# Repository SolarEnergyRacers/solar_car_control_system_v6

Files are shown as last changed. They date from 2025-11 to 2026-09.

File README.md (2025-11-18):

# solar_car_control_system_v6

[solarenergyracers.ch](https://www.solarenergyracers.ch) - control system (multi controller based control system for SER v6 solar car)

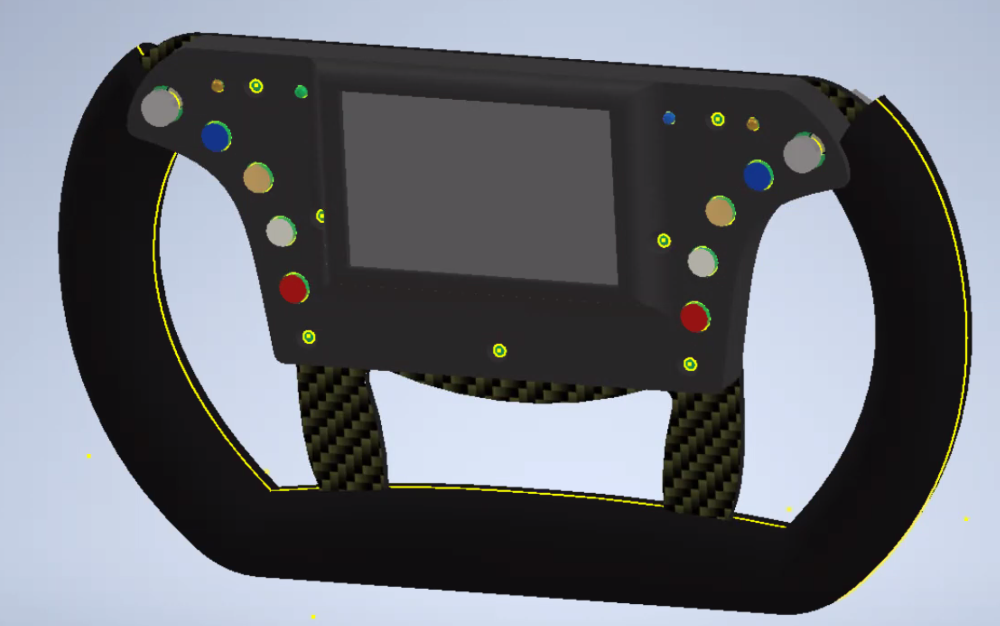
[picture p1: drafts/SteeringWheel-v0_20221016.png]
steering wheel


## Folder Structure

```Text
.
├── AC
│   ├── CMakeLists.txt
│   ├── dependencies.lock
│   ├── lib
│   │   ├── CarControl
│   │   ├── CarState
│   │   ├── CmdHandler
│   │   ├── ConfigReader
│   │   ├── Console
│   │   ├── definitions.h
│   │   ├── Display
│   │   ├── DisplayValue
│   │   ├── DriverDisplay
│   │   ├── EngineerDisplay
│   │   ├── GPIO
│   │   ├── interfaces
│   │   ├── LocalFunctionsAndDevices.h
│   │   ├── OneWireBus
│   │   ├── placeholder.txt
│   │   ├── SDCard
│   │   └── SPIBus
│   ├── platformio.ini
│   ├── sdkconfig
│   ├── sdkconfig.defaults
│   ├── sdkconfig.esp32dev
│   ├── sdkconfig.esp32dev-linux
│   ├── sdkconfig.esp32dev-windows
│   ├── ser_v6_AC.code-workspace
│   ├── src
│   │   ├── CMakeLists.txt
│   │   └── main.cpp
│   └── upload_no_build.py
├── archive_logs.py
├── data
├── datasheets
├── DC
│   ├── CMakeLists.txt
│   ├── dependencies.lock
│   ├── lib
│   │   ├── ADC
│   │   ├── CAN
│   │   ├── CarControl
│   │   ├── CarState
│   │   ├── CmdHandler
│   │   ├── ConstSpeed
│   │   ├── DAC
│   │   ├── definitions.h
│   │   ├── GPIO
│   │   ├── IOExt
│   │   ├── LocalFunctionsAndDevices.h
│   │   ├── OneWireBus
│   │   └── SPIBus
│   ├── platformio.ini
│   ├── sdkconfig
│   ├── sdkconfig.defaults
│   ├── sdkconfig.esp32dev
│   ├── sdkconfig.esp32dev-linux
│   ├── sdkconfig.esp32dev-windows
│   ├── ser_v6_DC.code-workspace
│   ├── src
│   │   ├── CMakeLists.txt
│   │   └── main.cpp
│   └── upload_no_build.py
├── PCBs
│   ├── AuxController
│   ├── ChassisBoard
│   ├── DriveController
│   ├── PDFs_Images
│   └── SwitchBoard
├── docs
├── drafts
├── extras
├── fixes_for_librarys
│   ├── core.h
│   ├── fixes.md
│   └── rtc.h
├── lib_common
│   ├── CAN
│   ├── Console
│   ├── Helper
│   ├── I2CBus
│   ├── include
│   ├── interfaces
│   ├── RTC
│   ├── Serial
│   └── System
├── platformio.txt
├── README.md
├── reset_usb_numbering.py
└── start-vscode-for-AC-DC-workspace.py

```

## Drafts

- SteeringWheel
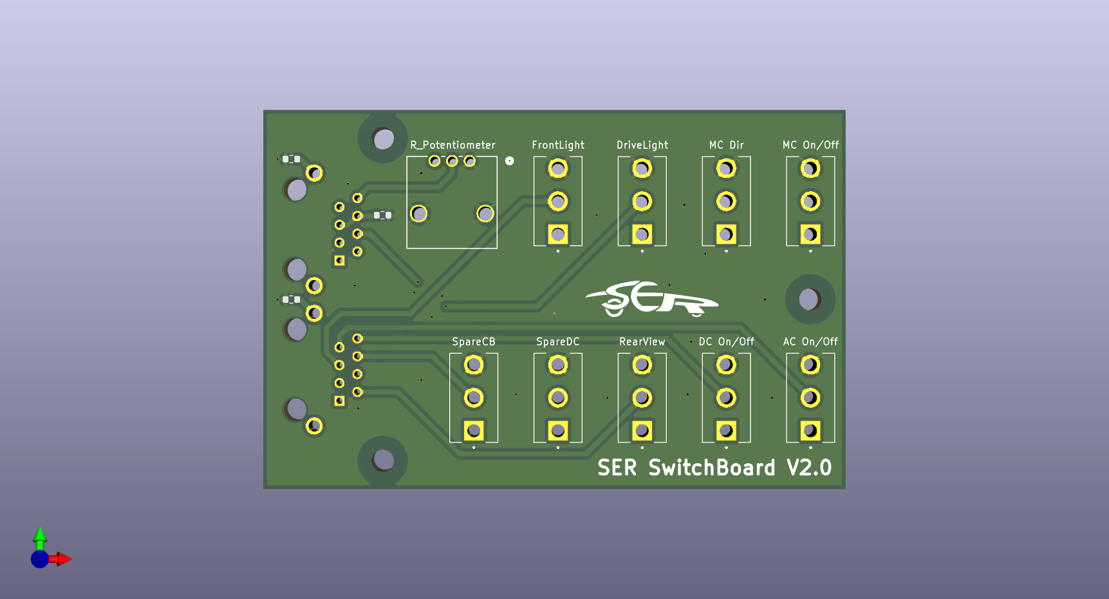
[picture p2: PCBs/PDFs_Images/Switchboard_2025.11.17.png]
Switchboard
- 
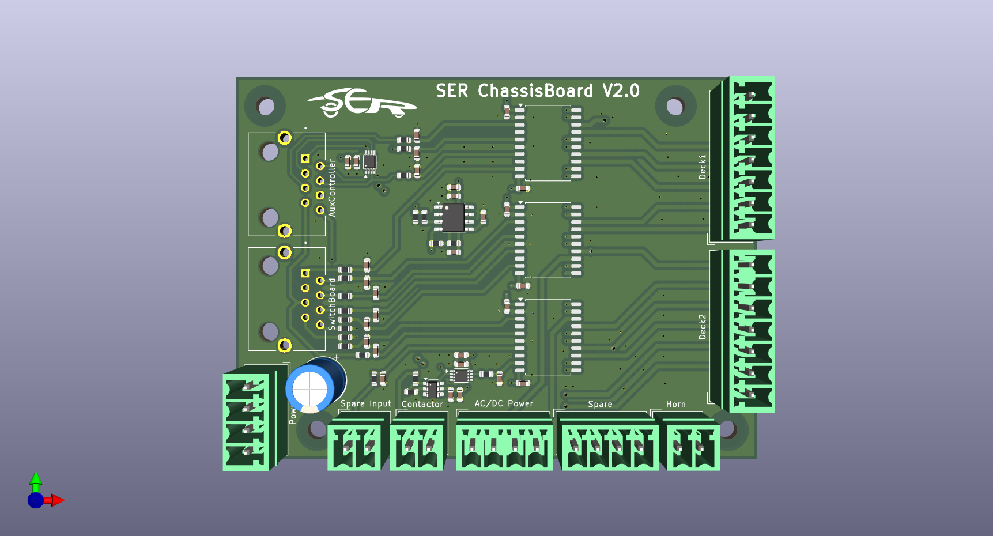
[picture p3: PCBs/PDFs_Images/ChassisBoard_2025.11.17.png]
ChassisBoard
- 
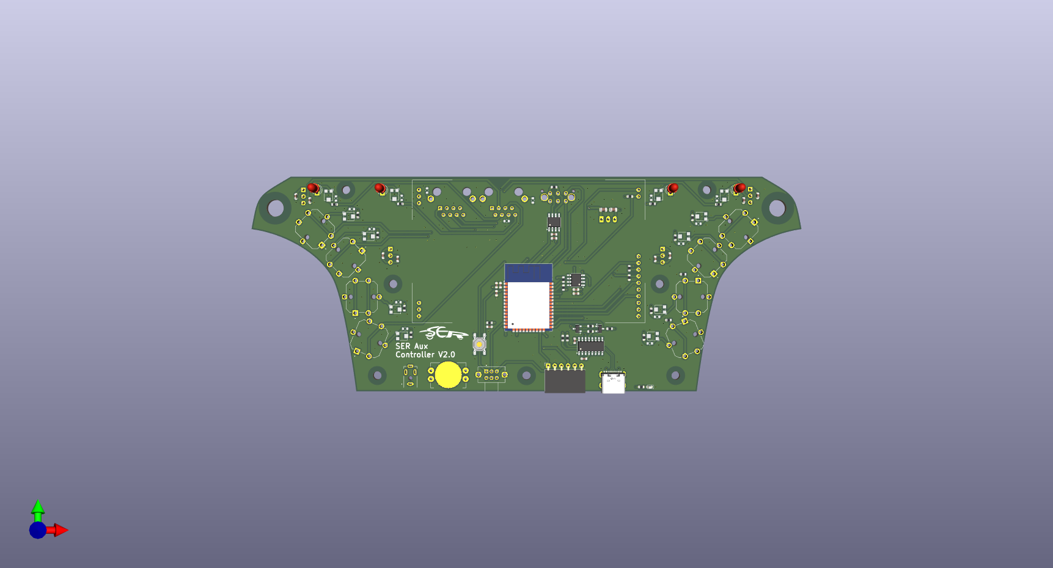
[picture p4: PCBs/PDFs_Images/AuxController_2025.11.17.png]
AuxController
- 
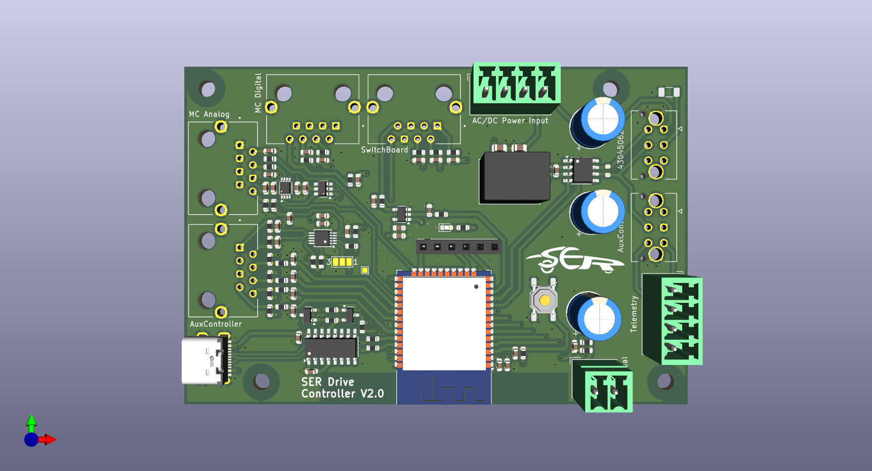
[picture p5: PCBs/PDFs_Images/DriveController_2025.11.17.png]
DriveController
- 

## Docs

- [Signal Flows](docs/SignalFlows.md)
- [CAN Signal](docs/SignalFlows_CAN-Definitions.md)

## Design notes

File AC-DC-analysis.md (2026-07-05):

# AC/DC Control System Reliability Analysis

## Scope

This document focuses on CAN communication reliability between AC and DC controllers in SER6.

Primary requirement:

- AC<->DC control exchange is critical and should not be silently lost.

Secondary requirement:

- Other CAN participants (BMS, MPPT, and additional telemetry) are informational. Packet loss is acceptable because data is sent repeatedly.

## Baseline

Main code locations:

- AC application: `AC/`
- DC application: `DC/`
- Shared CAN stack: `lib_common/CAN/`
- CAN constants: `lib_common/include/global_definitions.h`

Current CAN library in both AC and DC builds:

- `https://github.com/sandeepmistry/arduino-CAN`

Current bitrate:

- `CAN_SPEED = 125E3`

CAN base IDs in code:

- `AC_BASE_ADDR = 0x650`
- `DC_BASE_ADDR = 0x660`
- `BMS_BASE_ADDR = 0x700`
- `MPPT1/2/3_BASE_ADDR = 0x600/0x610/0x620`

## Reliability Classes

Class A (critical, must-not-lose behavior):

- `0x650` (`AC_BASE_ADDR | 0x00`) AC -> DC command/control frame
- `0x660` (`DC_BASE_ADDR | 0x00`) DC -> AC driver input frame
- `0x661` (`DC_BASE_ADDR | 0x01`) DC -> AC target/state frame

Class B (telemetry, loss tolerated):

- BMS frames
- MPPT frames
- Other repeated informational traffic

## Current Critical Data Flow

TX generation:

- AC writes `0x650` in `AC/lib/CarControl/CarControlAC.cpp`.
- DC writes `0x660` and `0x661` in `DC/lib/CarControl/CarControlDC.cpp`.

Transport:

- ISR receive callback in `lib_common/CAN/CANBus.cpp`.
- RX/TX queue handling in `lib_common/CAN/CANRxBuffer.cpp` and `lib_common/CAN/CANBus.cpp`.

RX consumption:

- AC parses `0x660` and `0x661` in `lib_common/CAN/CANBusHandlerAC.cpp`.
- DC parses `0x650` in `lib_common/CAN/CANBusHandlerDC.cpp`.

## Confirmed Findings

### Critical

1. RX queue overwrite can drop critical packets.

- File: `lib_common/CAN/CANRxBuffer.cpp`
- Behavior: oldest packet is removed when queue is full.
- Impact: class A and class B traffic are not separated, so critical frames can be dropped under pressure.

### High

1. TX failure path has no bounded retry policy for critical messages.

- File: `lib_common/CAN/CANBus.cpp`
- Behavior: semaphore timeout or `CAN.endPacket()` failure increments counters and returns.
- Impact: critical packet can be lost without immediate recovery.

1. Dedup logic can keep stale control state after a lost frame.

- File: `lib_common/CAN/CANBus.cpp`
- Behavior: unchanged payload is not re-enqueued unless `force` is true.
- Impact: if a critical frame is lost and value does not change, receiver can stay stale longer.

### Medium

1. Fixed TX service budget can increase queue latency.

- File: `lib_common/CAN/CANBus.cpp`
- Behavior: `MAX_TX_PACKETS_PER_CYCLE = 4`.
- Impact: bursts can delay control updates.

1. Priority handling exists but does not provide end-to-end QoS.

- File: `lib_common/CAN/CANBus.cpp`
- Behavior: critical IDs are prioritized in parts of TX scheduling.
- Impact: no complete guarantee model (critical reservation + retry + stale contract).

## Implementation Started

Implemented now in shared CAN code:

- Added queue overwrite visibility in `CANRxBuffer::push(...)` (returns whether overwrite happened).
- Added counters in `CANBus`:
  - `counterRxOverwrite`
  - `counterTxOverwrite`
  - `counterCriticalTxDrop`
  - `counterCriticalTxFail`
- Added critical TX failure counting for semaphore and `endPacket()` failures.
- Added bounded retry/requeue for critical TX IDs (`0x650`, `0x660`, `0x661`).
- Added critical frame staleness watchdog (`CRITICAL_CAN_STALE_TIMEOUT_MS`) with stale/recovered logs and counter.
- Migrated CAN backend implementation in `CANBus` from arduino-CAN to ESP-IDF TWAI.
- Added critical sequence-gap detection for IDs `0x650`, `0x660`, and `0x661`.
- Added dedicated critical TX queue lane so telemetry queue pressure cannot evict critical frames.
- Extended reinit log output to include new reliability counters.

Changed files:

- `lib_common/CAN/CANRxBuffer.h`
- `lib_common/CAN/CANRxBuffer.cpp`
- `lib_common/CAN/CANBus.h`
- `lib_common/CAN/CANBus.cpp`
- `lib_common/include/global_definitions.h`
- `AC/platformio.ini`
- `DC/platformio.ini`

## Library Assessment

### Previous library: arduino-CAN

Short-term suitability:

- Good integration and low change risk.
- Simple API and already in production code path.

Limitations against class A reliability target:

- Reliability/QoS policy must be implemented mostly in project code.
- Less explicit application-facing control for advanced error-state handling than native ESP-IDF TWAI APIs.

### Selected target: ESP-IDF TWAI backend

Decision implemented:

1. CAN transport in `CANBus` now uses ESP-IDF TWAI APIs.
1. Build dependencies for arduino-CAN were removed from AC/DC platformio config.

Rationale:

- Better error/state visibility.
- Better recovery integration.
- Better long-term fit for must-not-lose control path requirements.

## Next Implementation Steps

1. Add critical staleness timeout policy for `0x650`, `0x660`, and `0x661`.
1. Add optional backend abstraction layer only if dual-backend support is needed.

## Validation Gates

1. No undetected stale class A state beyond defined timeout budget.
2. Class A drop/failure counters visible during stress tests.
3. Injected TX failures trigger deterministic retry/recovery behavior.
4. Class B packet loss does not impact control correctness.

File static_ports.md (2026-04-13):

# Static USB Port Assignment for ESP32 Boards

## Check it

`ll /dev/ttyU* ; ll /dev/esp32-*`

## Explore it

```bash
udevadm info -a -n /dev/ttyUSB1 > ac.udevadm.log
udevadm info -a -n /dev/ttyUSB1 > dc.udevadm.log
code ac.udevadm.log dc.udevadm.log 
```

## Set it

```bash
sudo nano /etc/udev/rules.d/99-esp32.rules
```

```rules
# Rule for first ESP32 board (plugged into port with KERNELS 1-1.2)
SUBSYSTEM=="tty", ATTRS{idVendor}=="1a86", ATTRS{idProduct}=="7523", KERNELS=="1-2", SYMLINK+="esp32-ac"

# Rule for second ESP32 board (plugged into port with KERNELS 1-1.3)
SUBSYSTEM=="tty", ATTRS{idVendor}=="1a86", ATTRS{idProduct}=="7523", KERNELS=="1-1", SYMLINK+="esp32-dc"

```

```bash
sudo udevadm control --reload-rules && sudo udevadm trigger
```

If both ESP32 boards report identical attributes (e.g., the same ATTRS{serial}, ATTRS{idVendor}, and ATTRS{idProduct}), that's common for identical hardware. We can't rely on device-specific attributes for uniqueness, but we can use port-specific attributes from the USB hierarchy (like the physical USB port path) to distinguish them. This requires plugging each board into a different USB port and matching on the KERNELS or DEVPATH attribute, which represents the device's position in the USB tree.

Updated Steps to Create Unique udev Rules

Plug in only one ESP32 board to a specific USB port (e.g., the leftmost port on your hub or motherboard). Note which port you're using.

Identify the device and get full attributes:

Find the assigned /dev/ttyUSB* device:

`ls /dev/ttyUSB*`

(Assume it's /dev/ttyUSB0 for this example.)

Get the full udev info:

`udevadm info -a -n /dev/ttyUSB0`

Look for lines like:

```bash
KERNELS=="1-1.2"  # This is the USB port path (varies by port)DEVPATH=="/devices/pci0000:00/0000:00:14.0/usb1/1-1/1-1.2/1-1.2:1.0/ttyUSB0/tty/ttyUSB0"
The KERNELS value (e.g., 1-1.2) is key—it's unique to the physical port. Copy this value for the first board.
Unplug the first board, plug in the second board to a different USB port (e.g., the next port over). Repeat step 2 to get its KERNELS value (e.g., 1-1.3).
```

Create or update the udev rules file (as root):

`sudo nano /etc/udev/rules.d/99-esp32.rules`

Use the KERNELS values to make rules unique. Example (replace with your actual values):

```bash
# Rule for first ESP32 board (plugged into port with KERNELS 1-1.2)SUBSYSTEM=="tty", ATTRS{idVendor}=="1a86", ATTRS{idProduct}=="7523", KERNELS=="1-1.2", SYMLINK+="esp32-ac1"
# Rule for second ESP32 board (plugged into port with KERNELS 1-1.3)SUBSYSTEM=="tty", ATTRS{idVendor}=="1a86", ATTRS{idProduct}=="7523", KERNELS=="1-1.3", SYMLINK+="esp32-ac2"
```

If KERNELS isn't reliable (e.g., if ports are on different hubs), use DEVPATH instead (match the full path up to the tty device).
Save and exit.

Reload and test:

Reload rules:

`sudo udevadm control --reload-rules && sudo udevadm trigger`

## Static USB Ports for ESP32 Boards

Based on udevadm info for one ESP32 board (plugged into a specific port). Use KERNELS or other unique attributes to create udev rules for persistent naming.

**Note:** This log shows KERNELS=="1-1", which is the same as the first board. To distinguish, plug each board into different USB ports (e.g., different physical ports on your hub or motherboard) so KERNELS differs (e.g., 1-1 for one, 1-2 for the other).

---

Udevadm info starts with the device specified by the devpath and then
walks up the chain of parent devices. It prints for every device
found, all possible attributes in the udev rules key format.
A rule to match, can be composed by the attributes of the device
and the attributes from one single parent device.

```bash
  looking at device '/devices/pci0000:00/0000:00:14.0/usb1/1-1/1-1:1.0/ttyUSB1/tty/ttyUSB1':
    KERNEL=="ttyUSB1"
    SUBSYSTEM=="tty"
    DRIVER==""
    ATTR{power/async}=="disabled"
    ATTR{power/control}=="auto"
    ATTR{power/runtime_active_kids}=="0"
    ATTR{power/runtime_active_time}=="0"
    ATTR{power/runtime_enabled}=="disabled"
    ATTR{power/runtime_status}=="unsupported"
    ATTR{power/runtime_suspended_time}=="0"
    ATTR{power/runtime_usage}=="0"

  looking at parent device '/devices/pci0000:00/0000:00:14.0/usb1/1-1/1-1:1.0/ttyUSB1':
    KERNELS=="ttyUSB1"
    SUBSYSTEMS=="usb-serial"
    DRIVERS=="ch341-uart"
    ATTRS{port_number}=="0"
    ATTRS{power/async}=="enabled"
    ATTRS{power/control}=="auto"
    ATTRS{power/runtime_active_kids}=="0"
    ATTRS{power/runtime_active_time}=="0"
    ATTRS{power/runtime_enabled}=="disabled"
    ATTRS{power/runtime_status}=="unsupported"
    ATTRS{power/runtime_suspended_time}=="0"
    ATTRS{power/runtime_usage}=="0"

  looking at parent device '/devices/pci0000:00/0000:00:14.0/usb1/1-1/1-1:1.0':
    KERNELS=="1-1:1.0"
    SUBSYSTEMS=="usb"
    DRIVERS=="ch341"
    ATTRS{authorized}=="1"
    ATTRS{bAlternateSetting}==" 0"
    ATTRS{bInterfaceClass}=="ff"
    ATTRS{bInterfaceNumber}=="00"
    ATTRS{bInterfaceProtocol}=="02"
    ATTRS{bInterfaceSubClass}=="01"
    ATTRS{bNumEndpoints}=="03"
    ATTRS{physical_location/dock}=="no"
    ATTRS{physical_location/horizontal_position}=="right"
    ATTRS{physical_location/lid}=="no"
    ATTRS{physical_location/panel}=="left"
    ATTRS{physical_location/vertical_position}=="lower"
    ATTRS{power/async}=="enabled"
    ATTRS{power/runtime_active_kids}=="0"
    ATTRS{power/runtime_enabled}=="enabled"
    ATTRS{power/runtime_status}=="suspended"
    ATTRS{power/runtime_usage}=="0"
    ATTRS{supports_autosuspend}=="1"

  looking at parent device '/devices/pci0000:00/0000:00:14.0/usb1/1-1':
    KERNELS=="1-1"
    SUBSYSTEMS=="usb"
    DRIVERS=="usb"
    ATTRS{authorized}=="1"
    ATTRS{avoid_reset_quirk}=="0"
    ATTRS{bConfigurationValue}=="1"
    ATTRS{bDeviceClass}=="ff"
    ATTRS{bDeviceProtocol}=="00"
    ATTRS{bDeviceSubClass}=="00"
    ATTRS{bMaxPacketSize0}=="8"
    ATTRS{bMaxPower}=="98mA"
    ATTRS{bNumConfigurations}=="1"
    ATTRS{bNumInterfaces}==" 1"
    ATTRS{bcdDevice}=="0264"
    ATTRS{bmAttributes}=="80"
    ATTRS{busnum}=="1"
    ATTRS{configuration}==""
    ATTRS{devnum}=="33"
    ATTRS{devpath}=="1"
    ATTRS{idProduct}=="7523"
    ATTRS{idVendor}=="1a86"
    ATTRS{ltm_capable}=="no"
    ATTRS{maxchild}=="0"
    ATTRS{physical_location/dock}=="no"
    ATTRS{physical_location/horizontal_position}=="right"
    ATTRS{physical_location/lid}=="no"
    ATTRS{physical_location/panel}=="left"
    ATTRS{physical_location/vertical_position}=="lower"
    ATTRS{power/active_duration}=="14812"
    ATTRS{power/async}=="enabled"
    ATTRS{power/autosuspend}=="2"
    ATTRS{power/autosuspend_delay_ms}=="2000"
    ATTRS{power/connected_duration}=="14811"
    ATTRS{power/control}=="on"
    ATTRS{power/level}=="on"
    ATTRS{power/persist}=="1"
    ATTRS{power/runtime_active_kids}=="0"
    ATTRS{power/runtime_active_time}=="14304"
    ATTRS{power/runtime_enabled}=="forbidden"
    ATTRS{power/runtime_status}=="active"
    ATTRS{power/runtime_suspended_time}=="0"
    ATTRS{power/runtime_usage}=="1"
    ATTRS{product}=="USB Serial"
    ATTRS{quirks}=="0x0"
    ATTRS{removable}=="removable"
    ATTRS{remove}=="(not readable)"
    ATTRS{rx_lanes}=="1"
    ATTRS{speed}=="12"
    ATTRS{tx_lanes}=="1"
    ATTRS{urbnum}=="15"
    ATTRS{version}==" 1.10"

  looking at parent device '/devices/pci0000:00/0000:00:14.0/usb1':
    KERNELS=="usb1"
    SUBSYSTEMS=="usb"
    DRIVERS=="usb"
    ATTRS{authorized}=="1"
    ATTRS{authorized_default}=="1"
    ATTRS{avoid_reset_quirk}=="0"
    ATTRS{bConfigurationValue}=="1"
    ATTRS{bDeviceClass}=="09"
    ATTRS{bDeviceProtocol}=="01"
    ATTRS{bDeviceSubClass}=="00"
    ATTRS{bMaxPacketSize0}=="64"
    ATTRS{bMaxPower}=="0mA"
    ATTRS{bNumConfigurations}=="1"
    ATTRS{bNumInterfaces}==" 1"
    ATTRS{bcdDevice}=="0608"
    ATTRS{bmAttributes}=="e0"
    ATTRS{busnum}=="1"
    ATTRS{configuration}==""
    ATTRS{devnum}=="1"
    ATTRS{devpath}=="0"
    ATTRS{idProduct}=="0002"
    ATTRS{idVendor}=="1d6b"
    ATTRS{interface_authorized_default}=="1"
    ATTRS{ltm_capable}=="no"
    ATTRS{manufacturer}=="Linux 6.8.0-107-generic xhci-hcd"
    ATTRS{maxchild}=="12"
    ATTRS{power/active_duration}=="207132742"
    ATTRS{power/async}=="enabled"
    ATTRS{power/autosuspend}=="0"
    ATTRS{power/autosuspend_delay_ms}=="0"
    ATTRS{power/connected_duration}=="207132742"
    ATTRS{power/control}=="auto"
    ATTRS{power/level}=="auto"
    ATTRS{power/runtime_active_kids}=="4"
    ATTRS{power/runtime_active_time}=="207132725"
    ATTRS{power/runtime_enabled}=="enabled"
    ATTRS{power/runtime_status}=="active"
    ATTRS{power/runtime_suspended_time}=="0"
    ATTRS{power/runtime_usage}=="0"
    ATTRS{power/wakeup}=="disabled"
    ATTRS{power/wakeup_abort_count}==""
    ATTRS{power/wakeup_active}==""
    ATTRS{power/wakeup_active_count}==""
    ATTRS{power/wakeup_count}==""
    ATTRS{power/wakeup_expire_count}==""
    ATTRS{power/wakeup_last_time_ms}==""
    ATTRS{power/wakeup_max_time_ms}==""
    ATTRS{power/wakeup_total_time_ms}==""
    ATTRS{product}=="xHCI Host Controller"
    ATTRS{quirks}=="0x0"
    ATTRS{removable}=="unknown"
    ATTRS{remove}=="(not readable)"
    ATTRS{rx_lanes}=="1"
    ATTRS{serial}=="0000:00:14.0"
    ATTRS{speed}=="480"
    ATTRS{tx_lanes}=="1"
    ATTRS{urbnum}=="2228"
    ATTRS{version}==" 2.00"

  looking at parent device '/devices/pci0000:00/0000:00:14.0':
    KERNELS=="0000:00:14.0"
    SUBSYSTEMS=="pci"
    DRIVERS=="xhci_hcd"
    ATTRS{ari_enabled}=="0"
    ATTRS{broken_parity_status}=="0"
    ATTRS{class}=="0x0c0330"
    ATTRS{consistent_dma_mask_bits}=="64"
    ATTRS{d3cold_allowed}=="1"
    ATTRS{dbc}=="disabled"
    ATTRS{dbc_bInterfaceProtocol}=="01"
    ATTRS{dbc_bcdDevice}=="0010"
    ATTRS{dbc_idProduct}=="0010"
    ATTRS{dbc_idVendor}=="1d6b"
    ATTRS{dbc_poll_interval_ms}=="64"
    ATTRS{device}=="0x9d2f"
    ATTRS{dma_mask_bits}=="64"
    ATTRS{driver_override}=="(null)"
    ATTRS{enable}=="1"
    ATTRS{irq}=="130"
    ATTRS{local_cpulist}=="0-7"
    ATTRS{local_cpus}=="ff"
    ATTRS{msi_bus}=="1"
    ATTRS{msi_irqs/130}=="msi"
    ATTRS{msi_irqs/131}=="msi"
    ATTRS{msi_irqs/132}=="msi"
    ATTRS{msi_irqs/133}=="msi"
    ATTRS{msi_irqs/134}=="msi"
    ATTRS{msi_irqs/135}=="msi"
    ATTRS{msi_irqs/136}=="msi"
    ATTRS{msi_irqs/137}=="msi"
    ATTRS{numa_node}=="-1"
    ATTRS{power/async}=="enabled"
    ATTRS{power/control}=="auto"
    ATTRS{power/runtime_active_kids}=="2"
    ATTRS{power/runtime_active_time}=="207133325"
    ATTRS{power/runtime_enabled}=="enabled"
    ATTRS{power/runtime_status}=="active"
    ATTRS{power/runtime_suspended_time}=="0"
    ATTRS{power/runtime_usage}=="0"
    ATTRS{power/wakeup}=="enabled"
    ATTRS{power/wakeup_abort_count}=="0"
    ATTRS{power/wakeup_active}=="0"
    ATTRS{power/wakeup_active_count}=="0"
    ATTRS{power/wakeup_count}=="0"
    ATTRS{power/wakeup_expire_count}=="0"
    ATTRS{power/wakeup_last_time_ms}=="0"
    ATTRS{power/wakeup_max_time_ms}=="0"
    ATTRS{power/wakeup_total_time_ms}=="0"
    ATTRS{power_state}=="D0"
    ATTRS{remove}=="(not readable)"
    ATTRS{rescan}=="(not readable)"
    ATTRS{resource0}=="(not readable)"
    ATTRS{revision}=="0x21"
    ATTRS{subsystem_device}=="0x2259"
    ATTRS{subsystem_vendor}=="0x17aa"
    ATTRS{vendor}=="0x8086"

  looking at parent device '/devices/pci0000:00':
    KERNELS=="pci0000:00"
    SUBSYSTEMS==""
    DRIVERS==""
    ATTRS{power/async}=="enabled"
    ATTRS{power/control}=="auto"
    ATTRS{power/runtime_active_kids}=="11"
    ATTRS{power/runtime_active_time}=="0"
    ATTRS{power/runtime_enabled}=="disabled"
    ATTRS{power/runtime_status}=="unsupported"
    ATTRS{power/runtime_suspended_time}=="0"
    ATTRS{power/runtime_usage}=="0"
    ATTRS{waiting_for_supplier}=="0"
```

## Example udev Rules

Based on this output, use KERNELS=="1-1" (from the parent device) combined with idVendor/idProduct for matching. For the second board, plug it into a different port to get a different KERNELS (e.g., 1-2).

```bash
# /etc/udev/rules.d/99-esp32.rules
SUBSYSTEM=="tty", ATTRS{idVendor}=="1a86", ATTRS{idProduct}=="7523", KERNELS=="1-1", SYMLINK+="esp32-ac1"
# For second board: SUBSYSTEM=="tty", ATTRS{idVendor}=="1a86", ATTRS{idProduct}=="7523", KERNELS=="1-2", SYMLINK+="esp32-ac2"
```

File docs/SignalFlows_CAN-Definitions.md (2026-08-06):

# Signals and Media in SER V6

Version 
- 2023.01.01
- 2026.08.01

[github: issues from SER v3](https://github.com/SolarEnergyRacers/solar_car_control_system_v3/issues/)  
[github: issues from SER v6](https://github.com/SolarEnergyRacers/solar_car_control_system_v6/issues/)

## Device Base Addresses

| Device | Used | Address |
| --- | ---- | --- |
| [MC_BASE_ADDR](#mc---motor-controller) | ❌ | **0x500** |
| [MPPT1_BASE_ADDR](#mppt---maximum-power-point-tracking) | ✅ | **0x600** |
| [MPPT2_BASE_ADDR](#mppt---maximum-power-point-tracking) | ✅ | **0x610** |
| [MPPT3_BASE_ADDR](#mppt---maximum-power-point-tracking) | ✅ | **0x620** |
| [MPPT4_BASE_ADDR](#mppt---maximum-power-point-tracking) | ✅ | **0x630** |
| [AC_BASE_ADDR](#ac---auxiliary-controller) | ✅ | **0x650** |
| [DC_BASE_ADDR](#dc---drive-controller) | ✅ | **0x660** |
| [BMS_BASE_ADDR](#bms---battery-management-system) | ✅ | **0x700** |
  
## Communication between Parts
### Communication AC - DC

| AC (auxiliary controller) | Dir | Type | DC (drive controller) |
| --- | --- | --- | --- |
| HAL-paddle Acceleration | > | analog 0-5V | carStateDC ➡ MC |
| HAL-paddle Deceleration | > | analog 0-5V | carStateDC ➡ MC |
| Button Level Plus | > | binary 0/1  | carStateDC |
| Button Level Minus | > | binary 0/1  | carStateDC |
| carStateAC -> Display Speed | < | CAN | current speed ⬅ MC |
| Console input PID parameters | > | CAN | carConfigDC? carStateDC |
| Button Set Constant Mode | < | CAN | carStateDC |
| Button Reset Constant Mode | < | CAN | carStateDC |
| Button Constant Mode speed/power | > | CAN | carStateDC |
| Break pedal state | < | CAN | carStateDC |
| Step width Plus/Minus | < | CAN | carStateDC ⬅ Switchboard Poti |

### Communication SwitchBoard - DC

| SwitchBoard | Dir | Type | DC (drive controller) |
| --- | --- | --- | --- |
| Potentiometer (step width?) | > | analog 0-5V | carStateDC ➡ MC |

### Communication MC - DC

| MC (motor controller) | Dir | Type | DC (drive controller) |
| --- | --- | --- | --- |
| Acceleration | > | anlaog 0-5V | |
| Deceleration | > | analog 0-5V | |
| Speed | < | analog 0-5V | |

> look below for MC - CAN packets

### Communication BMS - MC

[BMS Comm Documentation](https://github.com/SolarEnergyRacers/solar_car_control_system_v3/blob/add_comm_documentation/docs/PRH67.010v2-BMS-BMU-Communications-Protocol.pdf)

| BMS (battery management system) | Dir | Type | DC (drive controller) |
| --- | --- | ---- | --- |
| (see docs) | > | CAN  | |

### Communication MPPT - MC

[MPPT Documentation](https://github.com/SolarEnergyRacers/solar_car_control_system_v3/blob/add_comm_documentation/docs/Elmar_Solar_MPPT.pdf)

| MPPT (maximum power point tracker) | Dir | Type | DC (drive controller) |
| --- | --- | ---- | --- |
| (see docs) | > | CAN  | |

### Communication AC - ChaseCar
#### Envelope, Encoding

Forward some CAN Frames, ~~encoded as ASCII chars~~
The id (11 bits) and data (64 bits) parts of the CAN frame get transmitted

The id is encoded into two chars, aligned by least significant bit.
The 5 unused bits are set to 1 to make the start of the CAN frame easier to identify.

| char 0 | char 1 |
| --- | --- |
| 11111abc | defghijk |

a = MSB  
k = LSB

```text
Raw forwarded CAN frame
+----------------------+----------------------------------+
| CAN ID (11 bits)     | DATA (64 bits)                   |
+----------------------+----------------------------------+
| id10 ... id0         | b63 b62 ... b1 b0                |
+----------------------+----------------------------------+

Serialized ID envelope (2 chars, LSB aligned)
+----------+----------+
| char 0   | char 1   |
+----------+----------+
|11111abc  |defghijk  |
+----------+----------+
      a = id10 (MSB)
      ...
      k = id0  (LSB)
```

Worked example (CAN ID = 0x661):

```text
11-bit ID (id10..id0): 11001100001

Mapping:
      abc      = 110
      defghijk = 01100001

Serialized chars:
      char0 = 11111abc  = 11111110 = 0xFE
      char1 = defghijk  = 01100001 = 0x61

Reconstruct ID:
      id = ((char0 & 0x07) << 8) | char1
             = ((0xFE  & 0x07) << 8) | 0x61
             = (0x06 << 8) | 0x61
             = 0x661
```

Data frame partitions (64-bit payload):

```text
┌───────────────────┬───────────────────────────────────────────────────────────────┐
│ 64-bit partition  │                              [0]                              │
│ (u64, i64)        ├───────────────────────────────────────────────────────────────┤
│              bit  │63                            ···                             0│
├───────────────────┼───────────────────────────────┬───────────────────────────────┤
│ 32-bit partition  │            [1]                │            [0]                │
│ (u32, i32, f32)   ├───────────────────────────────┼───────────────────────────────┤
│              bit  │63         ...               32│31                         ...0│
├───────────────────┼───────────────┬───────────────┼───────────────┬───────────────┤
│ 16-bit partition  │      W3       │      W2       │      W1       │      W0       │
│ (u16, i16)        ├───────────────┼───────────────┼───────────────┼───────────────┤
│              bit  │63    ...    48│47    ...    32│31    ...    16│15    ...     0│
├───────────────────┼───────┬───────┼───────┬───────┼───────┬───────┼───────┬───────┤
│ 8-bit partition   │  B7   │  B6   │  B5   │  B4   │  B3   │  B2   │  B1   │  B0   │
│ (u8, i8)          ├───────┼───────┼───────┼───────┼───────┼───────┼───────┼───────┤
│              bit  │63...56│55...48│47...40│39...32│31...24│23...16│15... 8│7 ... 0│
├───────────────────┼───────┴───────┴───────┴───────┴───────┴───────┴───────┴───────┤
│ 1-bit partition   │b63                      ...                                 b0│
│ (b64 as uint64_t) ├───────────────────────────────────────────────────────────────┤
│              bit  │63                       ···                                  0│
└───────────────────┴───────────────────────────────────────────────────────────────┘
                     MSB  ◄───────────────────────────────────────────────────►  LSB
```

#### Data Frames

The CAN frames to be transmitted are configured in property `radio_packets` of class `CarStateRadio`.

CarStateRadio send path (from CAN RX / AC local packet to radio serial):

```text
Incoming CANPacket(id, data[8])
                                          │
                                          ▼
push_if_radio_packet(adr, packet)
                                          │ if adr is in radio_packets
                                          ▼
packet_cache[adr] = packet
                                          │
                                          │ (same adr overwrites older packet)
                                          ▼
send_binary() / send_ascii()
                                          │
                                          ▼
for each cache entry (sorted by CAN ID):
      CANPacket::to_serial(adr, buffer[11])
      Serial2.write(...)  or  Serial2.print(hex...)
```

Serialized radio frame (one forwarded CAN packet):

```text
Radio TX frame (11 bytes total)
┌───────────────────────────┬───────────────────────────────────────────────────────┬──────────┐
│ ID envelope (2 bytes)     │ CAN payload (8 bytes)                                 │Terminator│
├───────────────┬───────────┼──────┬──────┬──────┬──────┬──────┬──────┬──────┬──────┼──────────┤
│ byte 0        │ byte 1    │ B0   │ B1   │ B2   │ B3   │ B4   │ B5   │ B6   │ B7   │ byte 10  │
│ char0 (FE..FF)│ char1     │      │      │      │      │      │      │      │      │ '\n'     │
└───────────────┴───────────┴──────┴──────┴──────┴──────┴──────┴──────┴──────┴──────┴──────────┘

ID envelope bits:
      char0 = 11111abc   (a..c = id10..id8)
      char1 = defghijk   (d..k = id7..id0)
```

Radio TX payload bytes `B0..B7`:

```text
CAN payload byte map (inside Radio TX frame)
┌─────────┬───────────┬────────────────────────────┬────────────────────────────────┐
│ Symbol  │ Bit range │ Position in 64-bit payload │ Meaning                        │
├─────────┼───────────┼────────────────────────────┼────────────────────────────────┤
│ B0      │   7..0    │ data_u8[0] / least-signif. │ Raw CAN data byte 0 (LSB side) │
│ B1      │  15..8    │ data_u8[1]                 │ Raw CAN data byte 1            │
│ B2      │  23..16   │ data_u8[2]                 │ Raw CAN data byte 2            │
│ B3      │  31..24   │ data_u8[3]                 │ Raw CAN data byte 3            │
│ B4      │  39..32   │ data_u8[4]                 │ Raw CAN data byte 4            │
│ B5      │  47..40   │ data_u8[5]                 │ Raw CAN data byte 5            │
│ B6      │  55..48   │ data_u8[6]                 │ Raw CAN data byte 6            │
│ B7      │  63..56   │ data_u8[7] / most-signif.  │ Raw CAN data byte 7 (MSB side) │
└─────────┴───────────┴────────────────────────────┴────────────────────────────────┘

Interpretation rule:
      B0..B7 are forwarded unchanged from the original CAN frame.
      Their semantic meaning depends on CAN ID (see per-message tables below).
```

Configured packet set in `radio_packets` (AC/lib/CarState/CarStateRadio.h):

```text
Mandatory (selected examples)
┌───────────────────────────────┬─────────────────────────────────────┐
│ Group                         │ IDs                                 │
├───────────────────────────────┼─────────────────────────────────────┤
│ DC                            │ DC_BASE+0x00, DC_BASE+0x01          │
│ AC                            │ AC_BASE+0x00                        │
│ MPPT outputs                  │ MPPT[1..4]_BASE+0x01                │
│ BMS telemetry/status          │ BMS_BASE+0x00..0x0C, +0xF4..0xFD    │
└───────────────────────────────┴─────────────────────────────────────┘

Nice-to-have
┌───────────────────────────────┬─────────────────────────────────────┐
│ Group                         │ IDs                                 │
├───────────────────────────────┼─────────────────────────────────────┤
│ MPPT extra                    │ MPPT[1..4]_BASE+0x00, +0x02         │
│ BMS extra                     │ BMS_BASE+0x01, +0x02                │
└───────────────────────────────┴─────────────────────────────────────┘
```

| AC | Dir | Type | ChaseCar |
| --- | --- | --- | --- |
| MPPT Outputs (MPPT Base+1) | > | CAN* | |
| BMS min/max Voltage (BMS Base+F8) | > | CAN* | |
| BMS min/max Temp (BMS Base+F9) | > | CAN* | |
| BMS voltage & current (BMS Base+FA) | > | CAN* | |
| BMS extended status (BMS Base+FD) | > | CAN* | |
| DC Speed, Accel., buttons (0x661) | > | CAN* | |
| AC Display Data (0x630) | > | CAN* | |
| | < > | Serial(text) | CommandHandler cmds |

##### nice-to-haves

| AC | Dir | Type | ChaseCar |
| --- | --- | ---- | --- |
| MPPT Inputs (MPPT Base+0) | > | CAN* | |
| MPPT Status (MPPT Base+3) | > | CAN* | |
| BMS cell Voltages (BMS Base+[1..]) | > | CAN* | |

\* CAN frames encoded to ASCII chars, transmitted over serial

## DC Data

- PID parameters
- Setpoint speed
- Setpoint power
- Current speed
- Current acceleration
- Current decceleration

## AC Data

### Display

- Speed + Speed unit (km/h)
- Acceleration/Deceleration (with unit %)
- Setpoint speed (km/h) or power (kW) + Setpoint type (speed/power showed by the unit)
- Driver info lines
- Drive direction
- Light mode
- PV on/off + PV current (A)
- Battery on/off + Battery voltage (V)
- Battery max, temperature (°C)

### Direct Signals

- Locking button for left/right/hazard warn indicators
- LEDs for left/right/hazard warn indicators
- Horn
- HAL sensors for paddles (to DC)
- buttons for plus/minus (to DC)
- Break pedal (to DC)

## CAN Signals
### BMS - Battery Management System

BMS_BASE_ADDR: **0x700**

(see docs)

### MPPT - Maximum Power Point Tracking

MPPT1_BASE_ADDR: **0x600**
MPPT2_BASE_ADDR: **0x610**
MPPT3_BASE_ADDR: **0x620**
MPPT4_BASE_ADDR: **0x630**
(see docs)

### DC - Drive Controller

DC_BASE_ADDR: **0x660**

#### CAN Address Offset: 0x00 - Speed Control

Interval: 1000ms

| Format | IdxFmt | Index8 | Meaning |
| --- | --- | --- | --- |
| u_16 | [0] | 0,1 | LifeSign |
| u_8 | [2] | 2 | Kp |
| u_8 | [3] | 3 | Ki |
| u_8 | [4] | 4 | Kd |

| b_33   | [33]   | 5      | ConstantMode: true-SPEED, false-POWER |

#### CAN Address Offset: 0x01 - Speed, Acceleration, buttons

Interval: 1000ms

| Format | IdxFmt | Index8 | Meaning |
| --- | --- | --- | --- |
| u_16 | [1] | 0,1 | Target Speed  [float as value\*1000] |
| u_16 | [3] | 2,3 | Target Power  [float as value\*1000] |
| i_8 | [4] | 4 | Display Acceleration |
| u_8 | [5] | 5 | Display Speed |
| u_8 | [6] | 6 | Drive |
| b | [56] | 7 | Fwd [1] / Bwd [0] |
| b | [57] | 7 | Button Lvl Brake Pedal |
| b | [58] | 7 | MC Off [0] / On [1] |
| b | [59] | 7 | ConstantModeOn |
| b | [60] | 7 | ConfirmDriverInfo |
| b | [61] | 7 | |
| b | [62] | 7 | |
| b | [63] | 7 | |

#### CAN Address Offset: 0x02 - Motor, Bat, PV

Interval: ?ms

| Format | IdxFmt | Index8 | Meaning |
| --- | --- | --- | --- |
| u_16 | [1] | 0,1 | Motor current |???
| u_16 | [2] | 2,3 | Battery voltage |
| u_16 | [3] | 4,5 | PV voltage |
| b | [48] | 6 | Motor On [1] / Off [0] |
| b | [49] | 6 | Bat On [1] / Off [0] |
| b | [51] | 6 | PV On [1] / Off [0] |

### AC - Auxiliary Controller

AC_BASE_ADDR: **0x640**

#### CAN Address Offset: 0x00 - Display Data

Interval: 1000ms

| Format | IdxFmt | Index8 | Meaning |
| --- | --- | --- | --- |
| u_16 | [0] | 0,1 | LifeSign |
| u_8 | [2] | 2 | Kp [int (float * 100)] |
| u_8 | [3] | 3 | Ki [int (float * 100)] |
| u_8 | [4] | 4 | Kd [int (float * 100)] |
| u_8 | [5] | 4 | GlideMode |
| b_33 | [33] | 5 | ConstantMode: true-SPEED, false-POWER |

### MC - Motor Controller

MC_BASE_ADDR: **0x500**

Intervall: 1000ms

MC CAN description: [github.com/vedderb/bldc/blob/master/documentation/comm_can.md](https://github.com/vedderb/bldc/blob/master/documentation/comm_can.md#status-commands)

| **Command Name** | **Command Id** | **Content** |
| --- | --- | --- |
| CAN_PACKET_STATUS | 9 (0x09) | ERPM, Current, Duty Cycle |
| CAN_PACKET_STATUS_2 | 14 (0x0e) | Ah Used, Ah Charged |
| CAN_PACKET_STATUS_3 | 15 (0x0f) | Wh Used, Wh Charged |
| CAN_PACKET_STATUS_4 | 16 (0x10) | Temp Fet, Temp Motor, Current In, PID position |
| CAN_PACKET_STATUS_5 | 27 (0x1b) | Tachometer, Voltage In |
| ~~CAN_PACKET_STATUS_6~~ | ~~28 (0x1c)~~  | ~~ADC1, ADC2, ADC3, PPM~~ |

The content of the status messages is encoded as follows:

**CAN_PACKET_STATUS**

| **Byte** | **Data** | **Unit** | **Scale** |
| --- | --- | --- | --- |
| B0 - B3  | ERPM | RPM | 1 |
| B4 - B5  | Current | A | 10 |
| B6 - B7  | Duty Cycle | % / 100  | 1000 |

**CAN_PACKET_STATUS_2**

| **Byte** | **Data** | **Unit** | **Scale** |
| --- | --- | --- | --- |
| B0 - B3  | Amp Hours | Ah | 10000 |
| B4 - B7  | Amp Hours Chg | Ah | 10000 |

**CAN_PACKET_STATUS_3**

| **Byte** | **Data** | **Unit** | **Scale** |
| --- | --- | --- | --- |
| B0 - B3  | Watt Hours | Wh | 10000 |
| B4 - B7  | Watt Hours Chg | Wh | 10000 |

**CAN_PACKET_STATUS_4**

| **Byte** | **Data** | **Unit** | **Scale** |
| --- | --- | --- | --- |
| B0 - B1  | Temp FET | DegC | 10 |
| B2 - B3  | Temp Motor | DegC | 10 |
| B4 - B5  | Current In | A | 10 |
| B6 - B7  | PID Pos | Deg | 50 |

**CAN_PACKET_STATUS_5**

| **Byte** | **Data** | **Unit** | **Scale** |
| --- | --- | --- | --- |
| B0 - B3  | Tachometer | EREV | 6 |
| B4 - B5  | Volts In | V | 10 |

~~**CAN_PACKET_STATUS_6**~~

| ~~**Byte**~~ | ~~**Data**~~ | ~~**Unit**~~ | ~~**Scale**~~ |
| --- | --- | --- | --- |
| ~~B0 - B1~~  | ~~ADC1~~ | ~~V~~ | ~~1000~~ |
| ~~B2 - B3~~  | ~~ADC2~~ | ~~V~~ | ~~1000~~ |
| ~~B4 - B5~~  | ~~ADC3~~ | ~~V~~ | ~~1000~~ |
| ~~B6 - B7~~  | ~~PPM~~ | ~~% / 100~~  | ~~1000~~ |

### Convert MC - CAN Address

```text
===============
14:19:48.187 > C0-474-[I:04|117,O:00|07]=R=Id=0x 624-data: 40e0000042e2cccd -- 40 - e0 - 00 - 00 - 42 - e2 - cc - cd
---------------
14:19:48.209 > C0-474-[I:06|117,O:00|07]=R=Id=0x 950-data: 0000000000000000 -- 00 - 00 - 00 - 00 - 00 - 00 - 00 - 00
14:19:48.209 > C0-474-[I:05|117,O:00|07]=R=Id=0x e50-data: 0000000000000000 -- 00 - 00 - 00 - 00 - 00 - 00 - 00 - 00
14:19:48.209 > C0-474-[I:04|117,O:00|07]=R=Id=0x f50-data: 0000000000000000 -- 00 - 00 - 00 - 00 - 00 - 00 - 00 - 00
14:19:48.232 > C0-474-[I:03|117,O:00|07]=R=Id=0x1050-data: 7e360000fc030001 -- 7e - 36 - 00 - 00 - fc - 03 - 00 - 01
14:19:48.232 > C0-474-[I:02|117,O:00|07]=R=Id=0x1b50-data: 0000ea0301000000 -- 00 - 00 - ea - 03 - 01 - 00 - 00 - 00
---------------
14:19:48.254 > C0-474-[I:01|117,O:00|07]=R=Id=0x7f8-data: 060400010e3b0e2e -- 06 - 04 - 00 - 01 - 0e - 3b - 0e - 2e
===============

Eingestellt MC: 0x50 

1b50
 51b
       5     1    b  
11111xxx  xxxx xxxx
```

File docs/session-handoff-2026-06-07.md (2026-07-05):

# Session Handoff (2026-06-07)

## Branch and Commit

- Branch: `fix/new-can-library`
- Latest committed change: `68a9dbf` (`CAN: migrate to TWAI and harden critical AC/DC reliability`)

## Current Uncommitted Changes

- `lib_common/CAN/CANBus.cpp`
- `lib_common/CAN/CANBus.h`

Purpose of these uncommitted changes:

- Set TWAI interrupt flags to shared low/medium priority:
  - `ESP_INTR_FLAG_LOWMED | ESP_INTR_FLAG_SHARED`
- This addresses DC boot abort:
  - `ESP_ERR_NOT_FOUND` in `twai_driver_install` during interrupt allocation.

## Observed Runtime Symptoms

- DC crash after startup in `twai_driver_install` with `ESP_ERR_NOT_FOUND`.
- AC keeps printing `CAN transmit timeout/fail (W_notAvail=...)` while DC is down.

## Resume Checklist After Reboot

1. Open repository and switch branch:
   - `git checkout fix/new-can-library`
2. Verify state:
   - `git status --short --branch`
3. Build/flash DC first and verify it passes CAN init.
4. Start AC and confirm `W_notAvail` no longer increments continuously.
5. If stable, commit current uncommitted fix with message:
   - `CAN: use shared lowmed TWAI interrupt flags to avoid startup abort`

## Notes

- PlatformIO CLI in this environment previously failed to run (`resultcallback` mismatch), so build validation may need your local known-good setup.

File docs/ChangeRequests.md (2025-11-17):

# Change Requests SER5

[[_TOC_]]

## Hardware
### General
- [ ] Jumper to select USB / DC converter for PCB power
- [ ] Indifference to startup order (current issue: paddle calibration on startup)
- [ ] Fix ground or EMC issues (spurious greenlight)

### Steering Wheel & AC Board
- [ ] Replace indicator pushbuttons with kip switches ([Git-Issue](https://github.com/SolarEnergyRacers/solar_car_control_system_v3/issues/10))
  *done with version:* 
- [ ] Drive Light LED and Front Light LED too bright ([Git-Issue](https://github.com/SolarEnergyRacers/solar_car_control_system_v3/issues/11))
  *done with version:* 
- [x] Need a DI Pin for SD-Card detected --> wire from display pin XX to CPU I35 (IO35)
  *done with version:* V5
- [x] How we signal the drive direction to the driver (Driver Display!)
  *done with version:* V3
- [ ] Battery On/Off - feedback missing
  *done with version:* 
- [ ] PV On/Off - switch **and** feedback missing
  *done with version:* 
- [ ] Motor current missing
  *done with version:* 
- [ ] Where the radio is connected?
  *done with version:* 
- [ ] Schematic: 1VMC but board print: 5VMC?
  *done with version:* 

### DC Board

- [ ] .
  *done with version:* 

### Connector Board

- [ ] .
  *done with version:* 

### Switches Board

- [ ] .
  *done with version:* 

## Software

### AC & DC

- [x] Use global sources where possible (no duplicates in AC and DC)
    *done with version:* v5

- [x] More sensible paddles  
  *done with version:* v5
- [x] auto adjust of paddles during startup
  *done with version:* v5

### AC

- [x] improve SD card handling
  *done with version:* v5 
- [ ] implement handshake / feedback / heartbeat for telemetry (driver text line)
- [ ] improve visibility of driver text line

### DC

- [ ] .
  *done with version:*

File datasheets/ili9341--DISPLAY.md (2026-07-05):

# ILI 9341

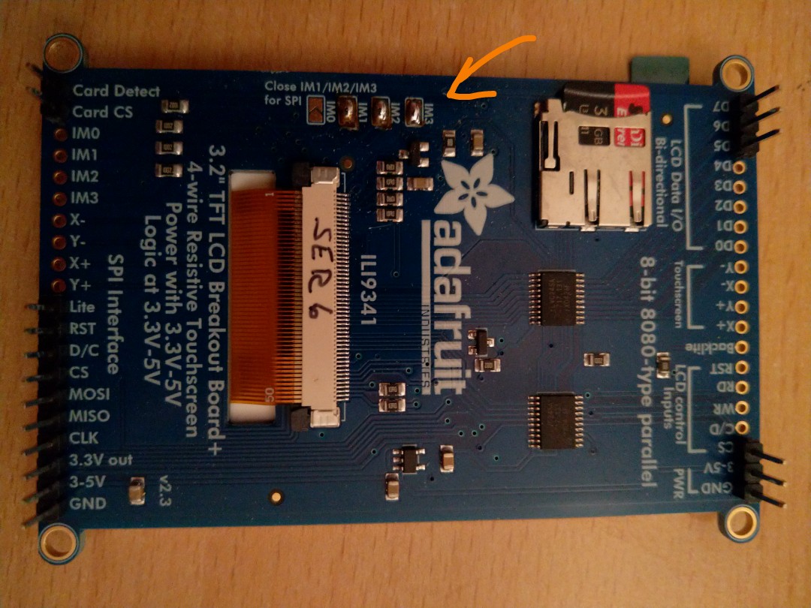
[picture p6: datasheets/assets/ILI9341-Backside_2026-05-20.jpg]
Backside


[ili9341 schema](https://learn.adafruit.com/adafruit-2-8-and-3-2-color-tft-touchscreen-breakout-v2/downloads)

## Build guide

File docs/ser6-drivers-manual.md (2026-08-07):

# Drivers Manual SER V6

[[_TOC_]]

## Preparation

## Control Elements

### Mainboard

(nothing to do by the driver)

### Emergency Controls

TODO: DESCRIBE IT!

### Switch Board

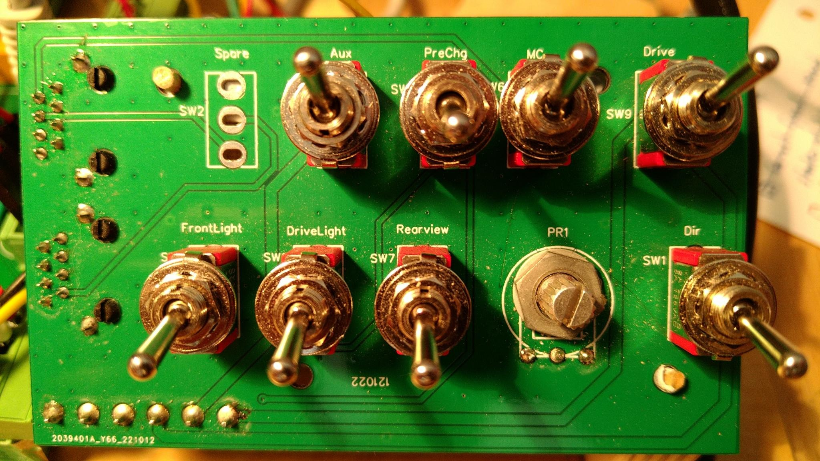
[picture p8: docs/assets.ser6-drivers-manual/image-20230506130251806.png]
switch board


| Switch Name | Function (what is switched) | Driver Screen / Steering Wheel | Engineer Screen |
| --- | --- | --- | --- |
| Spare | - | - | - |
| Aux | AC (auxiliary controller) power on (up) / off (down) | % | % |
| PreChg | | no | no |
| MC | MC (motor controller)  power on/off | yes<br />(right from Motor current) | yes |
| Drive | DC (drive controller) power on (up) / off (down) | % | % |
| FrontLight  | | Right blue LED | |
| DriveLight  | | Left green LED | |
| Rearview | Rear view camera power on (up) / off (down) | no | no |
| PR1 | Aggressiveness / sensitivity of the PLUS/MINUS buttons | yes<br />(below target speed) | no |
| Dir | Drive direction forward / backward | yes if backward<br />(red above target speed)<br />➡️ stops const mode | no |

### Steering Wheel

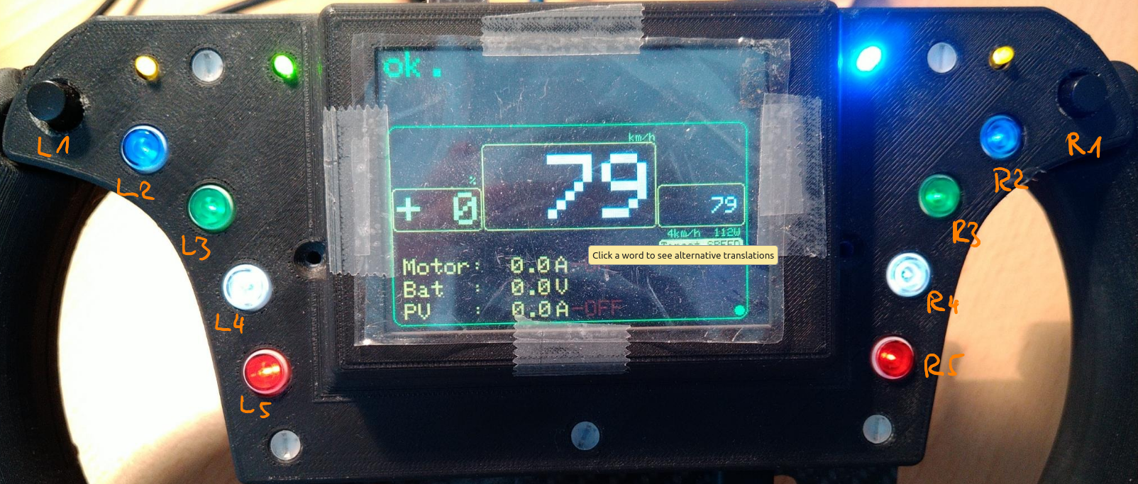
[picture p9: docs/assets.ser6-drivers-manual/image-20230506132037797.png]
steering wheel


| Button | Name | Function |
| --- | --- | --- |
| L1 | left indicator | on/off |
| R1 | right indicator | on/off |
| L1+R1  | Hazard warning lights | on/off |
| L2 | MINUS | decreases acceleration, switch on constant mode, current speed/power is overtaken as target speed |
| R2 | PLUS | increases acceleration, switch on constant mode, current speed/power is overtaken as target speed |
| L3 | confirm | confirm that the driver has read the info text (send the confirm back to the AC and radio) |
| R3 | const. on | switches on the constant mode, overtake last used target speed/power |
| L4 | SPEAK | driver speak button for radio communication |
| R4 | Const/Mount | Driver screen: switches between speed and power constant mode<br />Engineer screen: mounts or unmounts the sd-card |
| L5 | Horn | blows the cattle off the road |
| R5 | Next Screen | switches between Driver and Engineer screen |

## Car Start

### Boot Screen

The bootscreen with black font on white background shows the initialization of all devices controlled by the AC car control system.

At least the display holds for a few seconds countdown to allow an additional check of the values.

### Main Driver Screen

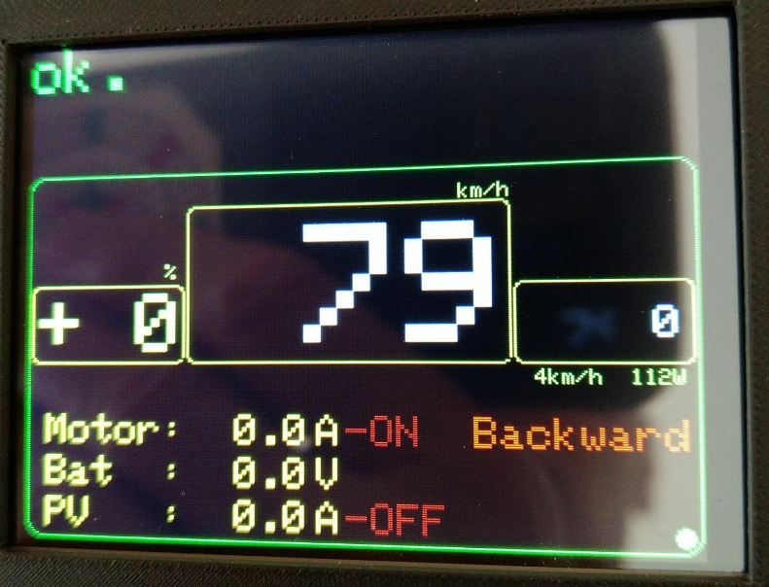
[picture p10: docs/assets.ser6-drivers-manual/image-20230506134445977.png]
driver screen


| Text | Meaning |
| --- | --- |
| ok. | |
| No DC connection! | Drive Controller not running or no data connection. |

In the left buottom corner ther is a life time indicator

- Dark green / green blinking: AC-DC-Connection ok
- contant light: connection broken
- Red light

### Engineering Screen

TODO

### Control Mode

| Button | Function |
| --- | --- |
| PLUS | decrease deceleration (recuperation) ... increase acceleration |
| MINUS | decrease acceleration ... increase deceleration (recuperation) |
| Break press | max break deceleration (recuperation) |
| Break release | set acceleration to 0 (neither recuperation nor acceleration)  |
| Switch backwards drive | switch off constant mode |

Constant mode off:

- PLUS overtakes current speed
- MINUS overtakes current speed

Constant mode on:

- PLUS increments without overtaking recent spee- MINUS decrements without overtaking recent speed
  The amount of each step can be adjusted with the Potentiometer on the switch board.

### Paddle Control Mode

The paddles are used to control the acceleration and deceleration (recuperation) values send to the motor controller (MC).

They are force sensitive: The more you pull them, the greater the setting value.

#### Adjust Paddles

After each start the paddles gets be adjusted automatically.

> Make sure that the paddles are in the home position, i.e. the position in which the paddles are set to partially tighten and then fully release. **Never push the paddles towards the front of the vehicle!**

If you release both paddles and the `acceleration/deceleration` display doesn't show `+ 0` the adjust procedure must be repeated by restarting DC.

If the control range of the paddles is to rough then the adjust procedure must be repeated by restarting DC.

## Car Operate

## Steering Wheel

### Buttons

#### Right / Left Indicators and Hazard Warning Lights

Press left or indicator (`left` or `right`)  button to switch indicators. The directions are displayed as yellow triangles on the display. Press again to switch off.

To switch on hazard indicator (all indicators blinking) press both indicator buttons at the same time. The hazard lights are shown as red triangles on the display.

Switch of the hazard light by pressing again both indicator buttons at the same time.

#### Dynamic Drive Mode

Use the paddles to increase (right paddle) and decrease (left paddle) speed of the car.

#### Constant Mode

Constant mode is usable in paddle control mode and in classic control mode.  
It is switched off on pressing break pedal or switch to drive backwards.

| Button | Function |
| --- | --- |
| SET (first time press) | set constant mode |
| SET (next time press)  | overtake current speed / power |
| RES | reset constant mode |
| PWR/SPD | switch between constant power and constant speed |
| PLUS | increase the target speed |
| MINUS | decrease the target speed |

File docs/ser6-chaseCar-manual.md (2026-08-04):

# Chase Car Manual SER V6

[[_TOC_]]

## Preparation

## Control Elements

### Mainboard

(nothing to do by the technicians)

### Emergency Controls

### Switch Board Preparation

### Steering Wheel Preparation

### Console Commands AC

```ini
Available commands (REDPSVJMUFBICOTKi:!sc?):
-------- SYSTEM COMMANDS -------------------------
R _ _ _ _ _ _ _ _ _ _ reset and reinit driver display
E _ _ _ _ _ _ _ _ _ _ switch to engineer screen
D _ _ _ _ _ _ _ _ _ _ switch to driver display
P _ _ _ _ _ _ _ _ _ _ print directory of sdcard
S _ _ _ _ _ _ _ _ _ _ print status
  [a]                   - print status and all values
V [|+]  _ _ _ _ _ _ _ write_log to sdcard | with header (+)
M _ _ _ _ _ _ _ _ _ _ mount sdcard and eneable logging
U _ _ _ _ _ _ _ _ _ _ unmount sdcard and disable logging
H _ _ _ _ _ _ _ _ _ _ memory_info
B [v|m|<rate>]  _ _ _ _ show or set baud rate of Serial2, v-verbose mode
F _ _ _ _ _ _ _ _ _ _ Re-read configuration
I _ _ _ _ _ _ _ _ _ _ read and show IOs
  [s]                   - scan and show I2C devices
  [R]                   - reinit
C _ _ _ _ _ _ _ _ _ _ set CAN verbose mode
  [i]                   - verbose CAN in
  [I]                   - verbose CAN in native packages
  [o]                   - verbose CAN out
  [O]                   - verbose CAN out native packages
  [S]                   - verbose sd card
  motC batV             - inject motor current [A] and battery voltage [V]
O _ _ _ _ _ _ _ _ _ _ set CarControl verbose mode
  [o]                   - verbose
  [O]                   - verbose debug
T _ _ _ _ _ _ _ _ _ _ get system time
  [yyyy mm dd hh MM ss] - set RTC date and time
K [|kp ki kd] _ _ _ _ show / update PID constants
i _ _ _ _ _ _ _ _ _ _ minimal drive to console
-------- DRIVER INFO COMMANDS --------------------
:<text> _ _ _ _ _ _ _ display driver info text
!<text> _ _ _ _ _ _ _ display driver warn text
s [|+|-]  _ _ _ _ _ _ speed arrow off, green up (+), red down (-)
-------- Driver SUPPORT COMMANDS -----------------
c [-|+|s|p] _ _ _ _ _ _ constant mode on (-:off|+:on|s:speed|p:power)
```

### Console Commands DC

```ini
Available commands (SVMUICOTK:!sch?):
-------- SYSTEM COMMANDS -------------------------
S _ _ _ _ _ _ _ _ _ _ print status
  [a]                 - print status and all values
H _ _ _ _ _ _ _ _ _ _ memory_info
I _ _ _ _ _ _ _ _ _ _ read and show IOs
  [s]                 - scan and show I2C devices
  [i|o]               - show in|out continuously
  [h]                 - show in handler results
  [a|d]               - show ADC|DAC continuously
  [c]                 - show controls acc/dec continuously, breakPedal
  [R]                 - reinit
C _ _ _ _ _ _ _ _ _ _ set CAN verbose mode
  [i]                 - verbose CAN in
  [I]                 - verbose CAN in native packages
  [o]                 - verbose CAN out
  [O]                 - verbose CAN out native packages
O _ _ _ _ _ _ _ _ _ _ set CarControl verbose mode
  [o]                 - verbose
  [O]                 - verbose debug
T [yyyy mm dd hh MM]  get/set RTC date and time
K [|kp ki kd] _ _ _ _ show / update PID constants
-------- DRIVER INFO COMMANDS --------------------
:<text> _ _ _ _ _ _ _ display driver info text
!<text> _ _ _ _ _ _ _ display driver warn text
s [|+|-]  _ _ _ _ _ _ speed arrow off, green up (+), red down (-)
-------- Driver SUPPORT COMMANDS -----------------
c [-|s|p] _ _ _ _ _ _ constant mode on (-:off|s:speed|p:power)
```

#### SYSTEM COMMANDS

| command | Function |
| :--- | :--- |
| R | reset and reinit driver display |
| C | switch to console screen |
| E | switch to engineer screen |
| D | switch to driver display |
| T yy mm dd hh MM | set rtc date and time |
| t | get date and time |
| - | adjust paddels |
| P | print directory of sdcard |
| s | print status of all values |
| S | print status |
| J | write JSON status to sdcard |
| v or V | Log state as csv to sd card, V: with header (write csv data row into `/SER4DATA.CSV`) |
| M | mount sdcard and eneable logging |
| P | print directory of sdcard |
| U | unmount sdcard and disable logging |
| ~H~ | ~memory_info~ |
| k kp ki kd | update PID constants |
| G [0-7] | GlideMode (0...7: 0:glide, 3:half glide/half recup, )7:recuperation |
| I | scan I2C devices |
| i | IO ReadAll |
| ii | verbose IO input view |
| io | verbose IO output view |
| | |
| iR | re-init IO |

#### DRIVER INFO COMMANDS

| command | Function |
| --- | --- |
| :`<text>` | display driver info text |
| !`<text>` | display driver warn text |
| u [-] | green speed up arrow (- => off) |
| d [-] | red speed down arrow (- => off) |

### Console Procedures

Mount SD card and start logging:

- Switch to Engineer Screen with button `R1`
- plug in the SD card
- Press button `R3`

The Engineer Info at the bottom of the Engineer Screen

## Car Start

### Boot Screen

The bootscreen with blue font on white background shows the initialization of all devices controlled by the car control system.

The last display is a 4 Seconds countdown to allow an additional view to the values.

### Adjust Paddles

During each start the paddles gets be adjusted automatically.

> Make sure that the paddles are in the home position, i.e. the position in which the paddles are set to partially tighten and then fully release. **Never push the paddles towards the front of the vehicle!**

If you release both paddles and the `acceleration/deceleration` display doesn't show `+ 0` the adjust procedure must be repeated by restarting DC.

If the control range of the paddles is to rough then the adjust procedure must be repeated by restarting DC.

## Car Operate

### Steering Wheel Drive

### Buttons

### Paddles

### Display

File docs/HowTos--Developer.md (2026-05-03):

# HowTos for SER V6 with ESP32 and platformio

## Run MenuConfig

writes the file `sdconfig` and sdconfig.esp32dev

`pio run -t menuconfig`

## Upload without recompile

`pio run -t nobuild -t upload --disable-auto-clean`

`platformio run --target upload --target monitor --environment esp32dev-linux` 

## Thread Safe C++

[c-thread-safe-queue](https://www.educba.com/c-thread-safe-queue/)

## Error: Brownout detector was triggered

[Hardware and Software Solution](https://arduino.stackexchange.com/questions/76690/esp32-brownout-detector-was-triggered-upon-wifi-begin)

## Platformio vscode

### Change `Upload` to `Upload and Monitor`

in `~/.config/Code/User/settings.json`:

behind

```json
{
  "text": "$(arrow-right)",
  "tooltip": "PlatformIO: Upload",
  "commands": "platformio-ide.upload"
},
```

add

```json
{
  "text": "$(arrow-right)$(plug)",
  "tooltip": "PlatformIO: Upload and Monitor",
  "commands": "platformio-ide.uploadAndMonitor"
},
```

**complete `platformio-ide` part in** `~/.config/Code/User/settings.json`:

```json
    "platformio-ide.forceUploadAndMonitor": true,
    "platformio-ide.disablePIOHomeStartup": true,
    "platformio-ide.customPATH": "",
    "platformio-ide.toolbar": [
        {
            "text": "$(home)",
            "tooltip": "PlatformIO: Home",
            "commands": "platformio-ide.showHome"
        },
        {
            "text": "$(check)",
            "tooltip": "PlatformIO: Build",
            "commands": "platformio-ide.build"
        },
        {
            "text": "$(arrow-right)",
            "tooltip": "PlatformIO: Upload",
            "commands": "platformio-ide.upload"
        },
        {
            "text": "$(arrow-right)$(plug)",
            "tooltip": "PlatformIO: Upload and Monitor",
            "commands": "platformio-ide.uploadAndMonitor"
        },
        {
            "text": "$(trashcan)",
            "tooltip": "PlatformIO: Clean",
            "commands": "platformio-ide.clean"
        },
        {
            "text": "$(beaker)",
            "tooltip": "PlatformIO: Test",
            "commands": "platformio-ide.test"
        },
        {
            "text": "$(plug)",
            "tooltip": "PlatformIO: Serial Monitor",
            "commands": "platformio-ide.serialMonitor"
        },
        {
            "text": "$(terminal)",
            "tooltip": "PlatformIO: New Terminal",
            "commands": "platformio-ide.newTerminal"
        }
    ],
    "platformio-ide.reopenSerialMonitorDelay": 1000,

```

## Library Notes
### PWM

Theorie, Tutorials:

- [readthedocs.io | python](https://super-starter-kit-for-esp32-s3-wroom.readthedocs.io/en/latest/2.Python_Tutorial/4_analog%26pwm.html)
- [www.electronicshub.org | esp32 freeRTOS](https://www.electronicshub.org/esp32-pwm-tutorial/)

Libraries:

- [github.com | ESP32 PWM](https://github.com/khoih-prog/ESP32_PWM?tab=readme-ov-file) ([www.arduinolibraries.info | libraries/esp](https://www.arduinolibraries.info/libraries/esp32_pwm))
- [registry.platformio.org | libraries/khoih-prog/ESP](https://registry.platformio.org/libraries/khoih-prog/ESP32_PWM)

#### Running Demo on DC,v2-Controller (SER6) 1

```cpp
  const int PinACCL = PO_AccelPWM_GPIO16; /* GPIO16 */
  const int PinDECCL = PO_DeccelPWM_GPIO02; /* GPIO02 */

  int dutyCycle;
  /* Setting PWM Properties */
  //const int PWMFreq = 5000; /* 5 KHz */
  const int PWMFreq = 50; /* 50 Hz */
  const int PWMChannelACCL = 0;
  const int PWMChannelDECL = 1;
  const int PWMResolution = 10;
  const int MAX_DUTY_CYCLE = (int)(pow(2, PWMResolution) - 1);

  uint32_t retValue = ledcSetup(PWMChannelACCL, PWMFreq, PWMResolution);
  /* Attach the LED PWM Channel to the GPIO Pin */
  ledcAttachPin(PinACCL, PWMChannelACCL);
  ledcAttachPin(PinDECCL, PWMChannelDECL);

  console << "PWM inited [" << retValue << "] at GPIO " << PO_AccelPWM_GPIO16_name << "(" << PO_AccelPWM_GPIO16 << ")" << NL;
  while (1) {
    /* Increasing the LED brightness with PWM */
    console << "increasing 0 - " << MAX_DUTY_CYCLE << "...";
    for (dutyCycle = 0; dutyCycle <= MAX_DUTY_CYCLE; dutyCycle++) {
      ledcWrite(PWMChannelACCL, dutyCycle);
      ledcWrite(PWMChannelDECL, MAX_DUTY_CYCLE-dutyCycle);
      vTaskDelay(10);
    }
    /* Decreasing the LED brightness with PWM */
    console << " --- decreasing " << MAX_DUTY_CYCLE << " - 0...";
    for (dutyCycle = MAX_DUTY_CYCLE; dutyCycle >= 0; dutyCycle--) {
      ledcWrite(PWMChannelACCL, dutyCycle);
      ledcWrite(PWMChannelDECL, MAX_DUTY_CYCLE-dutyCycle);
      vTaskDelay(10);
    }
    console << NL << "next cycle: ";
  }
```

#### Running Demo on DC,v2-Controller (SER6) 2

```cpp
  // Espressif 2.0
  // const int PinACCL = PO_AccelPWM_GPIO16; /* GPIO16 */
  // const int PinDECCL = PO_DeccelPWM_GPIO02; /* GPIO02 */

  // int dutyCycle;
  // /* Setting PWM Properties */
  // //const int PWMFreq = 5000; /* 5 KHz */
  // const int PWMFreq = 50; /* 50 Hz */
  // const int PWMChannelACCL = 0;
  // const int PWMChannelDECL = 1;
  // const int PWMResolution = 10;
  // const int MAX_DUTY_CYCLE = (int)(pow(2, PWMResolution) - 1);

  // uint32_t retValue = ledcSetup(PWMChannelACCL, PWMFreq, PWMResolution);
  // /* Attach the LED PWM Channel to the GPIO Pin */
  // ledcAttachPin(PinACCL, PWMChannelACCL);
  // ledcAttachPin(PinDECCL, PWMChannelDECL);

  // console << "PWM inited [" << retValue << "] at GPIO " << PO_AccelPWM_GPIO16_name << "(" << PO_AccelPWM_GPIO16 << ")" << NL;
  // while (1) {
  //   /* Increasing the LED brightness with PWM */
  //   console << "increasing 0 - " << MAX_DUTY_CYCLE << "...";
  //   for (dutyCycle = 0; dutyCycle <= MAX_DUTY_CYCLE; dutyCycle++) {
  //     ledcWrite(PWMChannelACCL, dutyCycle);
  //     ledcWrite(PWMChannelDECL, MAX_DUTY_CYCLE-dutyCycle);
  //     vTaskDelay(10);
  //   }
  //   /* Decreasing the LED brightness with PWM */
  //   console << " --- decreasing " << MAX_DUTY_CYCLE << " - 0...";
  //   for (dutyCycle = MAX_DUTY_CYCLE; dutyCycle >= 0; dutyCycle--) {
  //     ledcWrite(PWMChannelACCL, dutyCycle);
  //     ledcWrite(PWMChannelDECL, MAX_DUTY_CYCLE-dutyCycle);
  //     vTaskDelay(10);
  //   }
  //   console << NL << "next cycle: ";
  // }

  // ledc_timer_config_t conf_timer;
  // conf_timer.speed_mode = LEDC_HIGH_SPEED_MODE;
  // conf_timer.duty_resolution = LEDC_TIMER_8_BIT;
  // conf_timer.timer_num = LEDC_TIMER_0;
  // conf_timer.freq_hz = 1000 ;
  // //conf_timer.clk_cfg = LEDC_AUTO_CLK;
  // if(ledc_timer_config(&conf_timer) == ESP_OK)
  // {
  // 	printf("led driver inited \n");
  // }
  // else
  // {
  // 	printf("led driver init failed \n");
  // }

  // Espressif 3.0
  // #if CONFIG_PM_ENABLE
  //   esp_pm_config_t pm_config = {.max_freq_mhz = CONFIG_ESP_DEFAULT_CPU_FREQ_MHZ,
  //                                .min_freq_mhz = CONFIG_ESP_DEFAULT_CPU_FREQ_MHZ,
  // #if CONFIG_FREERTOS_USE_TICKLESS_IDLE
  //                                .light_sleep_enable = true
  // #endif
  //   };
  //   ESP_ERROR_CHECK(esp_pm_configure(&pm_config));
  // #endif
  //   // Set the LEDC peripheral configuration
  //   example_ledc_init();
  //   // Set duty to 50%
  //   ESP_ERROR_CHECK(ledc_set_duty(LEDC_MODE, LEDC_CHANNEL, LEDC_DUTY));
  //   // Update duty to apply the new value
  //   ESP_ERROR_CHECK(ledc_update_duty(LEDC_MODE, LEDC_CHANNEL));

  // while (1) {
  //     /* Increasing the LED brightness with PWM */
  //     console << "increasing 0 - " << LEDC_DUTY << "...";
  //     for (int dutyCycle = 0; dutyCycle <= LEDC_DUTY; dutyCycle++) {
  //       ledc_set_duty(LEDC_MODE, LEDC_CHANNEL, dutyCycle);
  //       vTaskDelay(10);
  //     }
  //     /* Decreasing the LED brightness with PWM */
  //     console << " --- decreasing " << LEDC_DUTY << " - 0...";
  //     for (int dutyCycle = LEDC_DUTY; dutyCycle >= 0; dutyCycle--) {
  //       ledc_set_duty(LEDC_MODE, LEDC_CHANNEL, dutyCycle);
  //       vTaskDelay(10);
  //     }
  //     console << NL << "next cycle: ";
  //   }
```

## ttyUSB

`ll /dev/ttyU* ; ll /dev/esp32-*`

```bash
sudo nano /etc/udev/rules.d/99-esp32.rules
```

```rules
# Rule for first ESP32 board (plugged into port with KERNELS 1-1.2)
SUBSYSTEM=="tty", ATTRS{idVendor}=="1a86", ATTRS{idProduct}=="7523", KERNELS=="1-2", SYMLINK+="esp32-ac"

# Rule for second ESP32 board (plugged into port with KERNELS 1-1.3)
SUBSYSTEM=="tty", ATTRS{idVendor}=="1a86", ATTRS{idProduct}=="7523", KERNELS=="1-1", SYMLINK+="esp32-dc"
```

```bash
sudo udevadm control --reload-rules && sudo udevadm trigger

```

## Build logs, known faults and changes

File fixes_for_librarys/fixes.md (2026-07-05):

# Fixes to loaded Library Packages 

[TOC]

platform: espressif32@5.2.0

## General / Tools

### Upload without rebuild

`pio run -t nobuild -t upload`

### Rebuild all every time Error

#### Error

All sources and libraries are built every time the compile or compile, upload, monitor is executed.

#### Files affeced

~~.platformio/penv/lib/python3.8/site-packages/platformio/builder/main.py:~~

```python
#env.SConsignFile(
#    os.path.join(
#        "$BUILD_DIR", ".sconsign%d%d" % (sys.version_info[0], sys.version_info[1])
#    )
#)
#
env.SConsignFile(
    os.path.join(
        "$BUILD_DIR", ".sconsign.dblite")
    )
)
```

#### Solution

remove `-D CURRENT_TIME=$UNIX_TIME` from `build_flags`

## AC + DC

### Conflict concerning `#define B1 1`

#### Error Message

```bash
/home/ksc/.platformio/packages/framework-arduinoespressif32/cores/esp32/binary.h:31:12: error: expected '>' before numeric constant
 #define B1 1
            ^
.pio/libdeps/esp32dev-linux/fmt/include/fmt/core.h:1118:16: note: in expansion of macro 'B1'
 template <bool B1, bool B2, bool... Tail> constexpr auto count() -> size_t {
                ^~
```

#### Files affeced

- File1: `.platformio/packages/framework-arduinoespressif32/cores/esp32/binary.h`
- File2:
  - Linux: `.pio/libdeps/esp32dev-linux/fmt/include/fmt/core.h`
  - Windows:  `.pio/libdeps/esp32dev-windows/fmt/include/fmt/core.h`

#### FIX

To avoid problem in `binary.h` change the following file:

- Change for Linux: `.pio/libdeps/esp32dev-linux/fmt/include/fmt/core.h` at line 1120ff
- Change for Windows: `.pio/libdeps/esp32dev-windows/fmt/include/fmt/core.h` at line 1120ff

```c++
// marker line:
// template <bool B1, bool B2, bool... Tail> constexpr auto count() -> size_t {
//   return (B1 ? 1 : 0) + count<B2, Tail...>();
// }
// CHANGE_KSC: Conflict with #define B1 1 in .platformio/packages/framework-arduinoespressif32/cores/esp32/binary.h
template <bool BOOL1, bool BOOL2, bool... Tail> constexpr auto count() -> size_t {
  return (BOOL1 ? 1 : 0) + count<BOOL2, Tail...>();
}
```

### ~~esp32-hal-gpio.c~~

#### ~~Error Message~~

???

#### ~~Files affeced~~

```bash
/home/ksc/.platformio/packages/framework-arduinoespressif32/cores/esp32/esp32-hal-gpio.c: In function '__pinMode':
/home/ksc/.platformio/packages/framework-arduinoespressif32/cores/esp32/esp32-hal-gpio.c:102:24: error: 'rtc_gpio_desc' undeclared (first use in this function); did you mean 'rtc_io_desc'?
```

[issues57](https://github.com/maximkulkin/esp32-homekit-camera/issues/57)

#### FIX 

- There is a setting on latest ESP-IDF you need to enable for this project. I’m afk now, but you should be able to find it somewhere in component configs -> device configurations -> rtc something. Just enable it and it will compile.
- It is in `Component config > driver configurations > RTCI0 configuration`: \[*] Support array `rtc_gpio_desc` for ESP32

### rtc.h

#### Error Message

???

#### Files affected

#### FIX

Comment `#define MHZ (1000000)` to avoid conflict in ???

### .platformio/packages/framework-arduinoespressif32/libraries/ESPmDNS/src/ESPmDNS.h

```c++
//KSC void enableWorkstation(wifi_interface_t interface=ESP_IF_WIFI_STA);
  void enableWorkstation(wifi_interface_t interface);
  void disableWorkstation();
```

### ESPmDNS

#### Error Message

???

#### Files affected

- `.platformio/packages/framework-arduinoespressif32/libraries/ESPmDNS/src/ESPmDNS.h`

- `.platformio/packages/framework-arduinoespressif32/libraries/ESPmDNS/src/ESPmDNS.cpp` 

#### FIX

Change in `.platformio/packages/framework-arduinoespressif32/libraries/ESPmDNS/src/ESPmDNS.h`:

```c++
  //KSC void enableWorkstation(wifi_interface_t interface=ESP_IF_WIFI_STA);
  void enableWorkstation(wifi_interface_t interface);
  void disableWorkstation();
```

Change in `.platformio/packages/framework-arduinoespressif32/libraries/ESPmDNS/src/ESPmDNS.cpp`:

```c++
IPAddress MDNSResponder::queryHost(char *host, uint32_t timeout){
    //KSC struct ip4_addr addr;
    struct esp_ip4_addr addr;
    addr.addr = 0;

    esp_err_t err = mdns_query_a(host, timeout,  &addr);
    if(err){
        if(err == ESP_ERR_NOT_FOUND){
            log_w("Host was not found!");
            return IPAddress();
        }
        log_e("Query Failed");
        return IPAddress();
    }
    return IPAddress(addr.addr);
}
```

### ssl_client.cpp

#### Error Message

???

#### Files affected

- `.platformio/packages/framework-arduinoespressif32/libraries/WiFiClientSecure/src/ssl_client.cpp`

#### FIX

- [Fix with PR](https://github.com/gravitech-engineer/AIS_IoT_4G/pull/8)

Change in `.platformio/packages/framework-arduinoespressif32/libraries/WiFiClientSecure/src/ssl_client.cpp`:

```c++
//KSC #ifndef MBEDTLS_KEY_EXCHANGE__SOME__PSK_ENABLED
#if !defined(MBEDTLS_KEY_EXCHANGE__SOME__PSK_ENABLED) && !defined(MBEDTLS_KEY_EXCHANGE_SOME_PSK_ENABLED)
#  error "Please configure IDF framework to include mbedTLS -> Enable pre-shared-key ciphersuites and activate at least one cipher"
#endif
```

### Several things made with pio menuconfig

#### Error Message

Please call `idf.py menuconfig` then go to Component config -> mbedTLS -> TLS Key Exchange Methods -> Enable pre-shared-key ciphersuites and then check `Enable PSK based cyphersuite modes`. Save and Quit."

#### Files affected

```make
/home/ksc/.platformio/packages/framework-arduinoespressif32/libraries/WiFiClientSecure/src/ssl_client.cpp:24:4: warning: #warning "Please call `idf.py menuconfig` then go to Component config -> mbedTLS -> TLS Key Exchange Methods -> Enable pre-shared-key ciphersuites and then check `Enable PSK based cyphersuite modes`. Save and Quit." [-Wcpp]
 #  warning "Please call `idf.py menuconfig` then go to Component config -> mbedTLS -> TLS Key Exchange Methods -> Enable pre-shared-key ciphersuites and then check `Enable PSK based cyphersuite modes`. Save and Quit."
    ^~~~~~~
```

## AC only
### SD card: fix memory access after free (RAII DTOR):
in `.platformio/packages/framework-arduinoespressif32/libraries/SD/src/sd_diskio.cpp` function `sdcard_uninit()`

**Patched file stored at:** `fixes_for_librarys/sd_diskio.cpp`

**To apply:** copy `fixes_for_librarys/sd_diskio.cpp` to
`.platformio/packages/framework-arduinoespressif32/libraries/SD/src/sd_diskio.cpp`

#### Root cause

`AcquireSPI` is a RAII lock that stores a raw `card*` pointer. In the original
code the lock was in scope until the end of `sdcard_uninit()`, but `free(card)`
was called before that closing `}`. When the destructor fired it called
`card->spi->endTransaction()` on already-freed memory → `LoadProhibited` panic.

#### Fix

Scope the lock into a nested block so its destructor runs before `free(card)`:

```c++
// BEFORE — destructor fires after free(card):
AcquireSPI lock(card);
sdTransaction(pdrv, GO_IDLE_STATE, 0, NULL);
ff_diskio_register(pdrv, NULL);
s_cards[pdrv] = NULL;
// ... free(card->base_path); free(card);  ← card already used by dtor above
```

```c++
// AFTER — destructor fires inside block, card still valid:
{AcquireSPI lock(card);
  sdTransaction(pdrv, GO_IDLE_STATE, 0, NULL);
}
ff_diskio_register(pdrv, NULL);
s_cards[pdrv] = NULL;
// ... free(card->base_path); free(card);  ← safe
```

(Fix is present in the upstream main branch but not yet in a published release.)

## AC + DC

### CAN task watchdog during TX wait

#### Symptom

- Task watchdog triggers while CAN task is running and stack trace points to `ESP32SJA1000Class::endPacket()`.

#### Root cause

- In the CAN library for ESP32, `endPacket()` waits in loops using `yield()` while TX buffer is busy / TX completion is pending.
- With a high-priority CAN task, this can starve idle tasks on the same core and trigger task watchdog.

#### FIX

Patch `yield()` to `delay(1)` in both wait loops inside:

- Linux:
  - `AC/.pio/libdeps/esp32dev-linux/CAN/src/ESP32SJA1000.cpp`
  - `DC/.pio/libdeps/esp32dev-linux/CAN/src/ESP32SJA1000.cpp`
- Windows:
  - `AC/.pio/libdeps/esp32dev-windows/CAN/src/ESP32SJA1000.cpp`

Patched sections:

```c++
// wait for TX buffer to free
while ((readRegister(REG_SR) & 0x04) != 0x04) {
  delay(1);
}

// wait for TX complete
while ((readRegister(REG_SR) & 0x08) != 0x08) {
  if (readRegister(REG_ECC) == 0xd9) {
    modifyRegister(REG_CMR, 0x1f, 0x02); // error, abort
    return 0;
  }
  delay(1);
}
```

Additional robustness fix (recommended): add a TX timeout to both wait loops,
abort TX on timeout, and clear error/irq latches so the task cannot stall
forever waiting for TX completion.

## DC only

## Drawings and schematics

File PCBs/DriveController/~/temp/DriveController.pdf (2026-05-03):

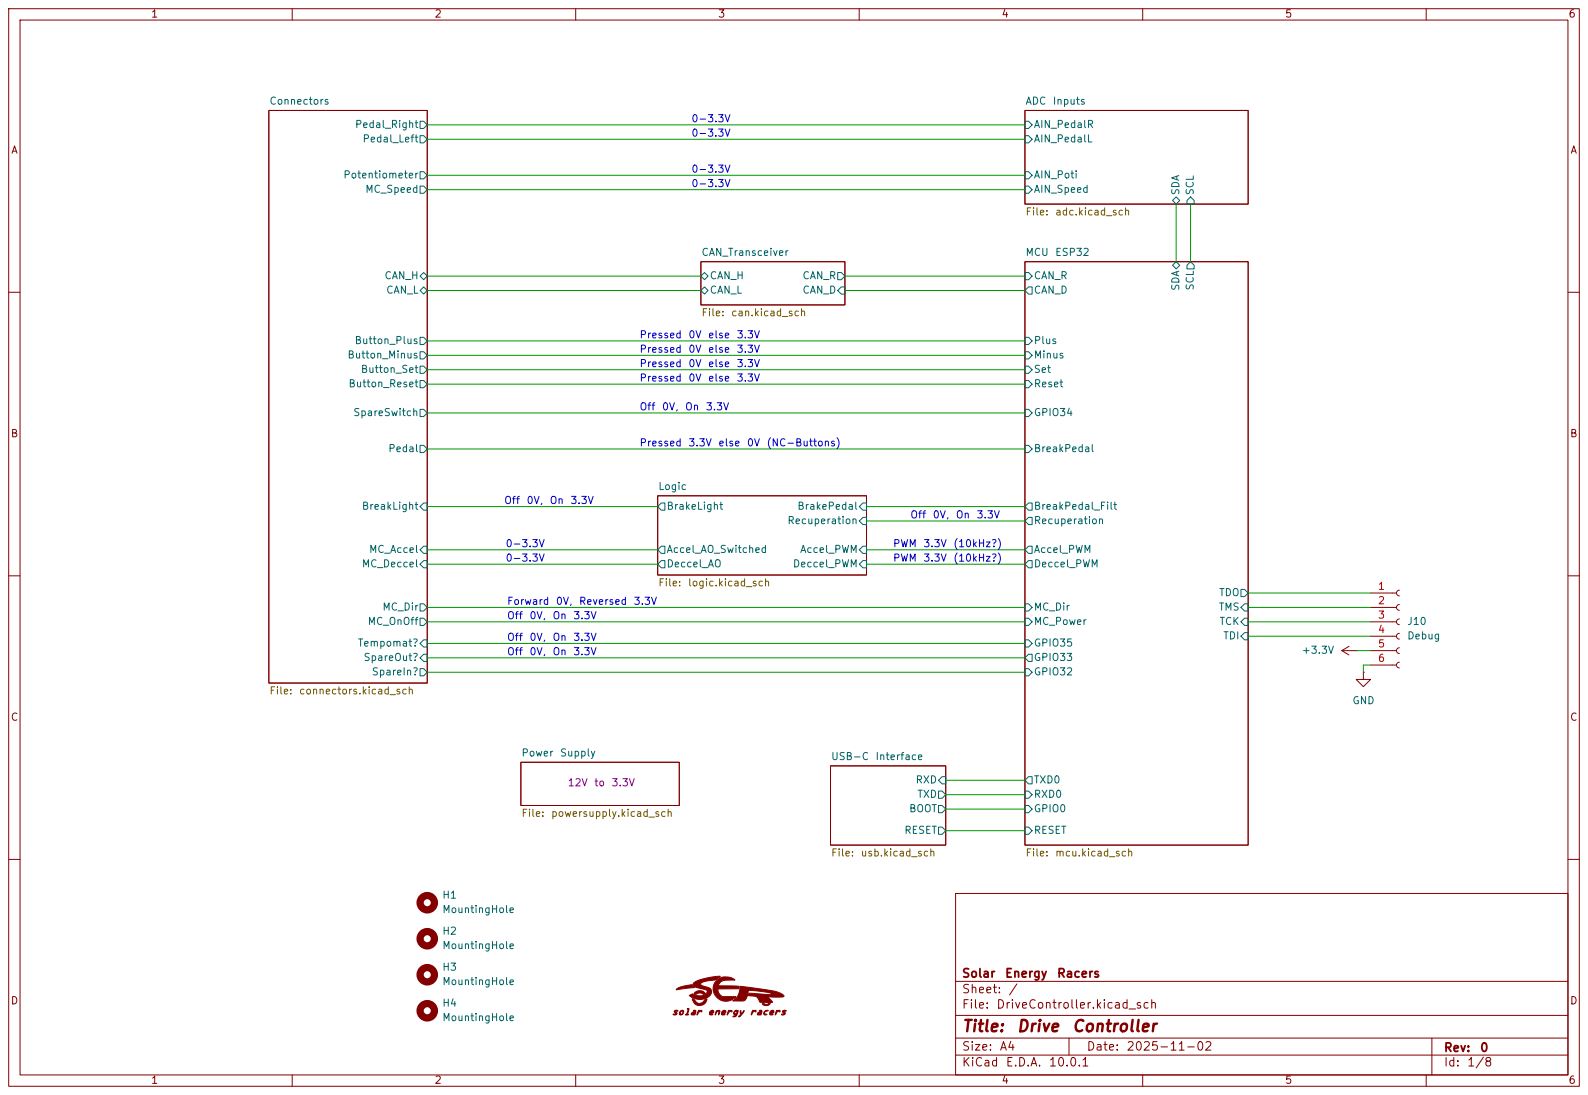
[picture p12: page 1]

Pedal_Right Button_Minus Button_Set Pedal_Left Button_Reset Button_Plus CAN_L CAN_H
BreakLight MC_Dir MC_OnOff Potentiometer Tempomat? MC_Accel MC_Deccel MC_Speed Pedal SpareSwitch

TMS Reset Minus Set Plus BreakPedal MC_Dir MC_Power Recuperation

Solar Energy Racers Power Supply File: powersupply.kicad_sch 12V to 3.3V

Size: A4 | Rev: 0
KiCad E.D.A. 10.0.1 | Id: 1/8

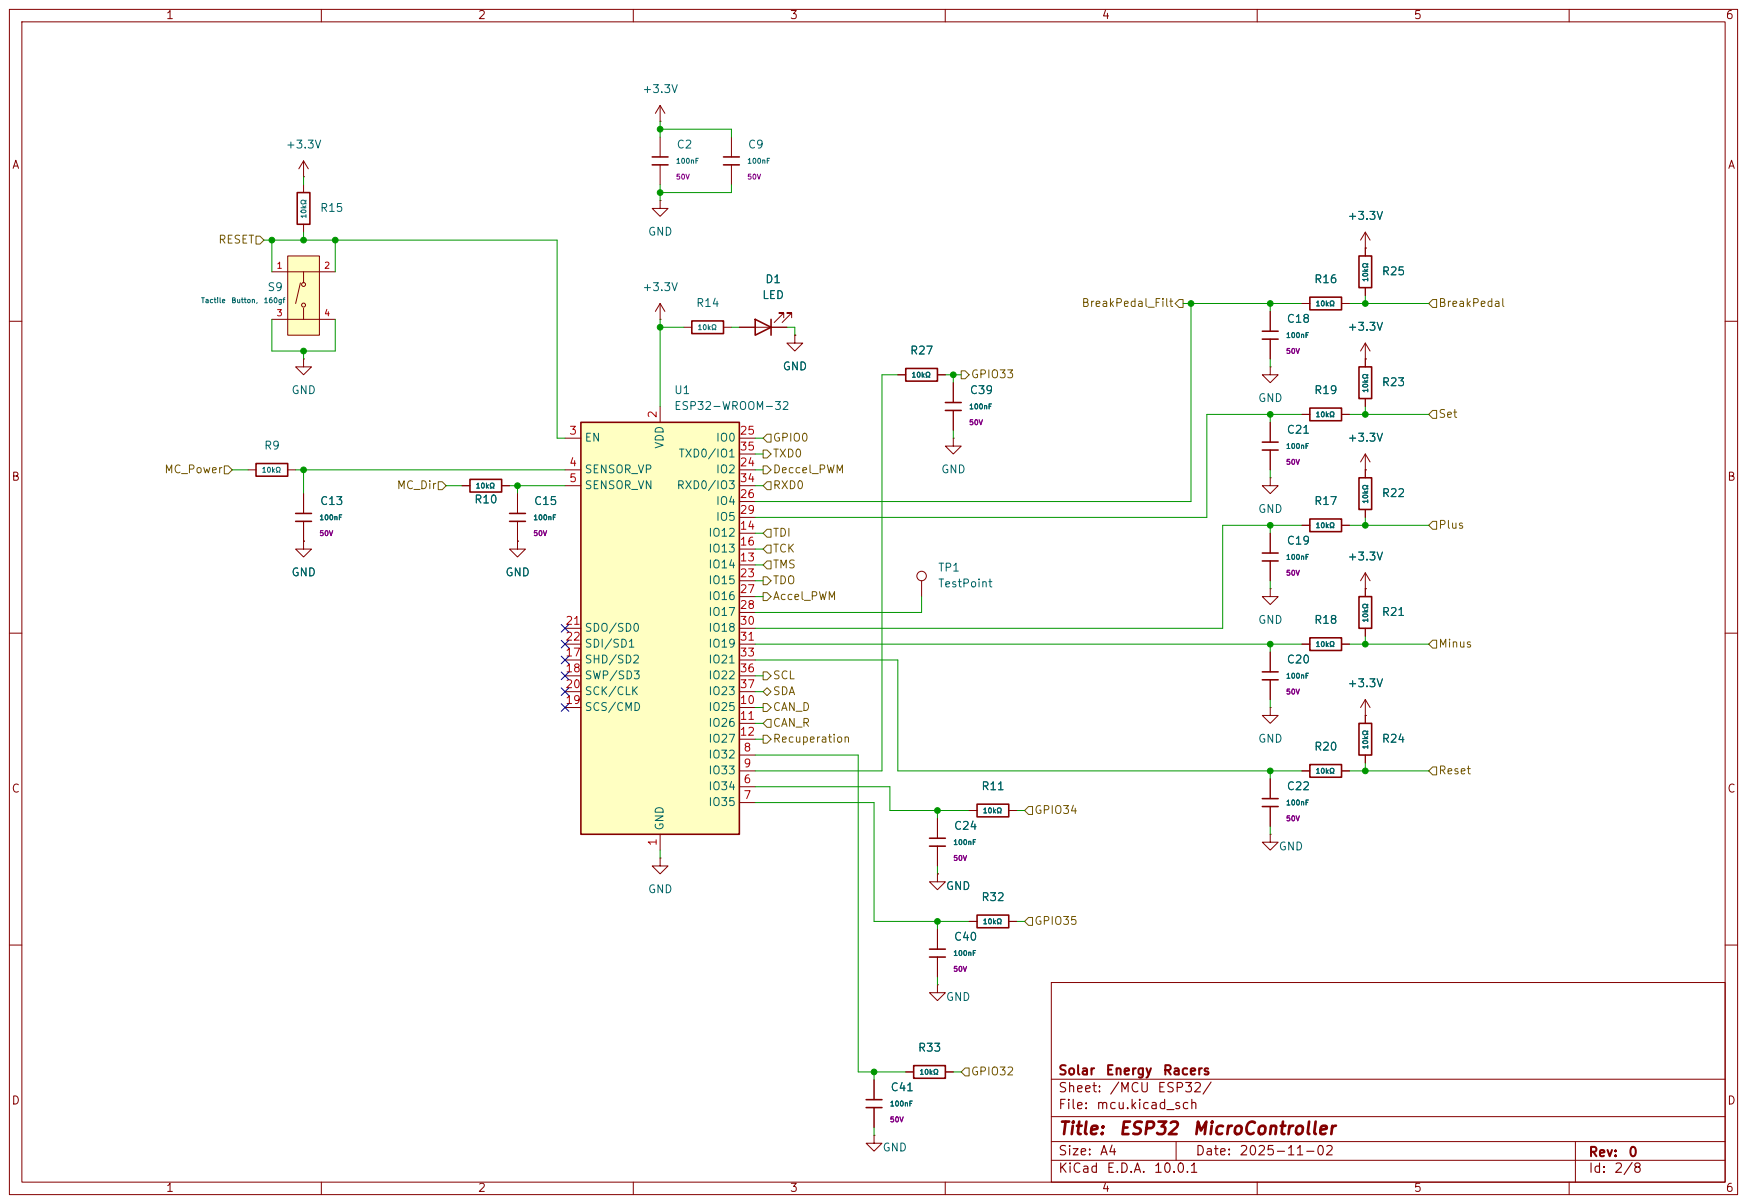
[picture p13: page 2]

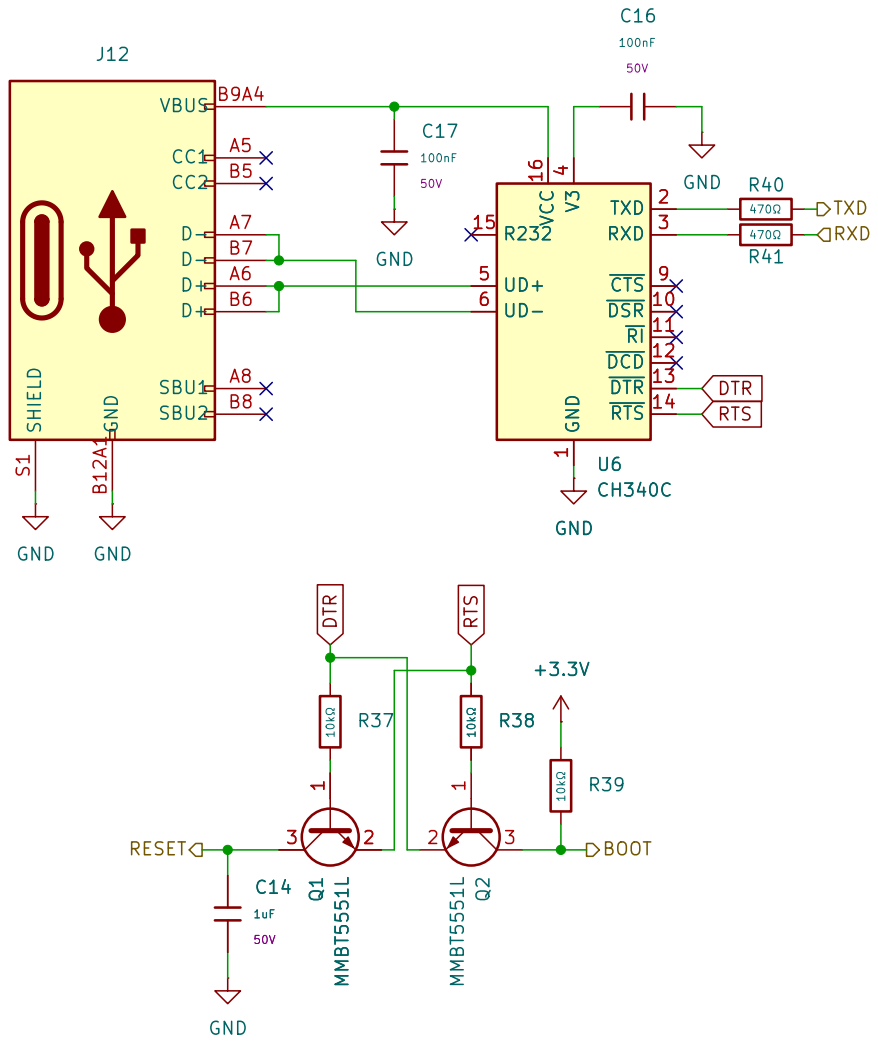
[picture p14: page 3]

Solar Energy Racers GND 1

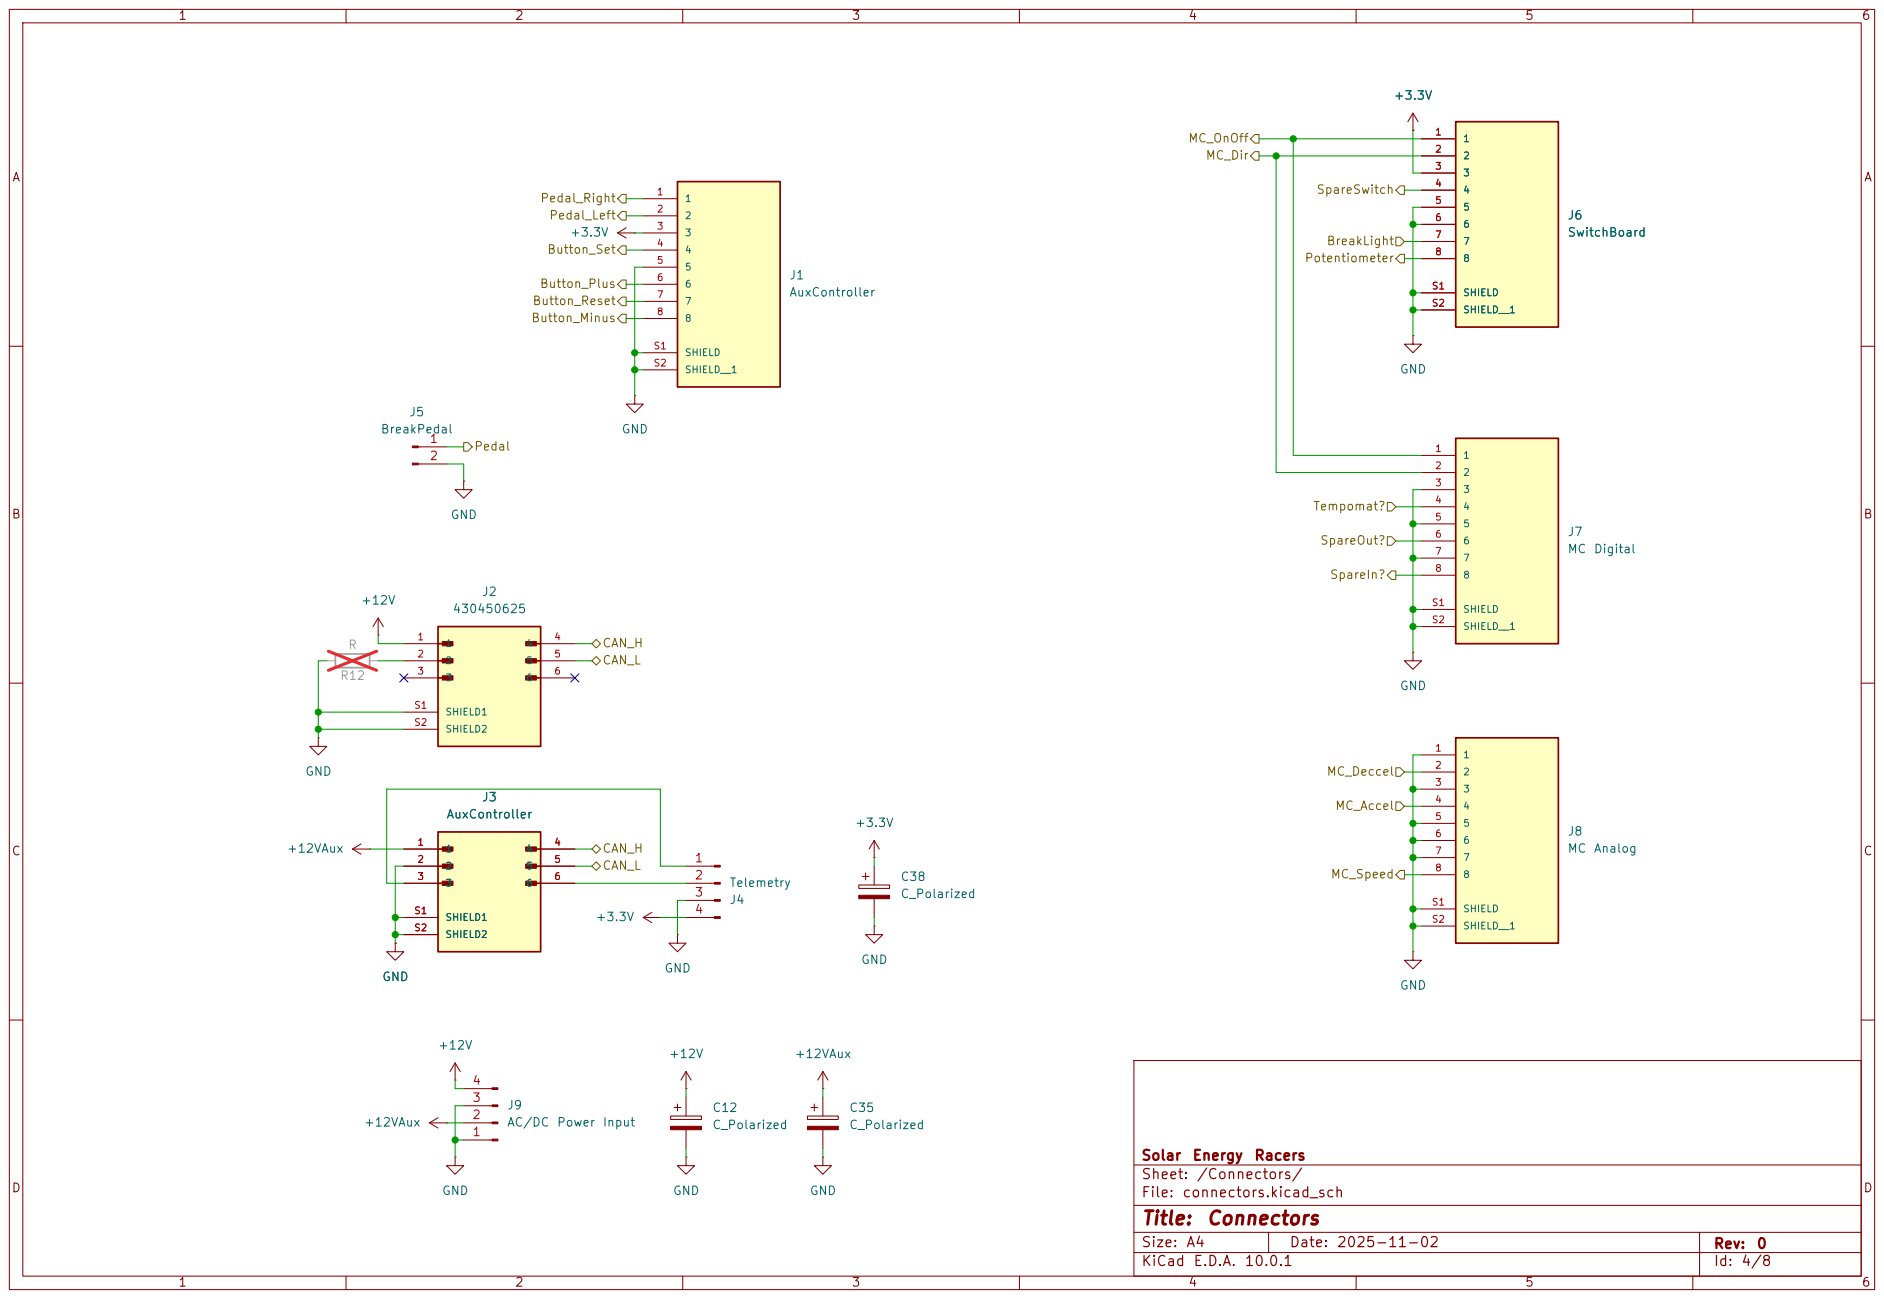
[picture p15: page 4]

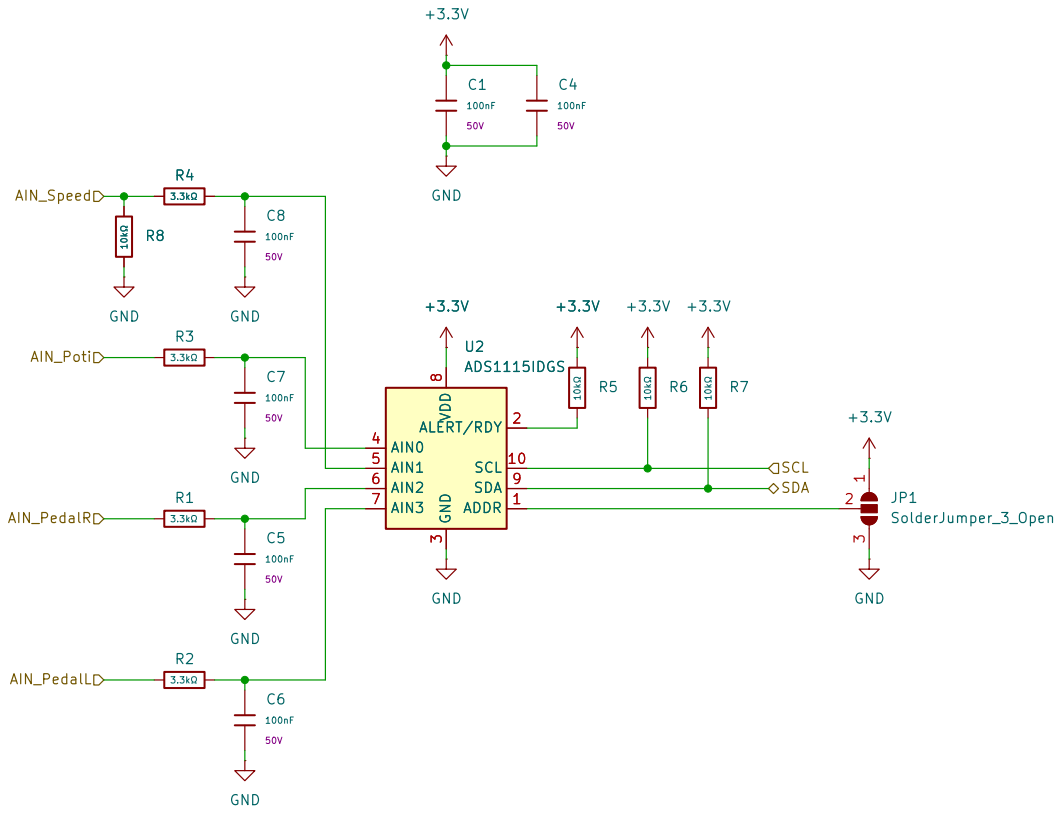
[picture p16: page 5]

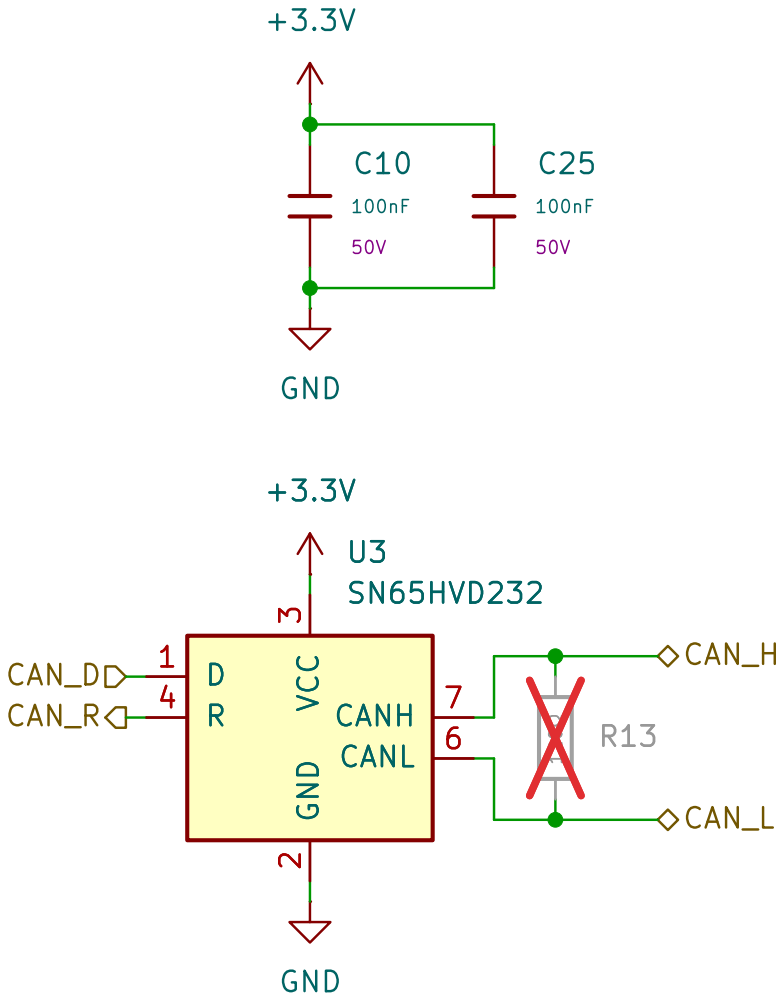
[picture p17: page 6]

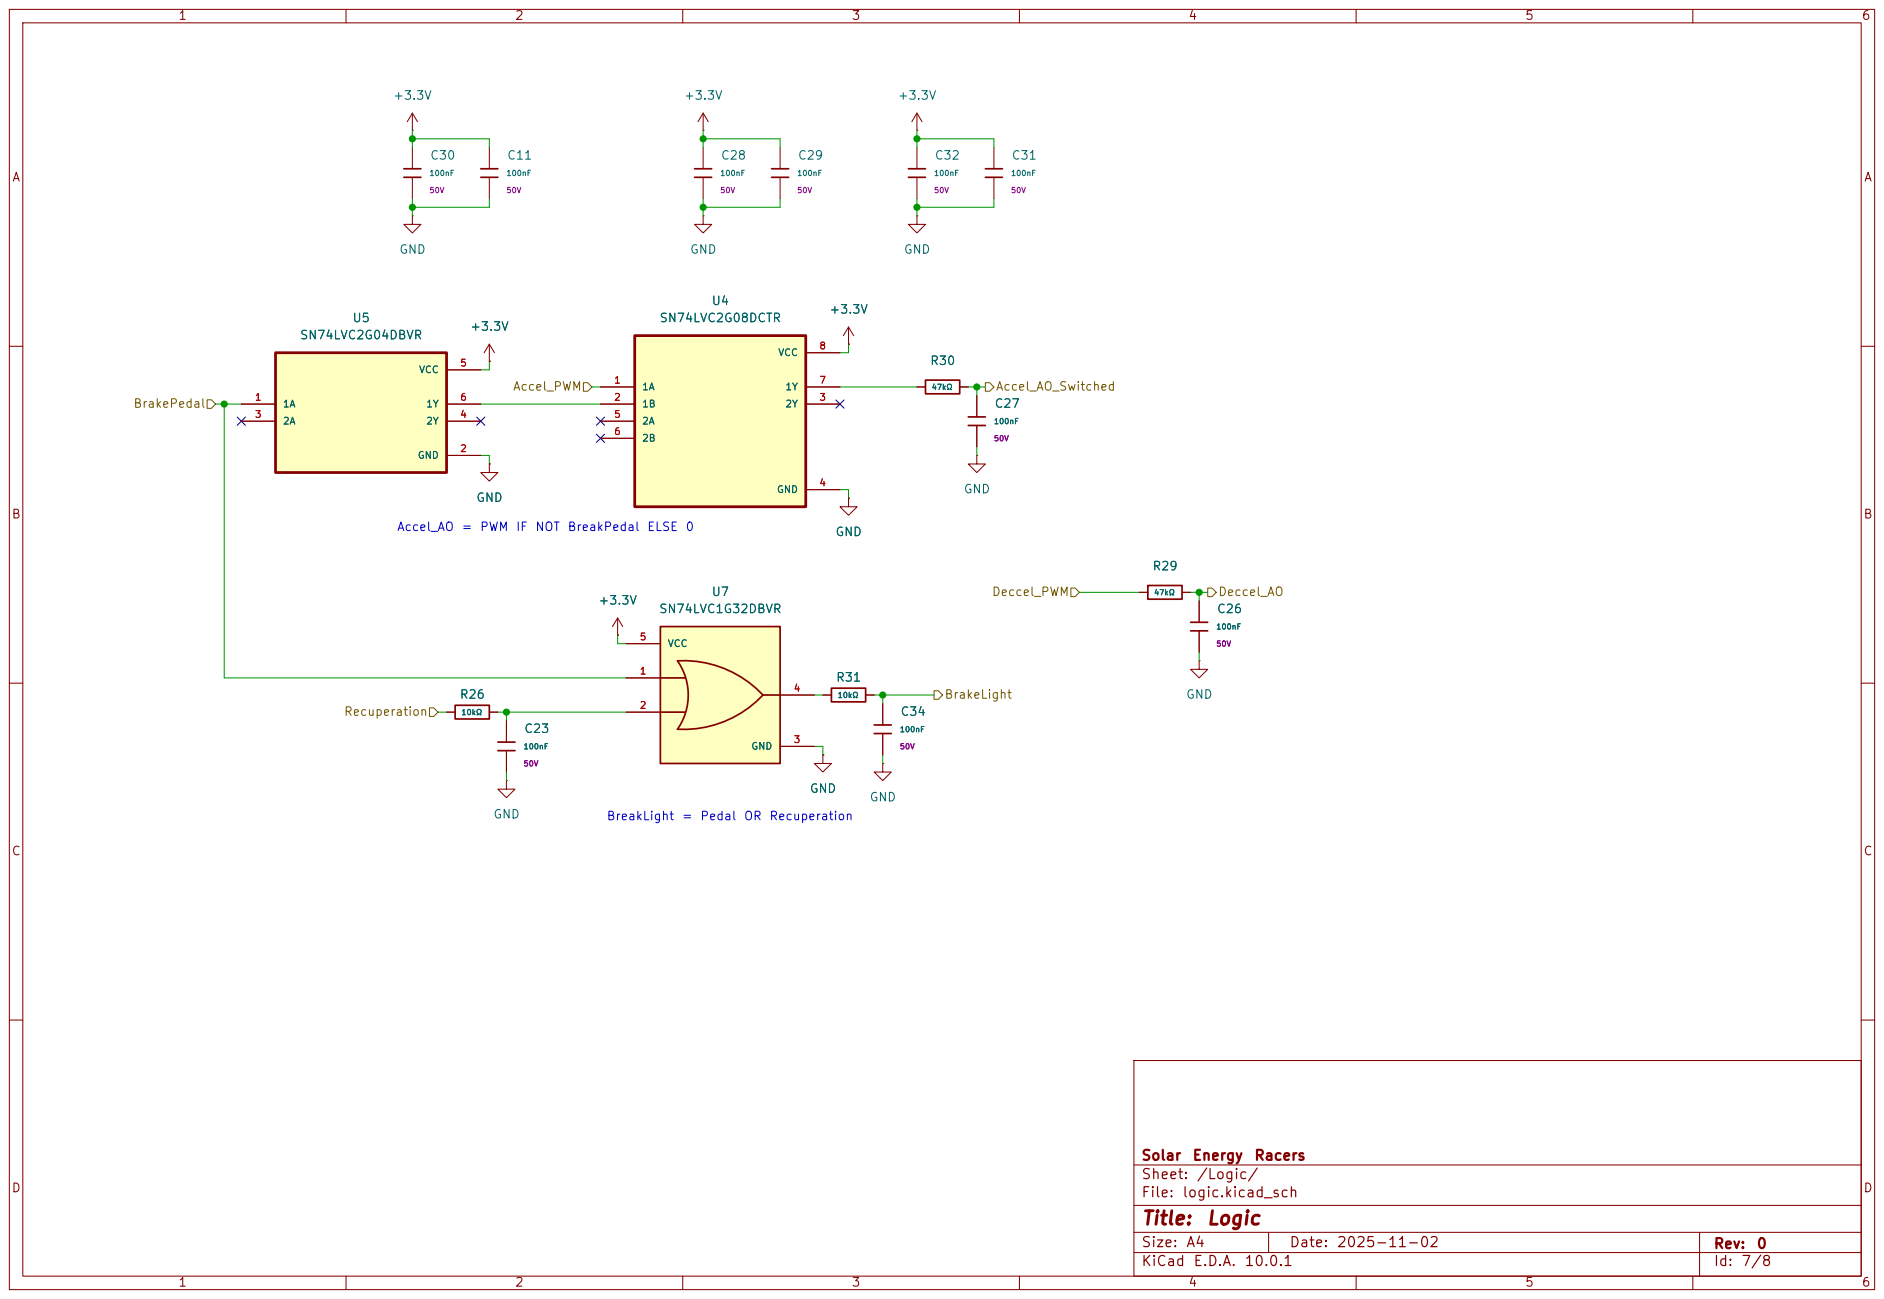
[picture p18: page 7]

Accel_AO = PWM IF NOT BreakPedal ELSE 0 +3.3V GND

BreakLight = Pedal OR Recuperation

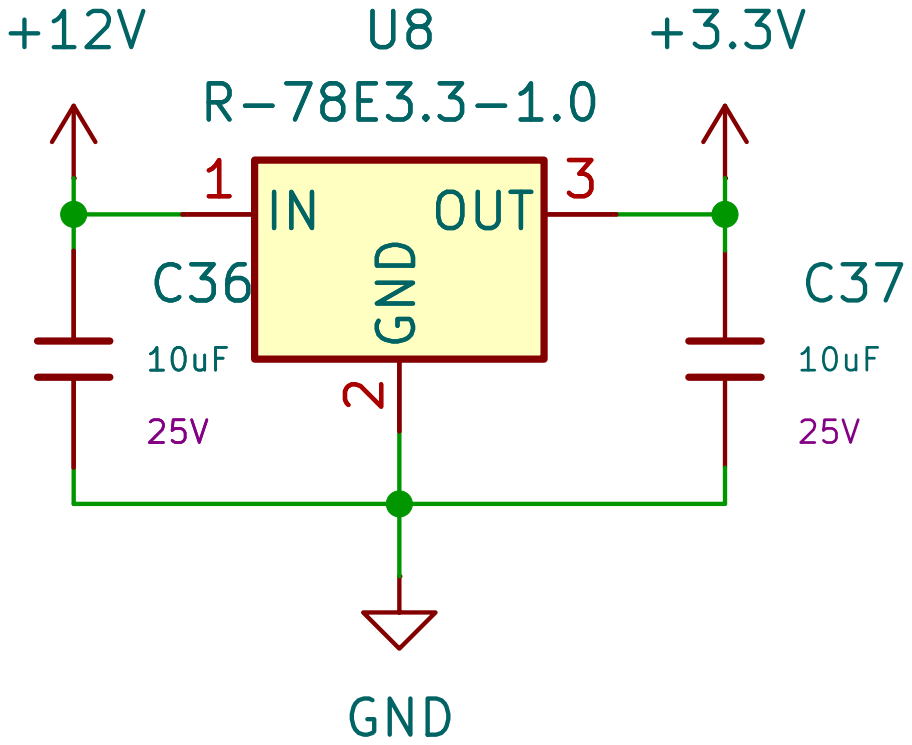
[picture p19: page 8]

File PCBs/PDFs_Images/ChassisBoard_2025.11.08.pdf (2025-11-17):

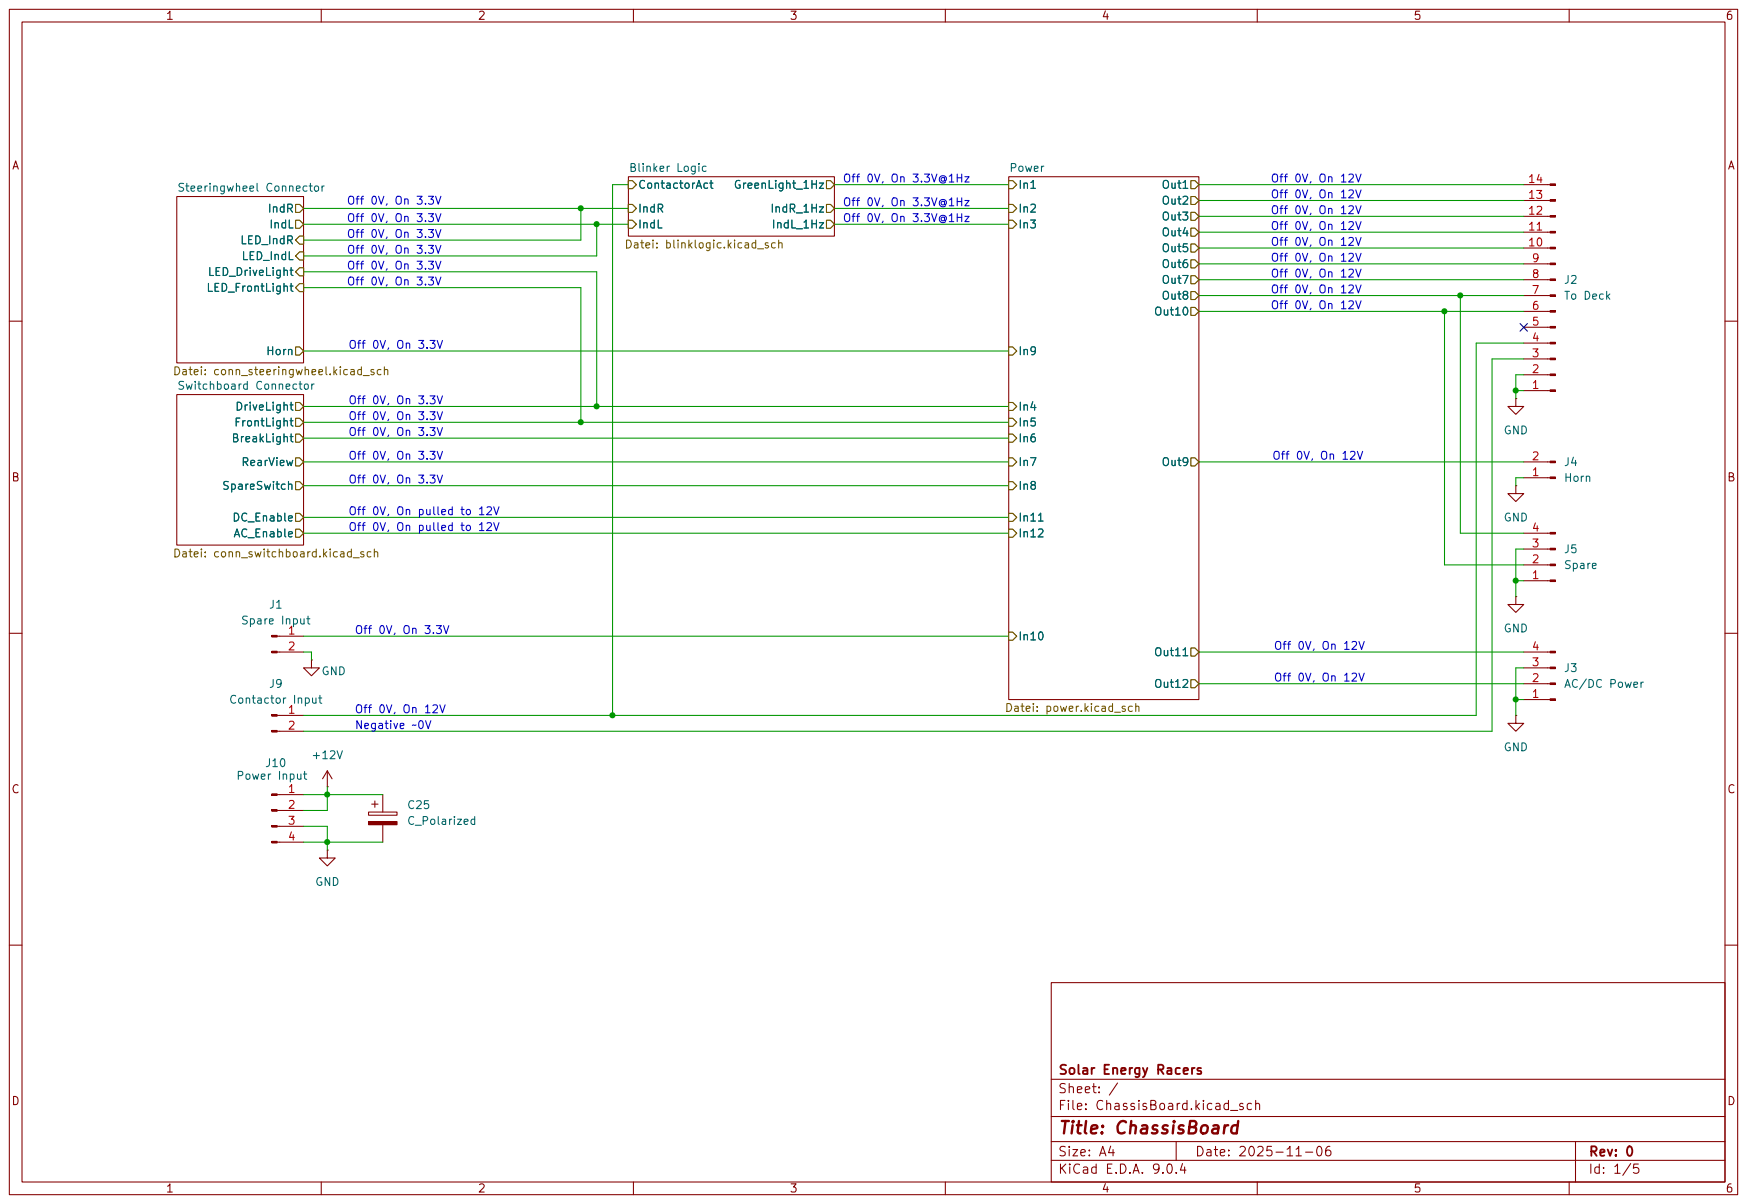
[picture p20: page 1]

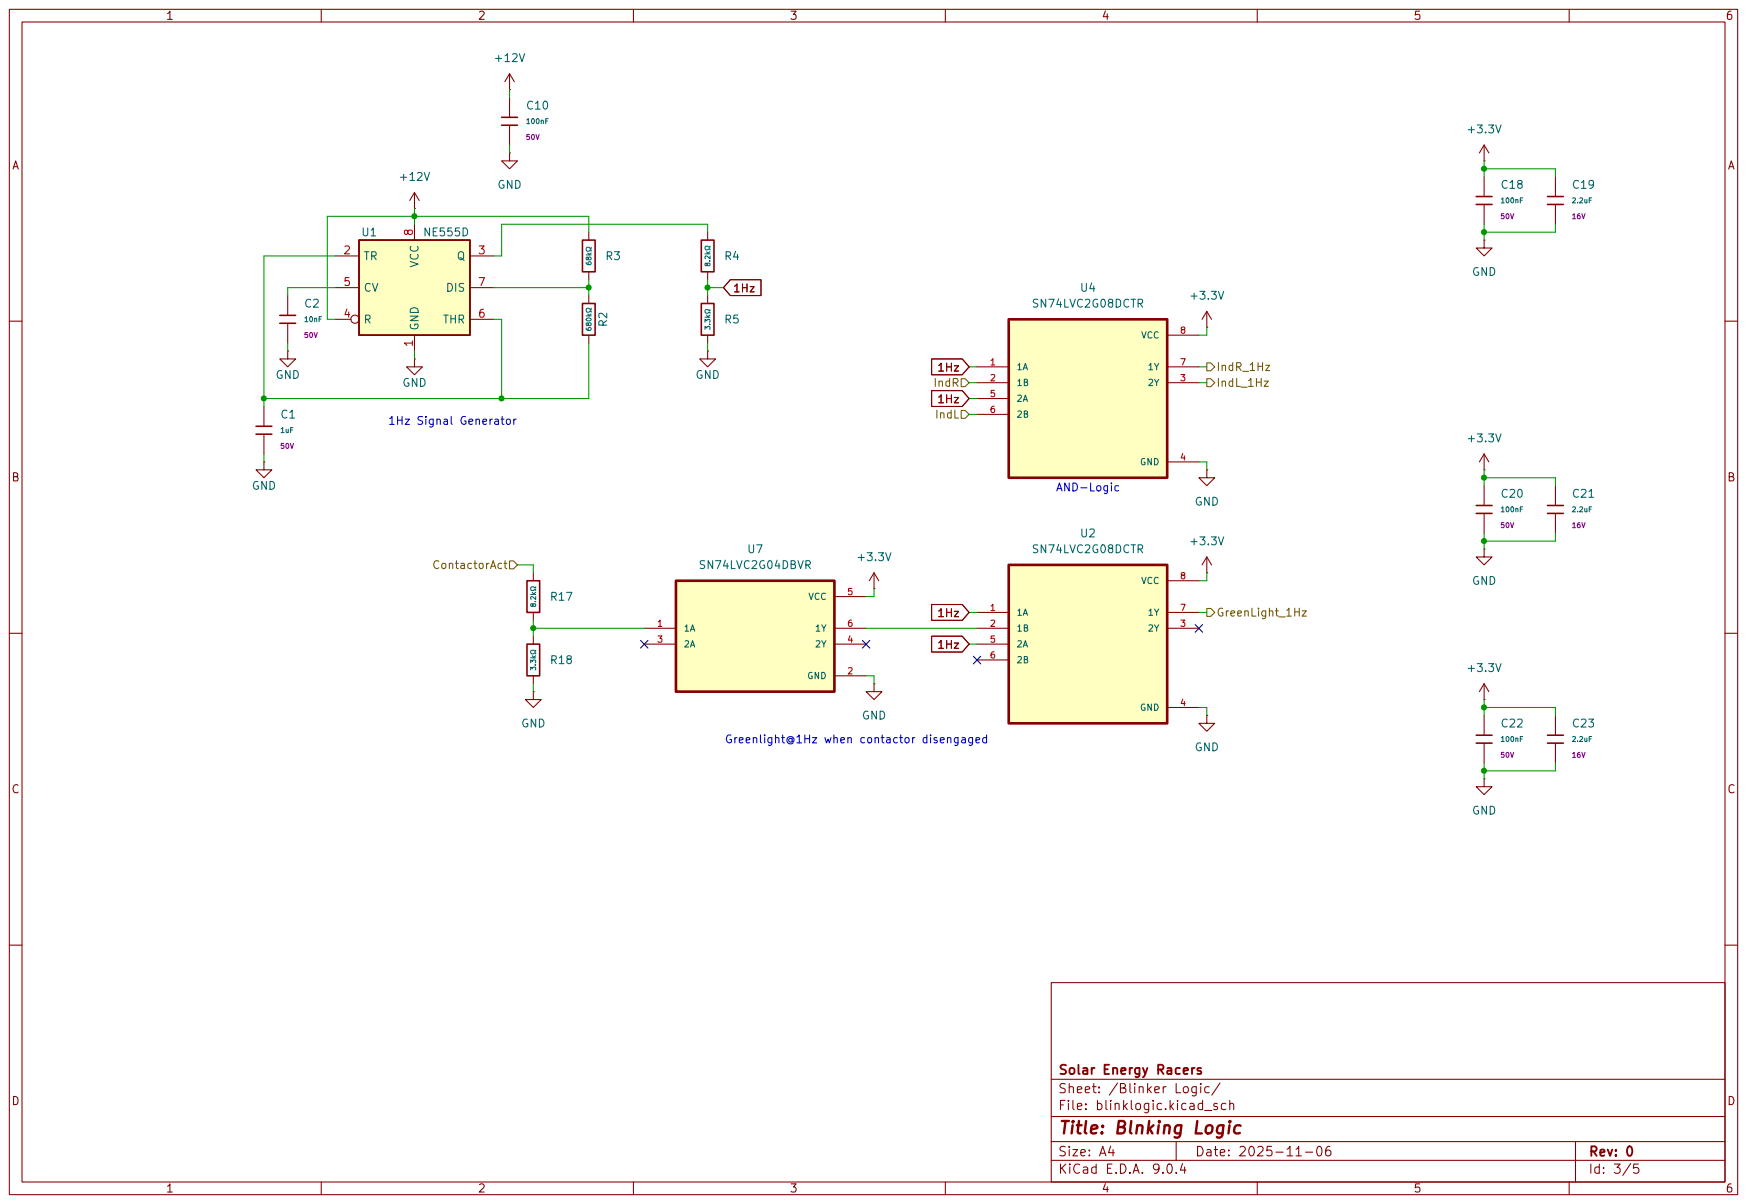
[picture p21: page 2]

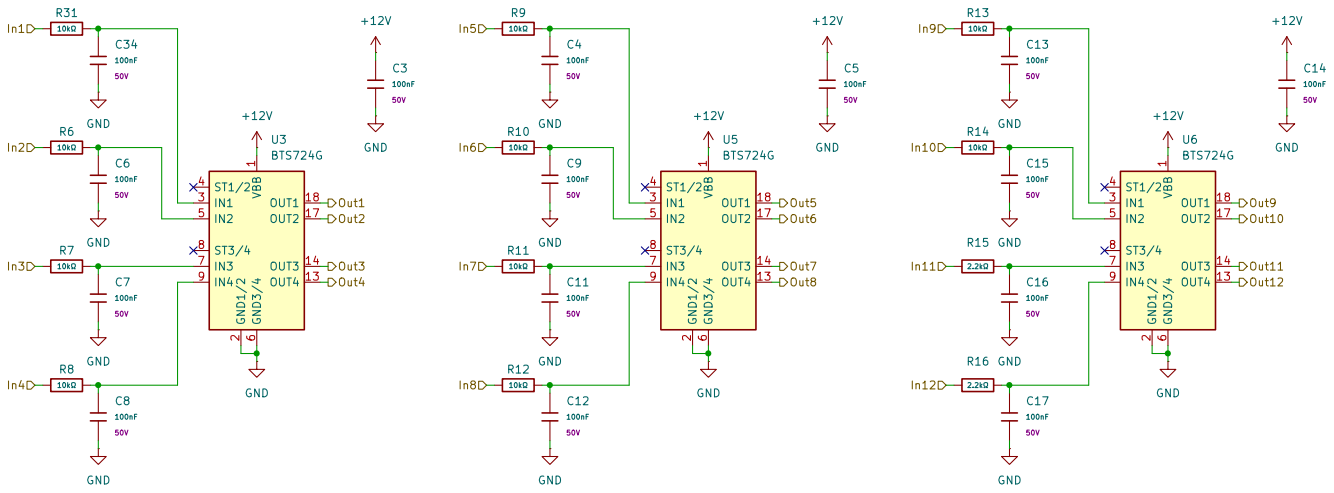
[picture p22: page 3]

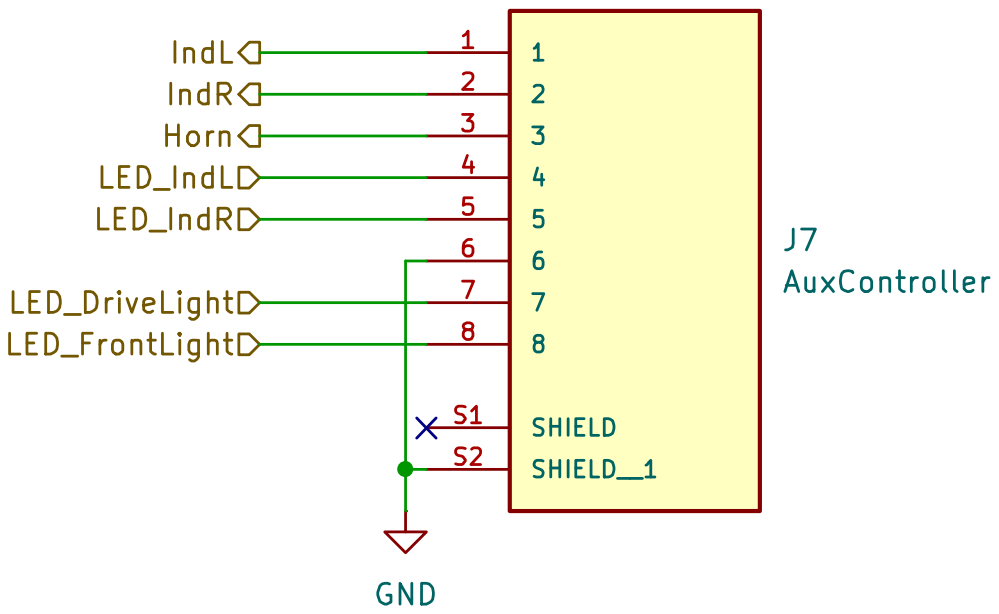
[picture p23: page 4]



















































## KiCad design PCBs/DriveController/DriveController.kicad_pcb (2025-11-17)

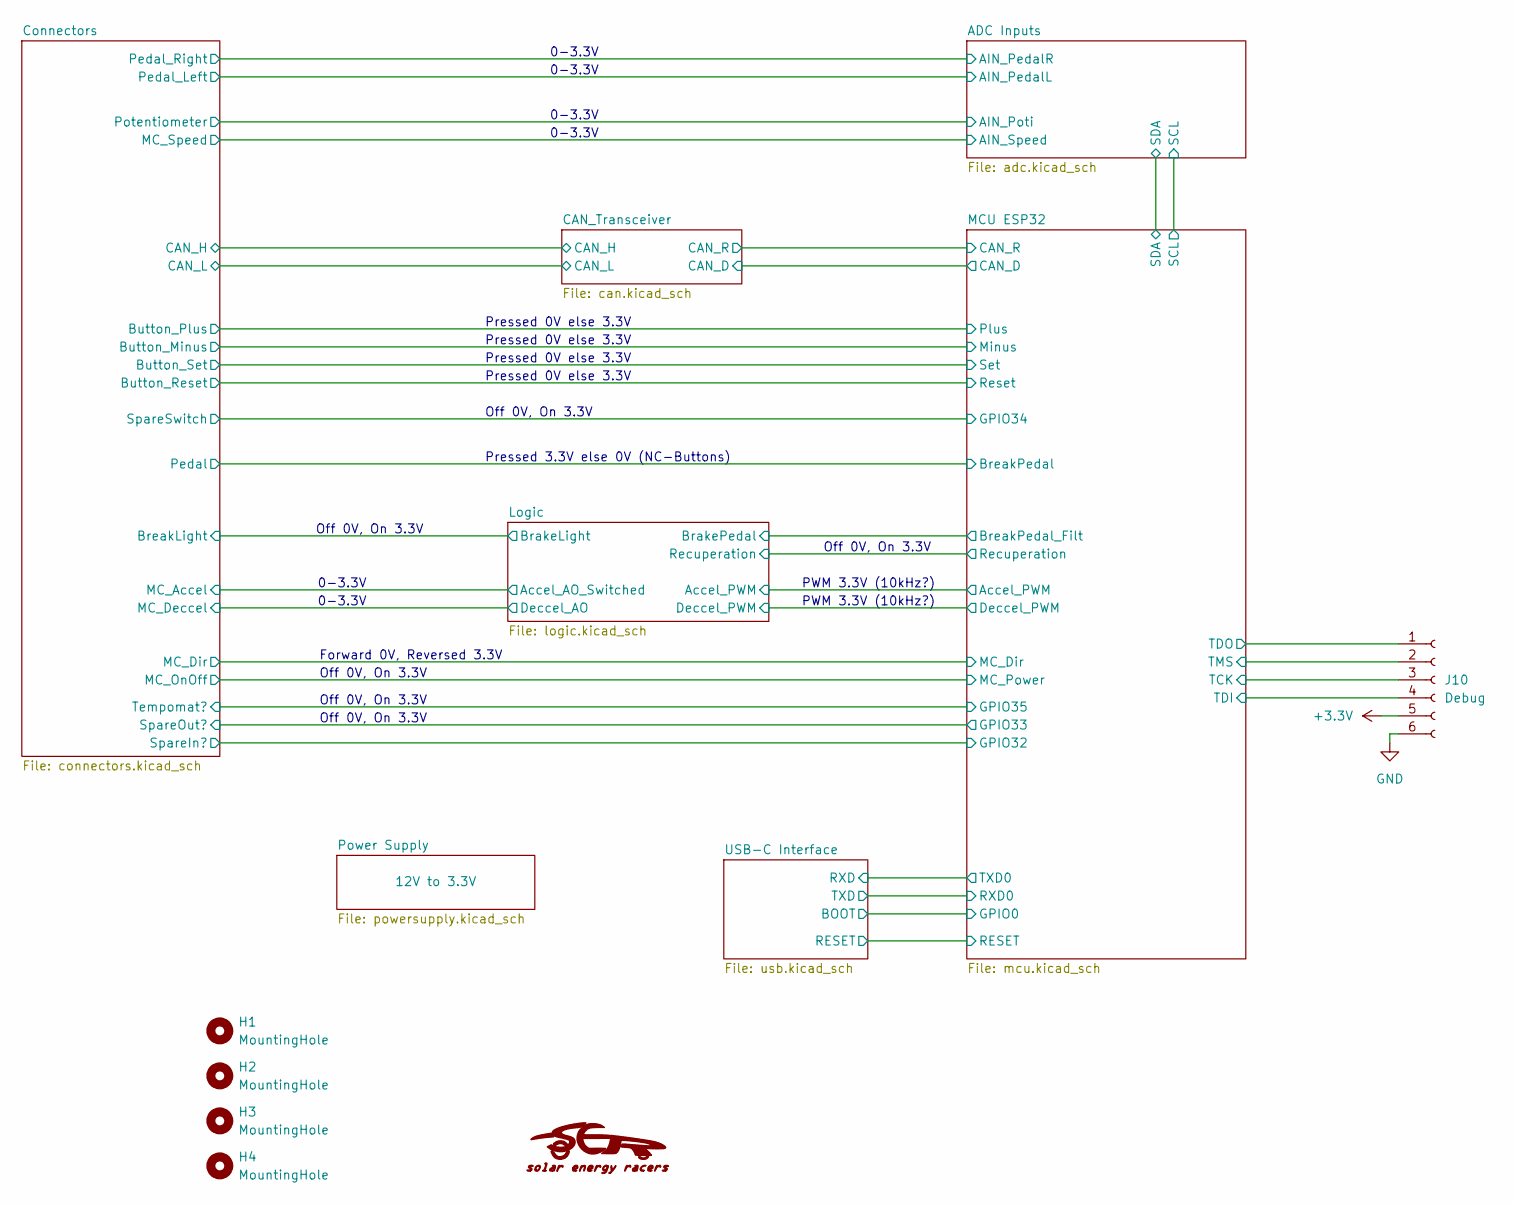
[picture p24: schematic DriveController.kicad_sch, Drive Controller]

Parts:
G1: LOGO; SER_Logo
H1, H2, H3, H4: MountingHole; MountingHole_3.2mm_M3_No_Copper
J10: Debug; PinSocket_1x06_P2.54mm_Vertical

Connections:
+3.3V: J10.5; also elsewhere on the board
/MCU ESP32/TCK: J10.3; also elsewhere on the board
/MCU ESP32/TDI: J10.4; also elsewhere on the board
/MCU ESP32/TDO: J10.1; also elsewhere on the board
/MCU ESP32/TMS: J10.2; also elsewhere on the board
GND: J10.6; also elsewhere on the board

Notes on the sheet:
Off 0V, On 3.3V
Forward 0V, Reversed 3.3V
PWM 3.3V (10kHz?)
0-3.3V
Pressed 3.3V else 0V (NC-Buttons)
Pressed 0V else 3.3V

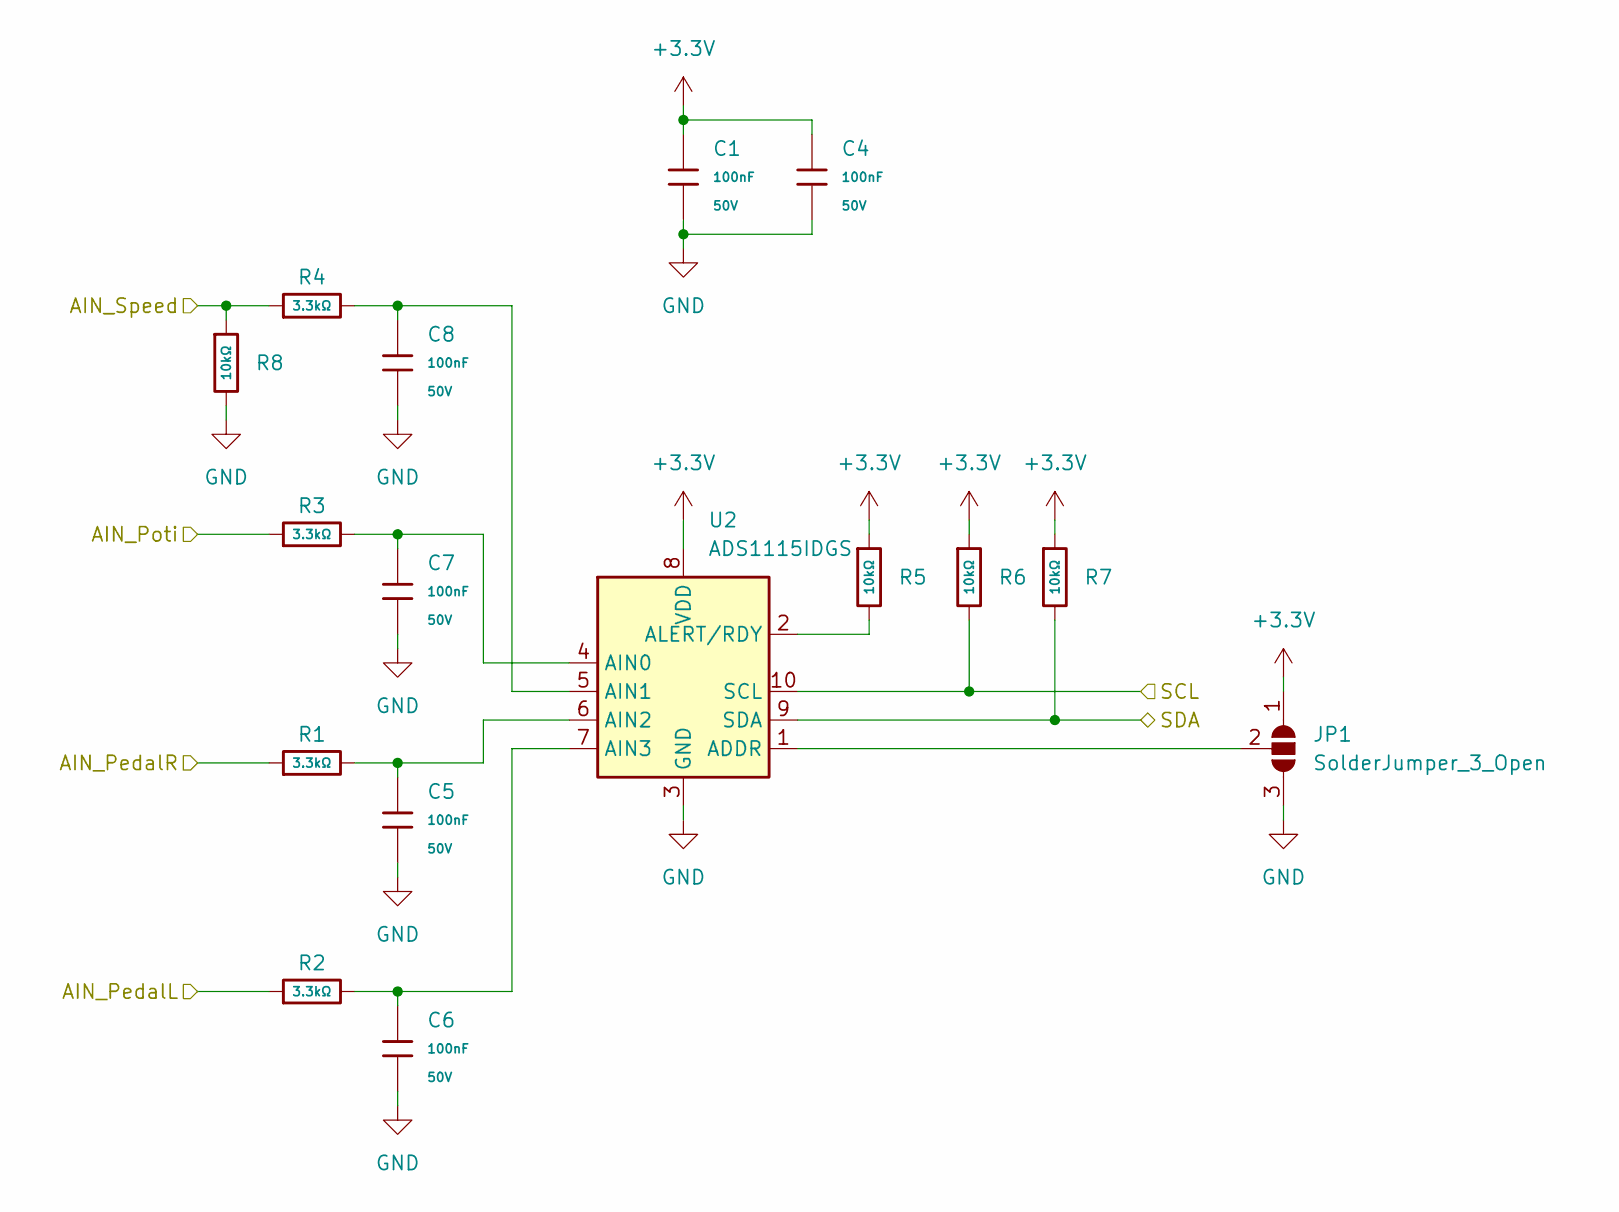
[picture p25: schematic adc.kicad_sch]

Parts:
C1, C4, C5, C6, C7, C8: 100nF; C_0603; Voltage Rated 50V; Tolerance ±10%; Part CC0603KRX7R9BB104; LCSC C14663
JP1: SolderJumper_3_Open; SolderJumper-3_P1.3mm_Open_Pad1.0x1.5mm_NumberLabels
R1, R2, R3, R4: 3.3kΩ; R_0603; Overload Voltage (Max) 75V; Tolerance ±1%; Part 0603WAF3301T5E; LCSC C22978
R5, R6, R7, R8: 10kΩ; R_0603; Overload Voltage (Max) 75V; Tolerance ±1%; Part 0603WAF1002T5E; LCSC C25804
U2: ADS1115IDGS; TSSOP-10_3x3mm_P0.5mm

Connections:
+3.3V: C1.1, C4.1, JP1.1 (A), R5.1, R6.1, R7.1, U2.8 (VDD); also elsewhere on the board
/ADC Inputs/AIN_PedalL: R2.1; also elsewhere on the board
/ADC Inputs/AIN_PedalR: R1.1; also elsewhere on the board
/ADC Inputs/AIN_Poti: R3.1; also elsewhere on the board
/ADC Inputs/AIN_Speed: R4.1, R8.1; also elsewhere on the board
/ADC Inputs/SCL: R6.2, U2.10 (SCL); also elsewhere on the board
/ADC Inputs/SDA: R7.2, U2.9 (SDA); also elsewhere on the board
GND: C1.2, C4.2, C5.2, C6.2, C7.2, C8.2, JP1.3 (B), R8.2, U2.3 (GND); also elsewhere on the board
unnamed: JP1.2 (C), U2.1 (ADDR)
unnamed: C7.1, R3.2, U2.4 (AIN0)
unnamed: C8.1, R4.2, U2.5 (AIN1)
unnamed: C5.1, R1.2, U2.6 (AIN2)
unnamed: C6.1, R2.2, U2.7 (AIN3)
unnamed: R5.2, U2.2 (ALERT/RDY)

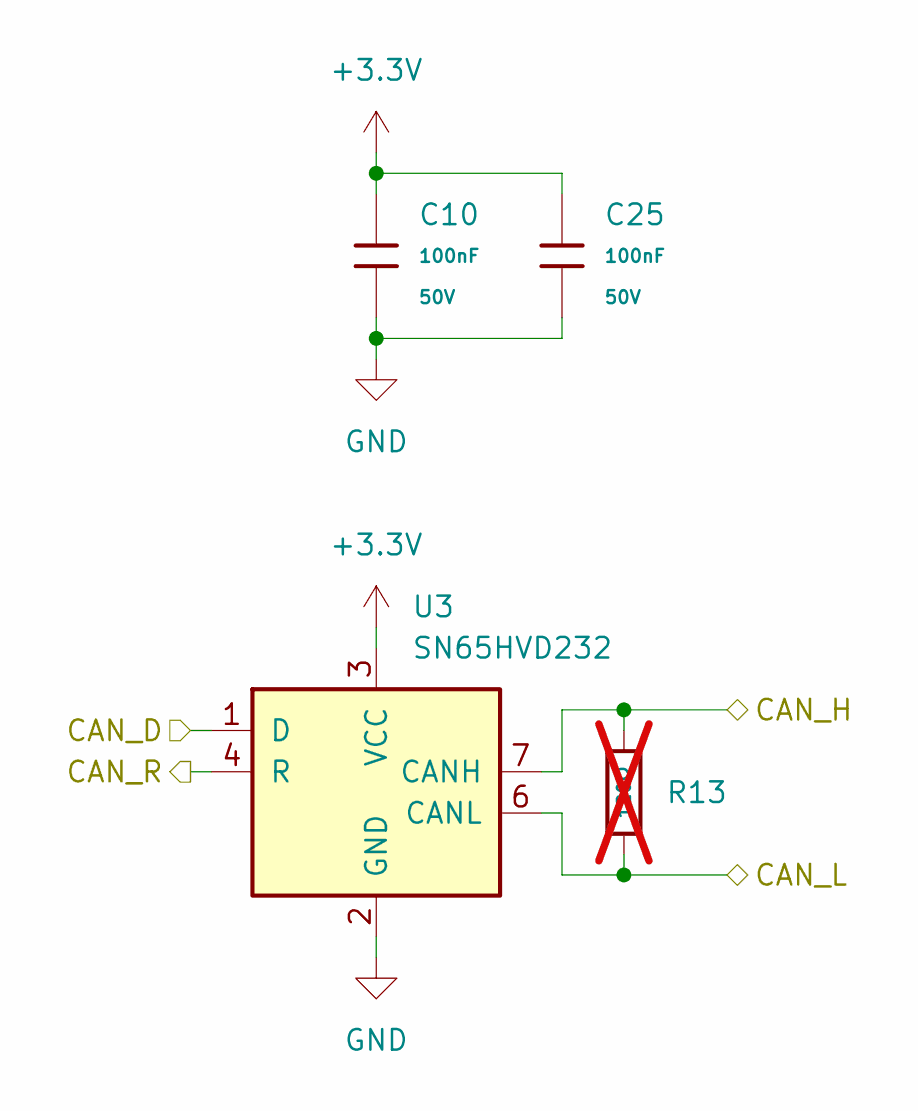
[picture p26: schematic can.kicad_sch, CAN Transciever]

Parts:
C10, C25: 100nF; C_0603; Voltage Rated 50V; Tolerance ±10%; Part CC0603KRX7R9BB104; LCSC C14663
R13: 120Ω; R_0603; Overload Voltage (Max) 75V; Tolerance ±1%; Part 0603WAF1200T5E; LCSC C22787; not fitted
U3: SN65HVD232; SOIC-8_3.9x4.9mm_P1.27mm

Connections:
+3.3V: C10.1, C25.1, U3.3 (VCC); also elsewhere on the board
/CAN_Transceiver/CAN_D: U3.1 (D); also elsewhere on the board
/CAN_Transceiver/CAN_H: R13.1, U3.7 (CANH); also elsewhere on the board
/CAN_Transceiver/CAN_L: R13.2, U3.6 (CANL); also elsewhere on the board
/CAN_Transceiver/CAN_R: U3.4 (R); also elsewhere on the board
GND: C10.2, C25.2, U3.2 (GND); also elsewhere on the board

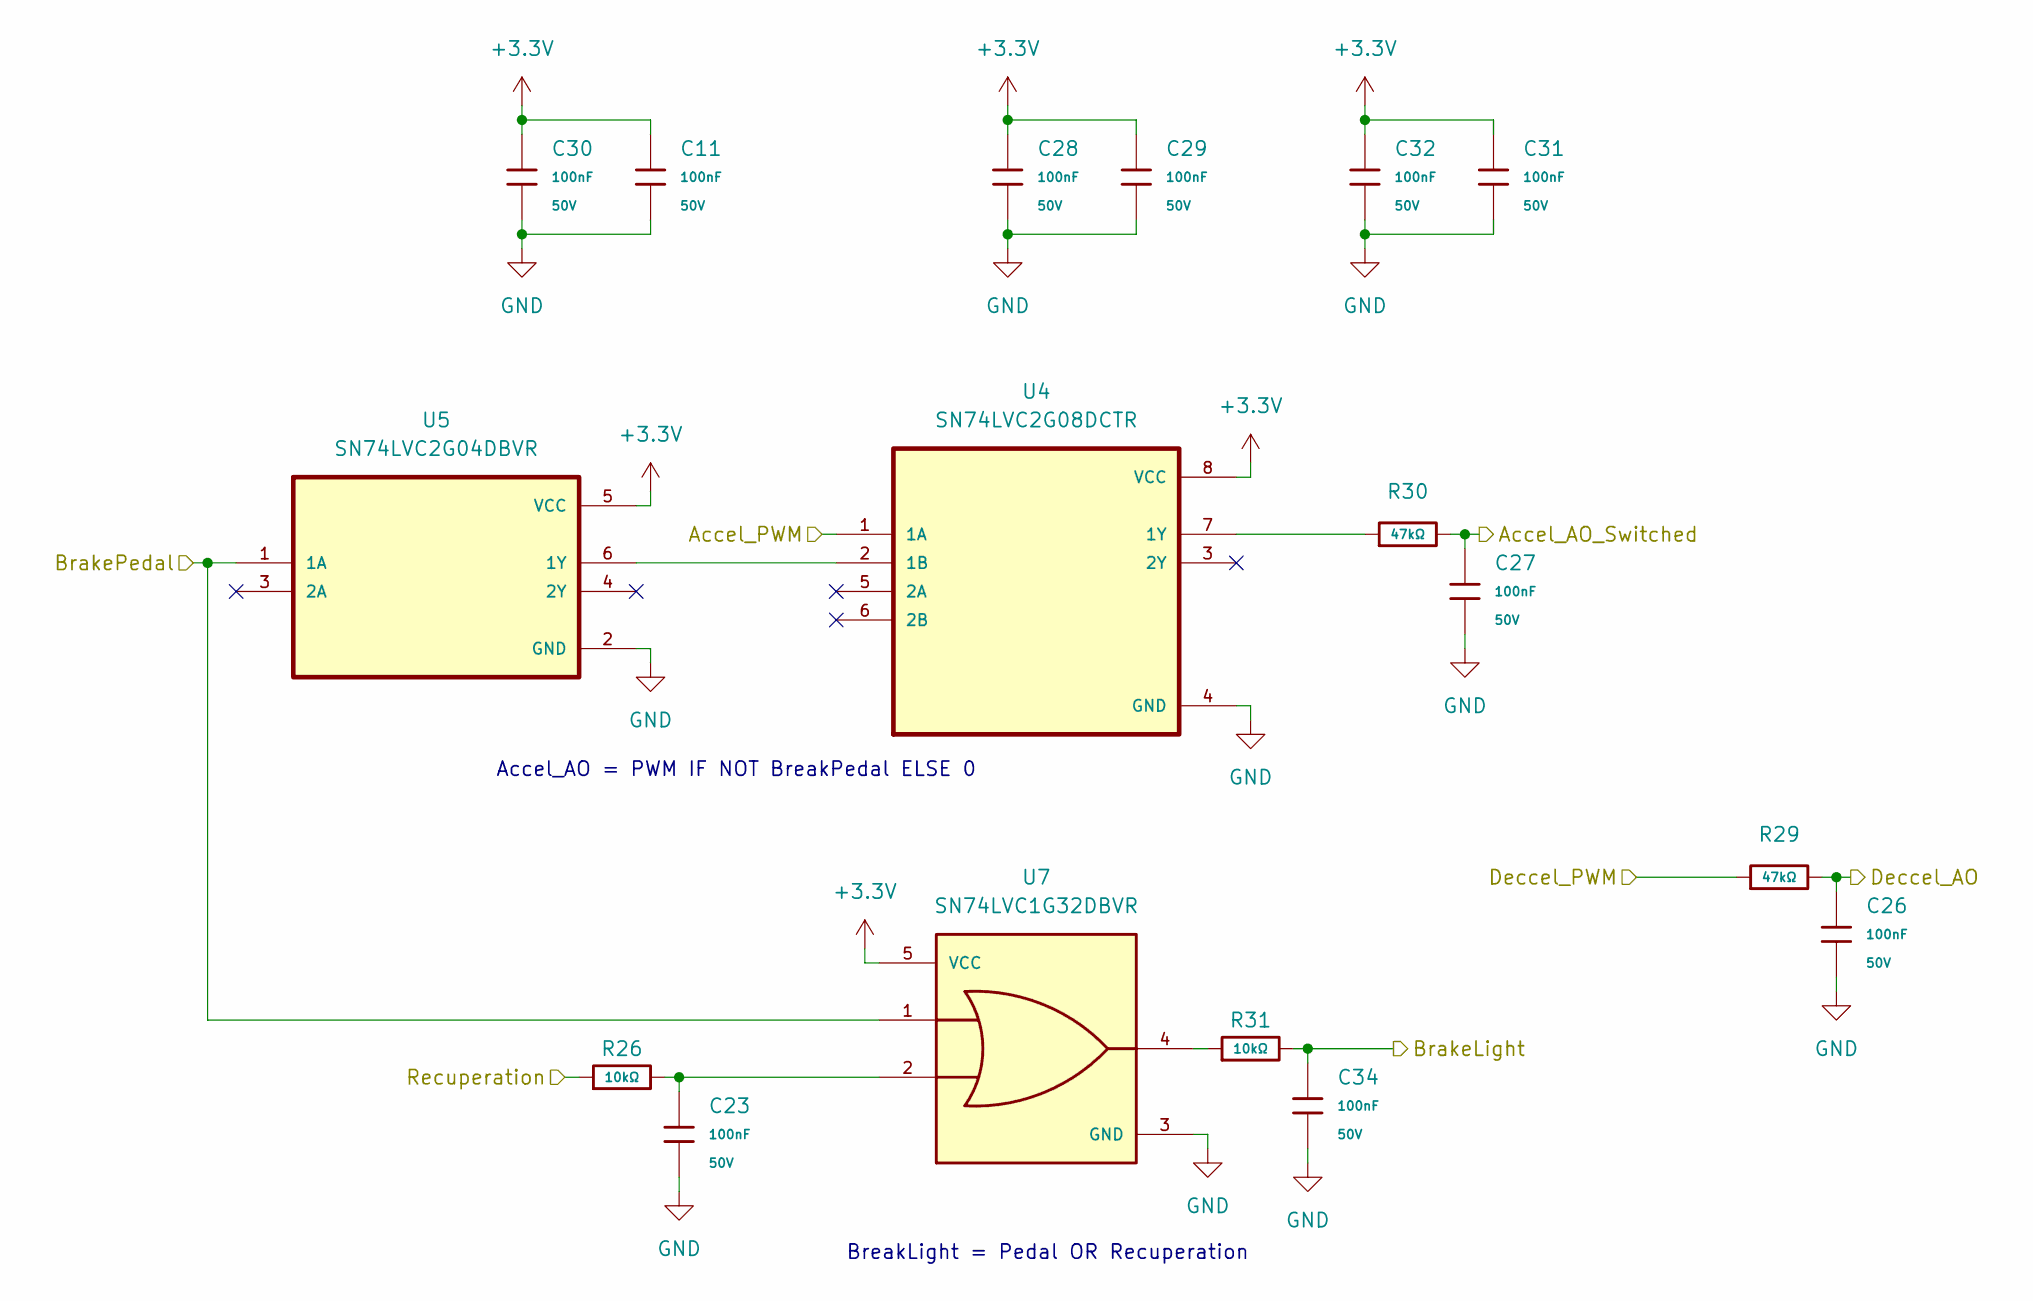
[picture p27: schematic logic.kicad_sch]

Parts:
C11, C23, C26, C27, C28, C29, C30, C31, C32, C34: 100nF; C_0603; Voltage Rated 50V; Tolerance ±10%; Part CC0603KRX7R9BB104; LCSC C14663
R26, R31: 10kΩ; R_0603; Overload Voltage (Max) 75V; Tolerance ±1%; Part 0603WAF1002T5E; LCSC C25804
R29, R30: 47kΩ; R_0603; Overload Voltage (Max) 75V; Tolerance ±1%; Part 0603WAF4702T5E; LCSC C25819
U4: SN74LVC2G08DCTR; VSSOP-8_2.3x2mm_P0.5mm_modified
U5: SN74LVC2G04DBVR; SOT-23-6
U7: SN74LVC1G32DBVR; SOT-23-5; PARTREV V

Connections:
+3.3V: C11.1, C28.1, C29.1, C30.1, C31.1, C32.1, U4.8 (VCC), U5.5 (VCC), U7.5 (VCC); also elsewhere on the board
/Connectors/BreakLight: C34.1, R31.2; also elsewhere on the board
/Connectors/MC_Accel: C27.1, R30.2; also elsewhere on the board
/Connectors/MC_Deccel: C26.1, R29.2; also elsewhere on the board
/Logic/Accel_PWM: U4.1 (1A); also elsewhere on the board
/Logic/BrakePedal: U5.1 (1A), U7.1; also elsewhere on the board
/Logic/Deccel_PWM: R29.1; also elsewhere on the board
/Logic/Recuperation: R26.1; also elsewhere on the board
GND: C11.2, C23.2, C26.2, C27.2, C28.2, C29.2, C30.2, C31.2, C32.2, C34.2, U4.4 (GND), U5.2 (GND), U7.3 (GND); also elsewhere on the board
unnamed: C23.1, R26.2, U7.2
unnamed: R31.1, U7.4
unnamed: U4.2 (1B), U5.6 (1Y)
unnamed: R30.1, U4.7 (1Y)

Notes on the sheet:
BreakLight = Pedal OR Recuperation
Accel_AO = PWM IF NOT BreakPedal ELSE 0

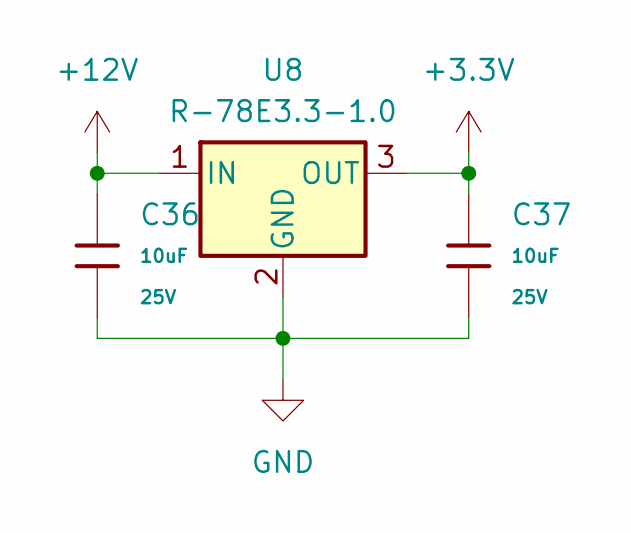
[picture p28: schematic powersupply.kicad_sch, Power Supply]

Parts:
C36, C37: 10uF; C_0805; Voltage Rated 25V; Tolerance ±10%; Part CL21A106KAYNNNE; LCSC C15850
U8: R-78E3.3-1.0; Converter_DCDC_RECOM_R-78E-0.5_THT

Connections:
+3.3V: C37.1, U8.3 (OUT); also elsewhere on the board
+12V: C36.1, U8.1 (IN); also elsewhere on the board
GND: C36.2, C37.2, U8.2 (GND); also elsewhere on the board

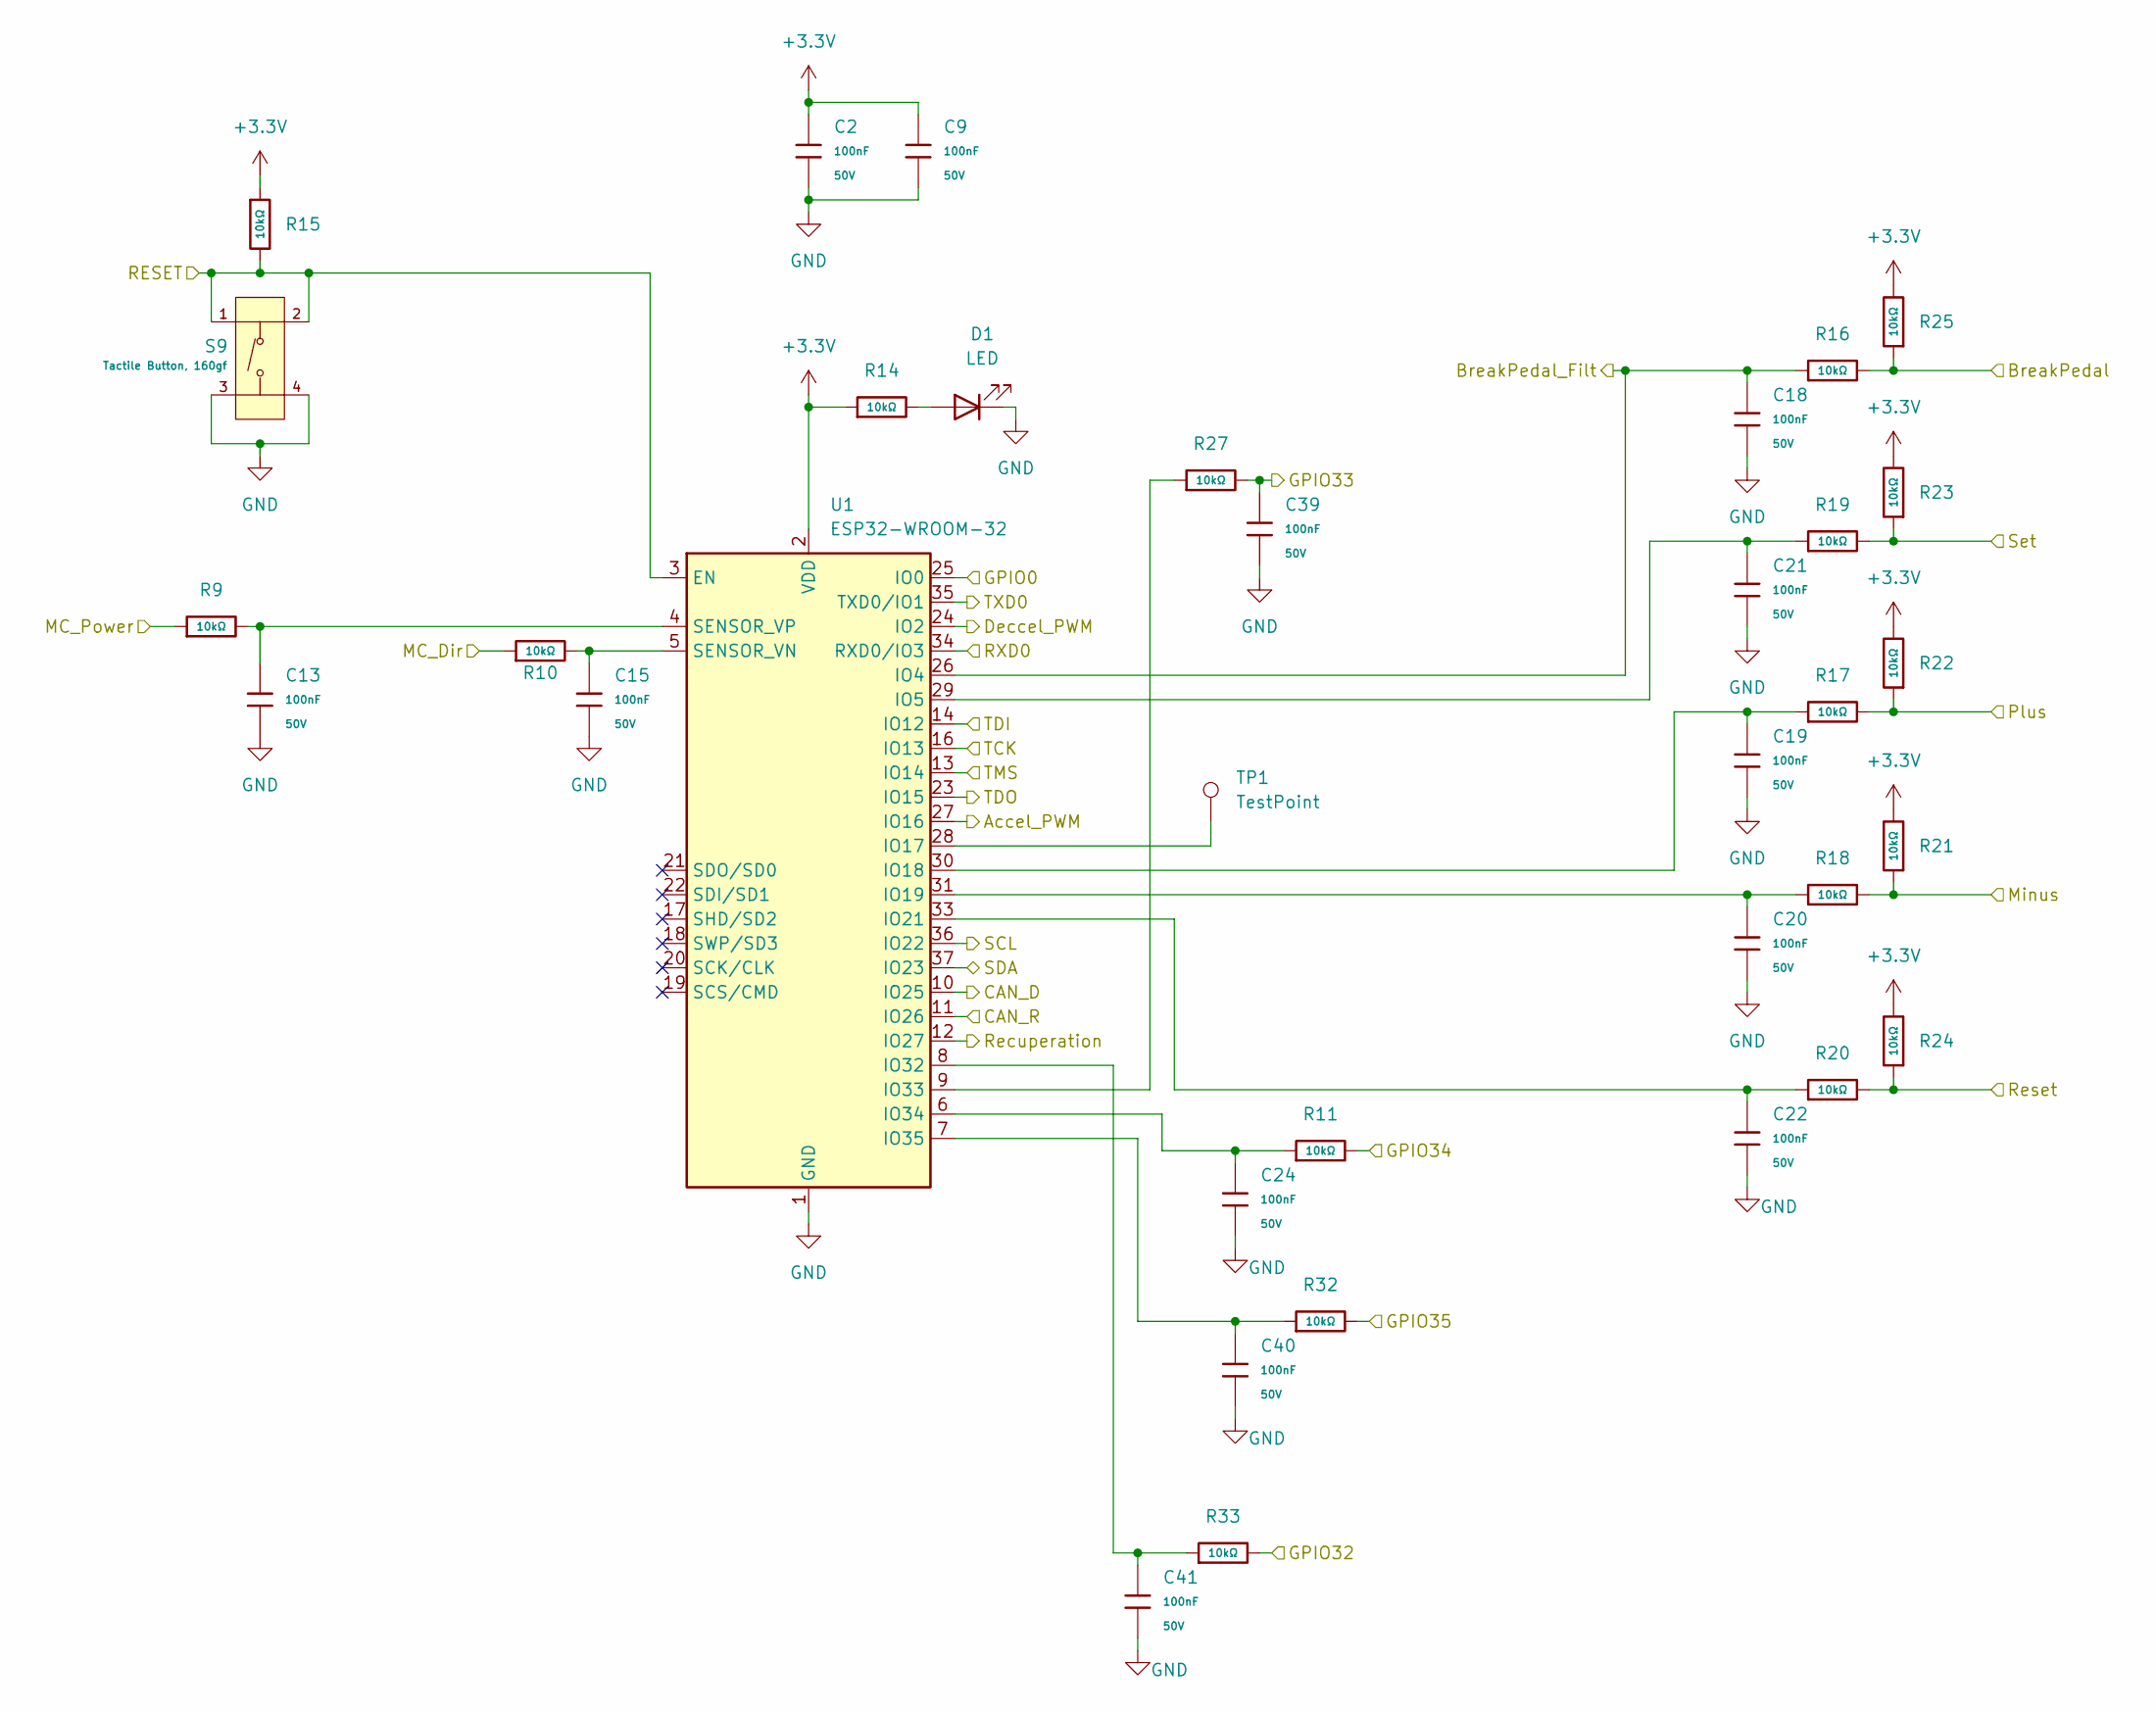
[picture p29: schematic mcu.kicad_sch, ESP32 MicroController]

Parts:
C2, C9, C13, C15, C18, C19, C20, C21, C22, C24, C39, C40, C41: 100nF; C_0603; Voltage Rated 50V; Tolerance ±10%; Part CC0603KRX7R9BB104; LCSC C14663
D1: LED; LED_0603_1608Metric
R9, R10, R11, R14, R15, R16, R17, R18, R19, R20, R21, R22, R23, R24, R25, R27, R32, R33: 10kΩ; R_0603; Overload Voltage (Max) 75V; Tolerance ±1%; Part 0603WAF1002T5E; LCSC C25804
S9: Tactile Button, 160gf; SW-SMD_4P-L5.1-W5.1-P3.70-LS6.5-TL-2; Voltage Rating (Dc) 12V; Part TS-1187A-B-A-B; LCSC C318884
TP1: TestPoint; TestPoint_Pad_1.0x1.0mm
U1: ESP32-WROOM-32

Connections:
+3.3V: C2.1, C9.1, R14.1, R15.1, R21.2, R22.2, R23.2, R24.2, R25.2, U1.2 (VDD); also elsewhere on the board
/ADC Inputs/SCL: U1.36 (IO22); also elsewhere on the board
/ADC Inputs/SDA: U1.37 (IO23); also elsewhere on the board
/CAN_Transceiver/CAN_D: U1.10 (IO25); also elsewhere on the board
/CAN_Transceiver/CAN_R: U1.11 (IO26); also elsewhere on the board
/Connectors/Button_Minus: R18.2, R21.1; also elsewhere on the board
/Connectors/Button_Plus: R17.2, R22.1; also elsewhere on the board
/Connectors/Button_Reset: R20.2, R24.1; also elsewhere on the board
/Connectors/Button_Set: R19.2, R23.1; also elsewhere on the board
/Connectors/MC_Dir: R10.1; also elsewhere on the board
/Connectors/MC_OnOff: R9.1; also elsewhere on the board
/Connectors/Pedal: R16.2, R25.1; also elsewhere on the board
/Connectors/SpareIn?: R33.2; also elsewhere on the board
/Connectors/SpareOut?: C39.1, R27.2; also elsewhere on the board
/Connectors/SpareSwitch: R11.2; also elsewhere on the board
/Connectors/Tempomat?: R32.2; also elsewhere on the board
/Logic/Accel_PWM: U1.27 (IO16); also elsewhere on the board
/Logic/BrakePedal: C18.1, R16.1, U1.26 (IO4); also elsewhere on the board
/Logic/Deccel_PWM: U1.24 (IO2); also elsewhere on the board
/Logic/Recuperation: U1.12 (IO27); also elsewhere on the board
/MCU ESP32/GPIO0: U1.25 (IO0); also elsewhere on the board
/MCU ESP32/RESET: R15.2, S9.1 (A), S9.2 (B), U1.3 (EN); also elsewhere on the board
/MCU ESP32/RXD0: U1.34 (RXD0/IO3); also elsewhere on the board
/MCU ESP32/TCK: U1.16 (IO13); also elsewhere on the board
/MCU ESP32/TDI: U1.14 (IO12); also elsewhere on the board
/MCU ESP32/TDO: U1.23 (IO15); also elsewhere on the board
/MCU ESP32/TMS: U1.13 (IO14); also elsewhere on the board
/MCU ESP32/TXD0: U1.35 (TXD0/IO1); also elsewhere on the board
GND: C2.2, C9.2, C13.2, C15.2, C18.2, C19.2, C20.2, C21.2, C22.2, C24.2, C39.2, C40.2, C41.2, D1.1 (K), S9.3 (C), S9.4 (D), U1.1 (GND), U1.15 (GND), U1.38 (GND), U1.39 (GND); also elsewhere on the board
unnamed: D1.2 (A), R14.2
unnamed: C21.1, R19.1, U1.29 (IO5)
unnamed: TP1.1, U1.28 (IO17)
unnamed: C19.1, R17.1, U1.30 (IO18)
unnamed: C20.1, R18.1, U1.31 (IO19)
unnamed: C22.1, R20.1, U1.33 (IO21)
unnamed: C41.1, R33.1, U1.8 (IO32)
unnamed: R27.1, U1.9 (IO33)
unnamed: C24.1, R11.1, U1.6 (IO34)
unnamed: C40.1, R32.1, U1.7 (IO35)
unnamed: C15.1, R10.2, U1.5 (SENSOR_VN)
unnamed: C13.1, R9.2, U1.4 (SENSOR_VP)

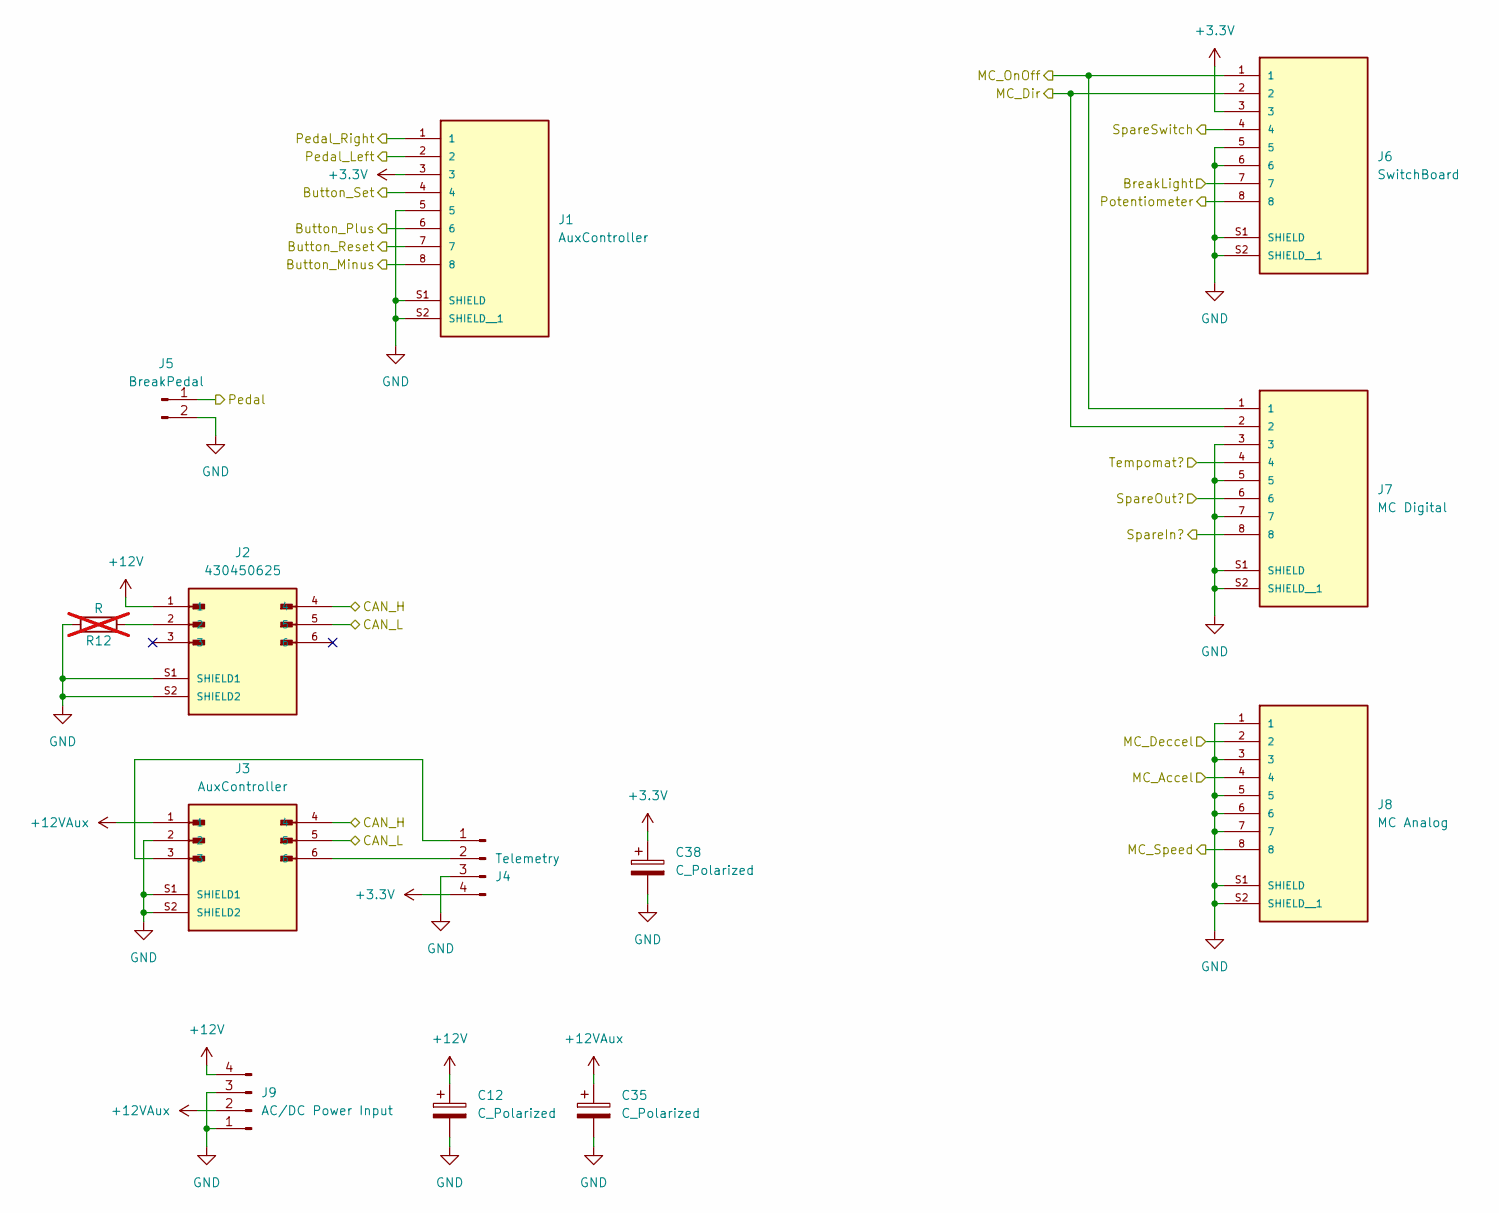
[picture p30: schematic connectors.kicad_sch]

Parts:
C12, C35, C38: C_Polarized; CP_Radial_D8.0mm_P5.00mm
J1: AuxController; CUI_CRJ027-1-TH; PARTREV 1.0
J2: 430450625; MOLEX_430450625; PARTREV H4
J3: AuxController; MOLEX_430450625; PARTREV H4
J4: Telemetry; PhoenixContact_MCV_1,5_4-G-3.5_1x04_P3.50mm_Vertical
J5: BreakPedal; PhoenixContact_MCV_1,5_2-G-3.5_1x02_P3.50mm_Vertical
J6: SwitchBoard; CUI_CRJ027-1-TH; PARTREV 1.0
J7: MC Digital; CUI_CRJ027-1-TH; PARTREV 1.0
J8: MC Analog; CUI_CRJ027-1-TH; PARTREV 1.0
J9: AC/DC Power Input; PhoenixContact_MCV_1,5_4-G-3.5_1x04_P3.50mm_Vertical
R12: R; R_1206_3216Metric; not fitted

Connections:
+3.3V: C38.1, J1.3, J4.4, J6.3; also elsewhere on the board
+12V: C12.1, J2.1, J9.4; also elsewhere on the board
+12VAux: C35.1, J3.1, J9.2
/ADC Inputs/AIN_PedalL: J1.2; also elsewhere on the board
/ADC Inputs/AIN_PedalR: J1.1; also elsewhere on the board
/ADC Inputs/AIN_Poti: J6.8; also elsewhere on the board
/ADC Inputs/AIN_Speed: J8.8; also elsewhere on the board
/CAN_Transceiver/CAN_H: J2.4, J3.4; also elsewhere on the board
/CAN_Transceiver/CAN_L: J2.5, J3.5; also elsewhere on the board
/Connectors/BreakLight: J6.7; also elsewhere on the board
/Connectors/Button_Minus: J1.8; also elsewhere on the board
/Connectors/Button_Plus: J1.6; also elsewhere on the board
/Connectors/Button_Reset: J1.7; also elsewhere on the board
/Connectors/Button_Set: J1.4; also elsewhere on the board
/Connectors/MC_Accel: J8.4; also elsewhere on the board
/Connectors/MC_Deccel: J8.2; also elsewhere on the board
/Connectors/MC_Dir: J6.2, J7.2; also elsewhere on the board
/Connectors/MC_OnOff: J6.1, J7.1; also elsewhere on the board
/Connectors/Pedal: J5.1; also elsewhere on the board
/Connectors/SpareIn?: J7.8; also elsewhere on the board
/Connectors/SpareOut?: J7.6; also elsewhere on the board
/Connectors/SpareSwitch: J6.4; also elsewhere on the board
/Connectors/Tempomat?: J7.4; also elsewhere on the board
GND: C12.2, C35.2, C38.2, J1.5, J1.S1 (SHIELD), J1.S2 (SHIELD__1), J2.S1 (SHIELD1), J2.S2 (SHIELD2), J3.2, J3.S1 (SHIELD1), J3.S2 (SHIELD2), J4.3, J5.2, J6.5, J6.6, J6.S1 (SHIELD), J6.S2 (SHIELD__1), J7.3, J7.5, J7.7, J7.S1 (SHIELD), J7.S2 (SHIELD__1), J8.1, J8.3, J8.5, J8.6, J8.7, J8.S1 (SHIELD), J8.S2 (SHIELD__1), J9.1, J9.3, R12.2; also elsewhere on the board
unnamed: J2.2, R12.1
unnamed: J3.3, J4.1
unnamed: J3.6, J4.2

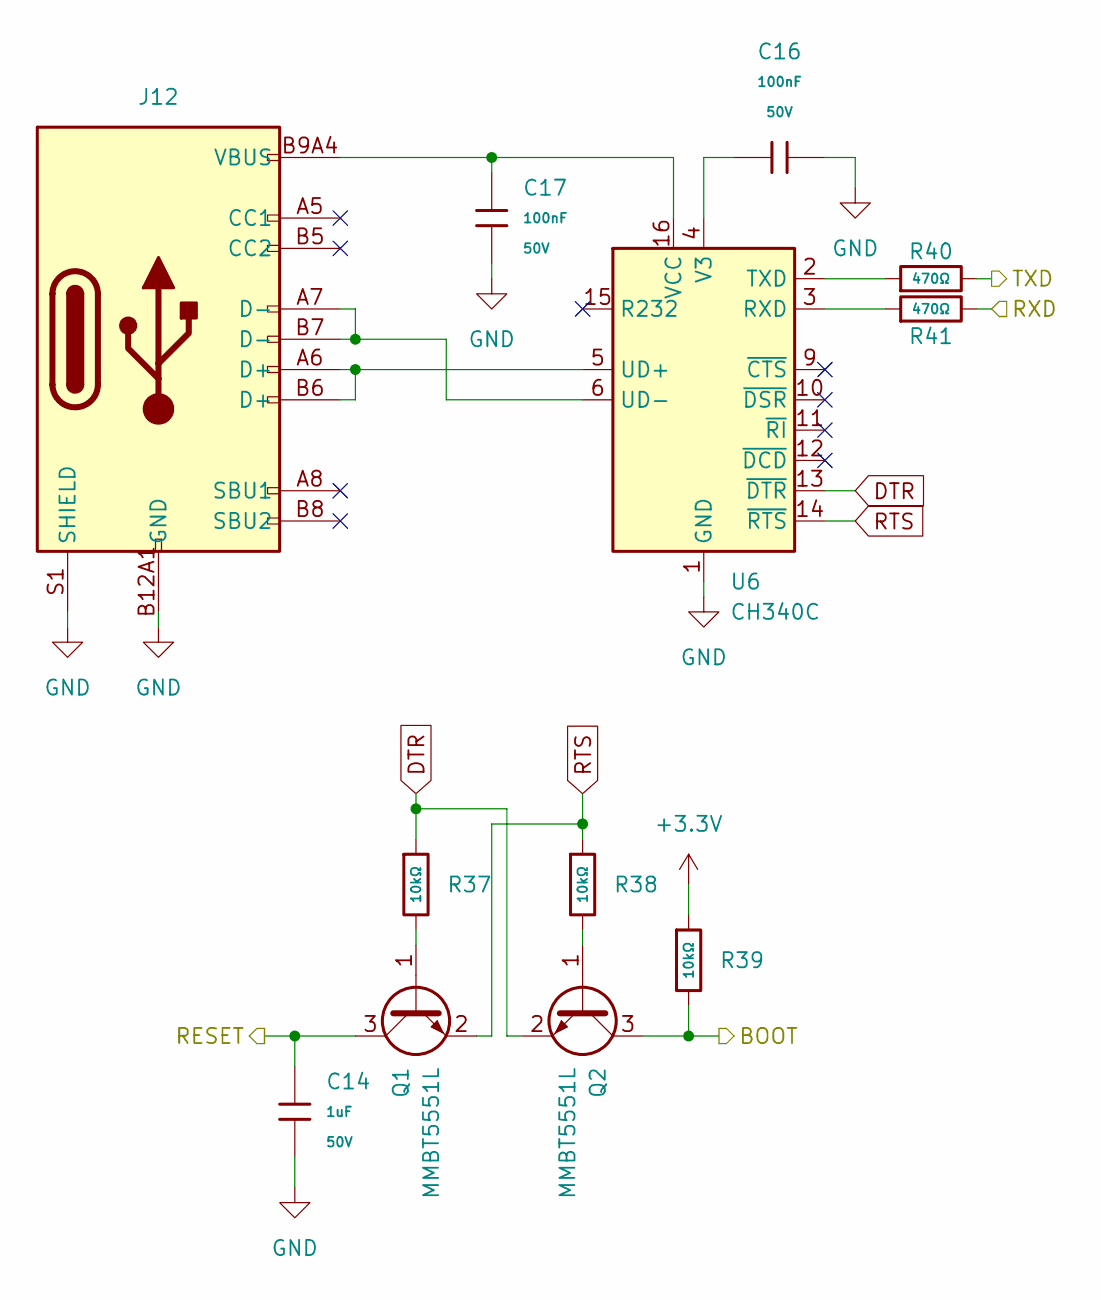
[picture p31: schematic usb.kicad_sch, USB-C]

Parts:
C14: 1uF; C_0603; Voltage Rated 50V; Tolerance ±10%; Part CL10A105KB8NNNC; LCSC C15849
C16, C17: 100nF; C_0603; Voltage Rated 50V; Tolerance ±10%; Part CC0603KRX7R9BB104; LCSC C14663
J12: Connector, USB-TYPE-C-16P; TYPE-C-SMD_HX-TYPE-C-16PIN; LCSC C2927039
Q1, Q2: MMBT5551L; SOT-23
R37, R38, R39: 10kΩ; R_0603; Overload Voltage (Max) 75V; Tolerance ±1%; Part 0603WAF1002T5E; LCSC C25804
R40, R41: 470Ω; R_0603; Overload Voltage (Max) 75V; Tolerance ±1%; Part 0603WAF4700T5E; LCSC C23179
U6: CH340C; SOIC-16_3.9x9.9mm_P1.27mm

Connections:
+3.3V: R39.1; also elsewhere on the board
/MCU ESP32/GPIO0: Q2.3 (C), R39.2; also elsewhere on the board
/MCU ESP32/RESET: C14.1, Q1.3 (C); also elsewhere on the board
/MCU ESP32/RXD0: R40.2; also elsewhere on the board
/MCU ESP32/TXD0: R41.2; also elsewhere on the board
DTR: Q2.2 (E), R37.1, U6.13 (~DTR)
GND: C14.2, C16.2, C17.1, J12.A12B1 (GND), J12.B12A1 (GND), J12.S1 (SHIELD), U6.1 (GND); also elsewhere on the board
unnamed: Q1.1 (B), R37.2
unnamed: Q2.1 (B), R38.2
unnamed: R41.1, U6.3 (RXD)
unnamed: R40.1, U6.2 (TXD)
unnamed: J12.A6 (D+), J12.B6 (D+), U6.5 (UD+)
unnamed: J12.A7 (D-), J12.B7 (D-), U6.6 (UD-)
unnamed: C16.1, U6.4 (V3)
unnamed: C17.2, J12.A9B4 (VBUS), J12.B9A4 (VBUS), U6.16 (VCC)
RTS: Q1.2 (E), R38.1, U6.14 (~RTS)

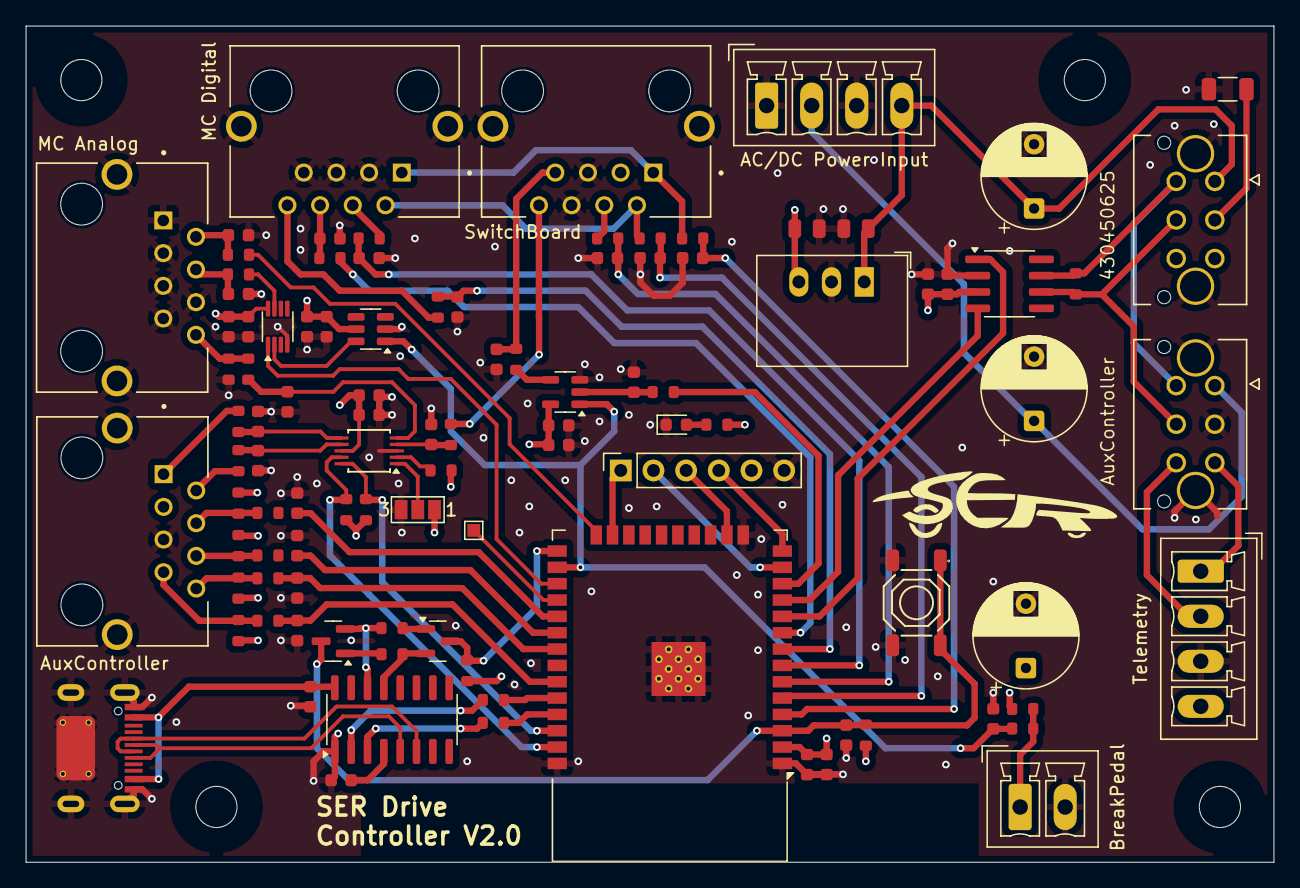
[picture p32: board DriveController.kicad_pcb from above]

Board: 4 copper layers, 97.0 x 65.0 mm, 106 parts (0 on the bottom side), 75 nets.

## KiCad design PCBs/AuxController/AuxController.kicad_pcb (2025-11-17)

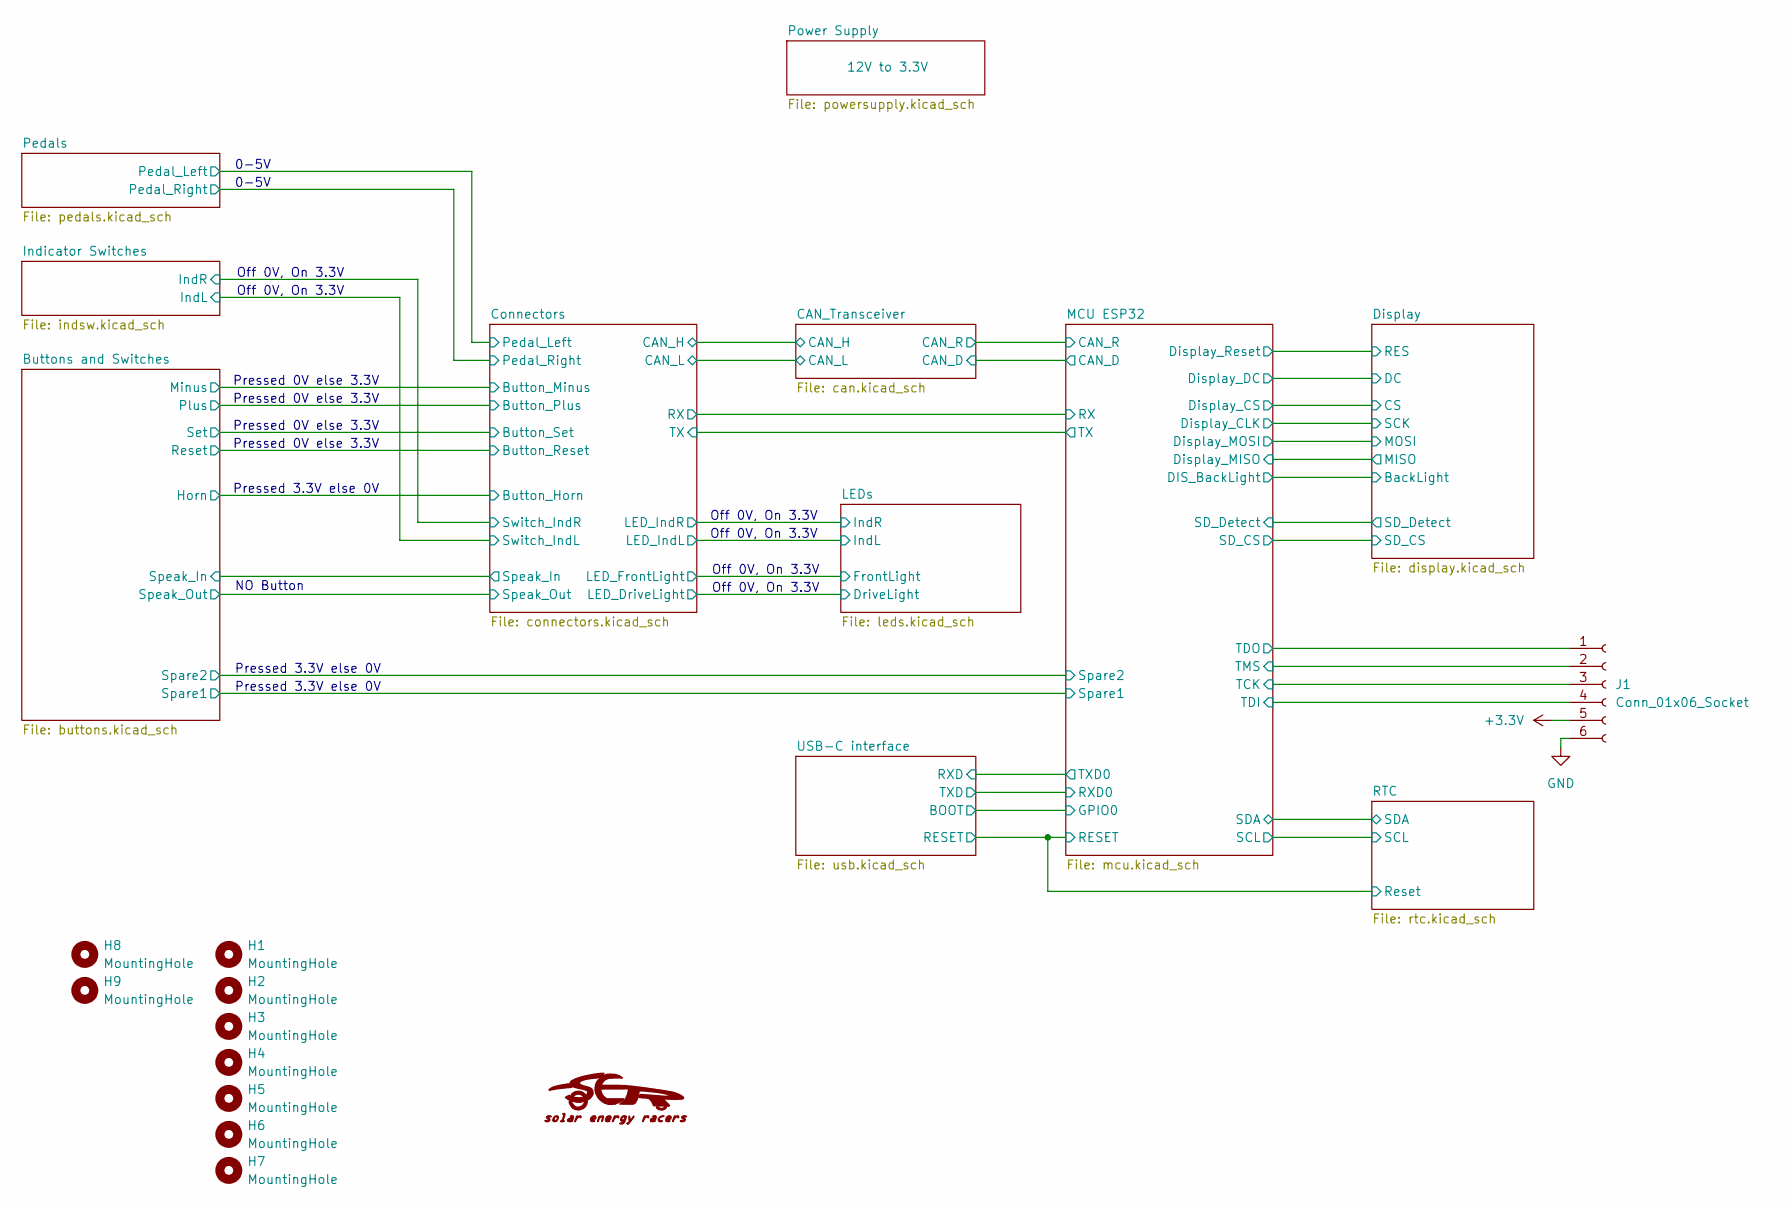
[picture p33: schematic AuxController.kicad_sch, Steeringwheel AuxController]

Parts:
G1: LOGO; SER_Logo
H1, H2, H3, H4, H5, H6, H7: MountingHole; MountingHole_3.2mm_M3_No_Copper
H8, H9: MountingHole; MountingHole_6.5mm_mod
J1: Conn_01x06_Socket; PinSocket_1x06_P2.54mm_Horizontal

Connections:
+3.3V: J1.5; also elsewhere on the board
/MCU ESP32/TCK: J1.3; also elsewhere on the board
/MCU ESP32/TDI: J1.4; also elsewhere on the board
/MCU ESP32/TDO: J1.1; also elsewhere on the board
/MCU ESP32/TMS: J1.2; also elsewhere on the board
GND: J1.6; also elsewhere on the board

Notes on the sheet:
Pressed 0V else 3.3V
0-5V
NO Button
Off 0V, On 3.3V
Pressed 3.3V else 0V

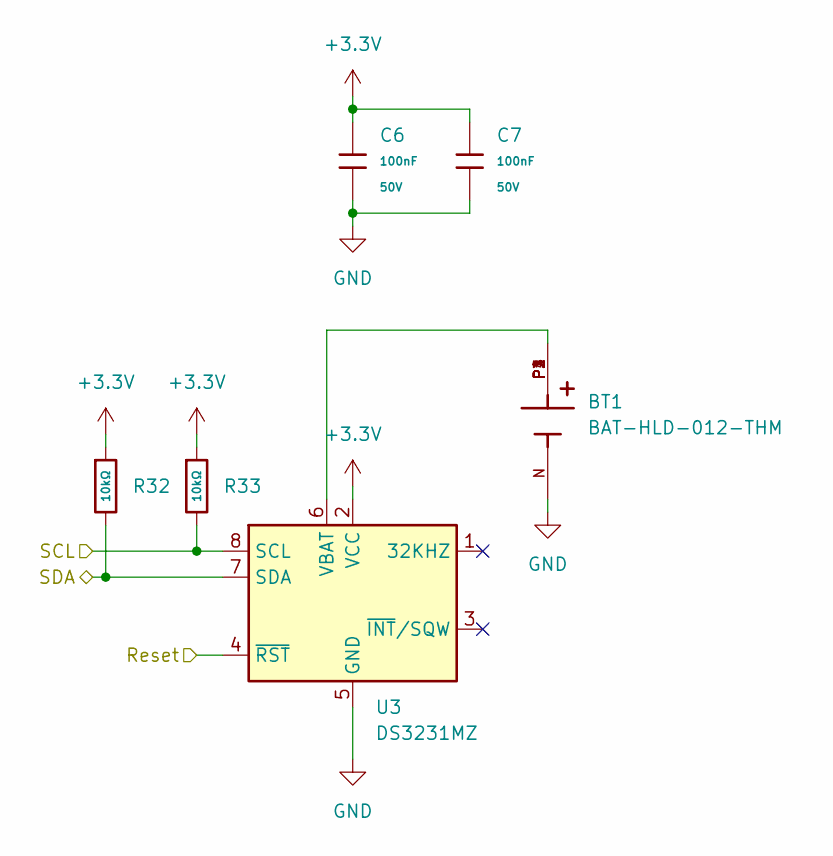
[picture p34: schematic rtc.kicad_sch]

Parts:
BT1: BAT-HLD-012-THM; BAT_BAT-HLD-012-THM
C6, C7: 100nF; C_0603; Voltage Rated 50V; Tolerance ±10%; Part CC0603KRX7R9BB104; LCSC C14663
R32, R33: 10kΩ; R_0603; Overload Voltage (Max) 75V; Tolerance ±1%; Part 0603WAF1002T5E; LCSC C25804
U3: DS3231MZ; SOIC-8_3.9x4.9mm_P1.27mm

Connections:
+3.3V: C6.1, C7.1, R32.1, R33.1, U3.2 (VCC); also elsewhere on the board
/MCU ESP32/RESET: U3.4 (~RST); also elsewhere on the board
/MCU ESP32/SCL: R33.2, U3.8 (SCL); also elsewhere on the board
/MCU ESP32/SDA: R32.2, U3.7 (SDA); also elsewhere on the board
GND: BT1.N, C6.2, C7.2, U3.5 (GND); also elsewhere on the board
unnamed: BT1.P1, BT1.P2, BT1.P3, BT1.P4, U3.6 (VBAT)

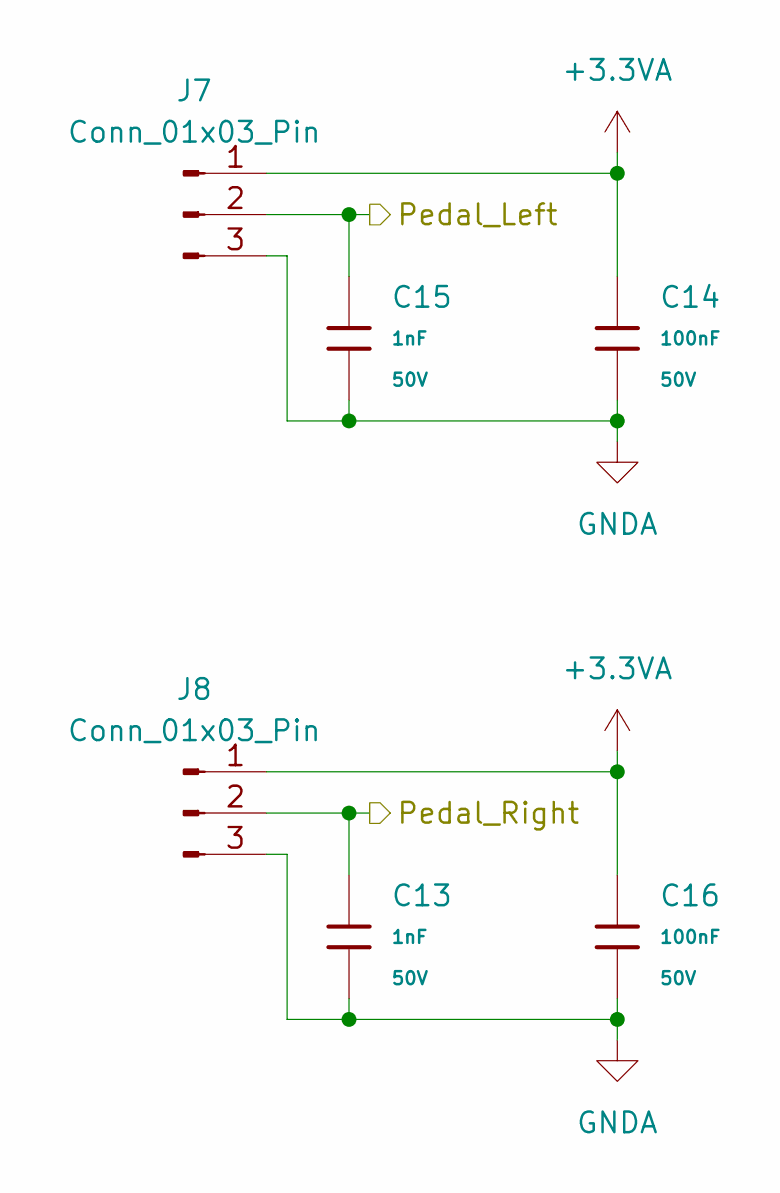
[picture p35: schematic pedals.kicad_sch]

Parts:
C13, C15: 1nF; C_0603; Voltage Rated 50V; Tolerance ±10%; Part CL10B102KB8NNNC; LCSC C1588
C14, C16: 100nF; C_0603; Voltage Rated 50V; Tolerance ±10%; Part CC0603KRX7R9BB104; LCSC C14663
J7, J8: Conn_01x03_Pin; PinHeader_1x03_P2.54mm_Vertical

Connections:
+3.3VA: C14.1, C16.1, J7.1, J8.1; also elsewhere on the board
/Connectors/Pedal_Left: C15.1, J7.2; also elsewhere on the board
/Connectors/Pedal_Right: C13.1, J8.2; also elsewhere on the board
GNDA: C13.2, C14.2, C15.2, C16.2, J7.3, J8.3; also elsewhere on the board


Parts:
C3, C4, C5: 100nF; C_0603; Voltage Rated 50V; Tolerance ±10%; Part CC0603KRX7R9BB104; LCSC C14663
D1: LED; LED_0603_1608Metric
R22, R23: 10kΩ; R_0603; Overload Voltage (Max) 75V; Tolerance ±1%; Part 0603WAF1002T5E; LCSC C25804
S9: Tactile Button, 160gf; SW-SMD_4P-L5.1-W5.1-P3.70-LS6.5-TL-2; Voltage Rating (Dc) 12V; Part TS-1187A-B-A-B; LCSC C318884
S10: EG2208; SW_EG2208; PARTREV C
U2: ESP32-WROOM-32

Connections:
+3.3V: C3.1, C4.1, R22.1, R23.1, U2.2 (VDD); also elsewhere on the board
/Buttons and Switches/Spare1: U2.24 (IO2); also elsewhere on the board
/Buttons and Switches/Spare2: U2.12 (IO27); also elsewhere on the board
/CAN_Transceiver/CAN_D: U2.10 (IO25); also elsewhere on the board
/CAN_Transceiver/CAN_R: U2.11 (IO26); also elsewhere on the board
/Connectors/RX: U2.27 (IO16); also elsewhere on the board
/Connectors/TX: U2.28 (IO17); also elsewhere on the board
/Display/BackLight: U2.9 (IO33); also elsewhere on the board
/Display/CS: U2.8 (IO32); also elsewhere on the board
/Display/DC: U2.26 (IO4); also elsewhere on the board
/Display/MISO: U2.31 (IO19); also elsewhere on the board
/Display/MOSI: U2.30 (IO18); also elsewhere on the board
/Display/RES: U2.33 (IO21); also elsewhere on the board
/Display/SCK: U2.29 (IO5); also elsewhere on the board
/Display/SD_CS: S10.1; also elsewhere on the board
/Display/SD_Detect: U2.7 (IO35); also elsewhere on the board
/MCU ESP32/GPIO0: U2.25 (IO0); also elsewhere on the board
/MCU ESP32/RESET: C5.1, R23.2, S9.1 (A), S9.2 (B), U2.3 (EN); also elsewhere on the board
/MCU ESP32/RXD0: U2.34 (RXD0/IO3); also elsewhere on the board
/MCU ESP32/SCL: U2.36 (IO22); also elsewhere on the board
/MCU ESP32/SDA: U2.37 (IO23); also elsewhere on the board
/MCU ESP32/TCK: U2.16 (IO13); also elsewhere on the board
/MCU ESP32/TDI: U2.14 (IO12); also elsewhere on the board
/MCU ESP32/TDO: U2.23 (IO15); also elsewhere on the board
/MCU ESP32/TMS: S10.3; also elsewhere on the board
/MCU ESP32/TXD0: U2.35 (TXD0/IO1); also elsewhere on the board
GND: C3.2, C4.2, C5.2, D1.1 (K), S9.3 (C), S9.4 (D), S10.S1, S10.S2, U2.1 (GND), U2.15 (GND), U2.38 (GND), U2.39 (GND); also elsewhere on the board
unnamed: D1.2 (A), R22.2
unnamed: S10.2, U2.13 (IO14)


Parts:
R1, R3, R5, R7, R10, R12, R15, R17: R?; R_0603_1608Metric; not fitted
R2, R4, R6, R8, R11, R13, R16, R18: 2.2kΩ; R_0603; Overload Voltage (Max) 75V; Tolerance ±1%; Part 0603WAF2201T5E; LCSC C4190
R9, R14: 10kΩ; R_0603; Overload Voltage (Max) 75V; Tolerance ±1%; Part 0603WAF1002T5E; LCSC C25804
RV1, RV2, RV3, RV4, RV5, RV6, RV7, RV8: R_Potentiometer; Potentiometer_Bourns_TC33X_Vertical
S1, S2, S3, S4, S5, S6, S7, S8: TS29-1212-1-XX-300-D; SW_TS29-1212-1-XX-300-D_mod; PARTREV 1.01

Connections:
+3.3V: R2.2, R4.2, R6.2, R8.2, R11.2, R13.2, R16.2, R18.2, S6.1, S6.2, S7.1, S7.2, S8.1, S8.2; also elsewhere on the board
/Buttons and Switches/Horn: S7.3, S7.4; also elsewhere on the board
/Buttons and Switches/Minus: S1.3, S1.4; also elsewhere on the board
/Buttons and Switches/Plus: S2.3, S2.4; also elsewhere on the board
/Buttons and Switches/Reset: S3.3, S3.4; also elsewhere on the board
/Buttons and Switches/Set: S4.3, S4.4; also elsewhere on the board
/Buttons and Switches/Spare1: R9.1, S6.3, S6.4; also elsewhere on the board
/Buttons and Switches/Spare2: R14.1, S8.3, S8.4; also elsewhere on the board
/Buttons and Switches/Speak_In: S5.1, S5.2; also elsewhere on the board
/Buttons and Switches/Speak_Out: S5.3, S5.4; also elsewhere on the board
GND: R9.2, R14.2, S1.1, S1.2, S1.5, S2.1, S2.2, S2.5, S3.1, S3.2, S3.5, S4.1, S4.2, S4.5, S5.5, S6.5, S7.5, S8.5; also elsewhere on the board
unnamed: R1.1, RV1.1, S1.6
unnamed: R1.2, R2.1, RV1.2
unnamed: R3.1, RV2.1, S2.6
unnamed: R3.2, R4.1, RV2.2
unnamed: R5.1, RV3.1, S3.6
unnamed: R5.2, R6.1, RV3.2
unnamed: R7.1, RV4.1, S4.6
unnamed: R7.2, R8.1, RV4.2
unnamed: R10.1, RV5.1, S5.6
unnamed: R10.2, R11.1, RV5.2
unnamed: R12.1, RV6.1, S6.6
unnamed: R12.2, R13.1, RV6.2
unnamed: R15.1, RV7.1, S7.6
unnamed: R15.2, R16.1, RV7.2
unnamed: R17.1, RV8.1, S8.6
unnamed: R17.2, R18.1, RV8.2


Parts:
D6: ILI93_Display_Adafruit
R34, R35, R36: 10kΩ; R_0603; Overload Voltage (Max) 75V; Tolerance ±1%; Part 0603WAF1002T5E; LCSC C25804

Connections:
+3.3V: D6.2 (VCC), R34.1, R35.1; also elsewhere on the board
/Display/BackLight: D6.10 (BackLight); also elsewhere on the board
/Display/CS: D6.7 (DIS_CS), R36.1; also elsewhere on the board
/Display/DC: D6.8 (D/C), R35.2; also elsewhere on the board
/Display/MISO: D6.5 (DIS_MISO); also elsewhere on the board
/Display/MOSI: D6.6 (DIS_MOSI); also elsewhere on the board
/Display/RES: D6.9 (DIS_RESET); also elsewhere on the board
/Display/SCK: D6.4 (DIS_SCK); also elsewhere on the board
/Display/SD_CS: D6.11 (SD_CS), R34.2; also elsewhere on the board
/Display/SD_Detect: D6.12 (SD_Detect); also elsewhere on the board
GND: D6.1 (GND), R36.2; also elsewhere on the board


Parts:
C17, C19: 100nF; C_0603; Voltage Rated 50V; Tolerance ±10%; Part CC0603KRX7R9BB104; LCSC C14663
C18, C20: 1nF; C_0603; Voltage Rated 50V; Tolerance ±10%; Part CL10B102KB8NNNC; LCSC C1588
SW1, SW2: SW_SPDT; PinHeader_1x03_P2.54mm_Vertical

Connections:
+3.3V: C17.1, C19.1, SW1.1 (A), SW2.1 (A); also elsewhere on the board
/Connectors/Switch_IndL: C20.1, SW1.2 (B); also elsewhere on the board
/Connectors/Switch_IndR: C18.1, SW2.2 (B); also elsewhere on the board
GND: C17.2, C18.2, C19.2, C20.2, SW1.3 (C), SW2.3 (C); also elsewhere on the board


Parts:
C8, C9: 10uF; C_0805; Voltage Rated 25V; Tolerance ±10%; Part CL21A106KAYNNNE; LCSC C15850
U4: R-78E3.3-1.0; Converter_DCDC_RECOM_R-78E-0.5_THT

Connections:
+3.3V: C9.1, U4.3 (OUT); also elsewhere on the board
+12V: C8.1, U4.1 (IN); also elsewhere on the board
GND: C8.2, C9.2, U4.2 (GND); also elsewhere on the board

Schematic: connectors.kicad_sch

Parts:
J2: DriveController; CUI_CRJ027-1-TH; PARTREV 1.0
J3: 430450625; MOLEX_430450625; PARTREV H4
J4: Radio Enable; SAMESKY_SJ1-2503A; PARTREV 1.06
J5: ChassisBoard; CUI_CRJ027-1-TH; PARTREV 1.0
R19, R20, R42: R; R_0603_1608Metric; not fitted

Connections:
+3.3VA: J2.3; also elsewhere on the board
+12V: J3.1; also elsewhere on the board
/Buttons and Switches/Horn: J5.5; also elsewhere on the board
/Buttons and Switches/Minus: J2.8; also elsewhere on the board
/Buttons and Switches/Plus: J2.6; also elsewhere on the board
/Buttons and Switches/Reset: J2.7; also elsewhere on the board
/Buttons and Switches/Set: J2.4; also elsewhere on the board
/Buttons and Switches/Speak_In: J4.4; also elsewhere on the board
/Buttons and Switches/Speak_Out: J4.2, J4.3; also elsewhere on the board
/CAN_Transceiver/CAN_H: J3.4; also elsewhere on the board
/CAN_Transceiver/CAN_L: J3.5; also elsewhere on the board
/Connectors/LED_DriveLight: J5.8; also elsewhere on the board
/Connectors/LED_FrontLight: J5.7; also elsewhere on the board
/Connectors/LED_IndL: J5.4; also elsewhere on the board
/Connectors/LED_IndR: J5.1; also elsewhere on the board
/Connectors/Pedal_Left: J2.2; also elsewhere on the board
/Connectors/Pedal_Right: J2.1; also elsewhere on the board
/Connectors/RX: J3.3; also elsewhere on the board
/Connectors/Switch_IndL: J5.3; also elsewhere on the board
/Connectors/Switch_IndR: J5.2; also elsewhere on the board
/Connectors/TX: J3.6; also elsewhere on the board
GND: J3.2, J3.S1 (SHIELD1), J3.S2 (SHIELD2), J4.1, R19.1, R20.1, R42.1; also elsewhere on the board
GNDA: J2.5; also elsewhere on the board
unnamed: J2.S1 (SHIELD), R19.2
unnamed: J5.6, R42.2
unnamed: J5.S2 (SHIELD__1), R20.2

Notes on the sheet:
Modify Radio
No Ground Loop
Supply for Pedals

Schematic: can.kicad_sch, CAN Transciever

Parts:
C1, C2: 100nF; C_0603; Voltage Rated 50V; Tolerance ±10%; Part CC0603KRX7R9BB104; LCSC C14663
R21: 120Ω; R_0603; Overload Voltage (Max) 75V; Tolerance ±1%; Part 0603WAF1200T5E; LCSC C22787
U1: SN65HVD232; SOIC-8_3.9x4.9mm_P1.27mm

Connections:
+3.3V: C1.1, C2.1, U1.3 (VCC); also elsewhere on the board
/CAN_Transceiver/CAN_D: U1.1 (D); also elsewhere on the board
/CAN_Transceiver/CAN_H: R21.1, U1.7 (CANH); also elsewhere on the board
/CAN_Transceiver/CAN_L: R21.2, U1.6 (CANL); also elsewhere on the board
/CAN_Transceiver/CAN_R: U1.4 (R); also elsewhere on the board
GND: C1.2, C2.2, U1.2 (GND); also elsewhere on the board

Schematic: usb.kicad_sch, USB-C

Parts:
C10, C11: 100nF; C_0603; Voltage Rated 50V; Tolerance ±10%; Part CC0603KRX7R9BB104; LCSC C14663
C12: 1uF; C_0603; Voltage Rated 50V; Tolerance ±10%; Part CL10A105KB8NNNC; LCSC C15849
J6: Connector, USB-TYPE-C-16P; TYPE-C-SMD_HX-TYPE-C-16PIN; LCSC C2927039
Q1, Q2: MMBT5551L; SOT-23
R37, R38: 470Ω; R_0603; Overload Voltage (Max) 75V; Tolerance ±1%; Part 0603WAF4700T5E; LCSC C23179
R39, R40, R41: 10kΩ; R_0603; Overload Voltage (Max) 75V; Tolerance ±1%; Part 0603WAF1002T5E; LCSC C25804
U5: CH340C; SOIC-16_3.9x9.9mm_P1.27mm

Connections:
+3.3V: R41.1; also elsewhere on the board
/MCU ESP32/GPIO0: Q2.3 (C), R41.2; also elsewhere on the board
/MCU ESP32/RESET: C12.1, Q1.3 (C); also elsewhere on the board
/MCU ESP32/RXD0: R37.2; also elsewhere on the board
/MCU ESP32/TXD0: R38.2; also elsewhere on the board
DTR: Q2.2 (E), R39.1, U5.13 (~DTR)
GND: C10.2, C11.1, C12.2, J6.A12B1 (GND), J6.B12A1 (GND), J6.S1 (SHIELD), U5.1 (GND); also elsewhere on the board
unnamed: Q1.1 (B), R39.2
unnamed: Q2.1 (B), R40.2
unnamed: R38.1, U5.3 (RXD)
unnamed: R37.1, U5.2 (TXD)
unnamed: J6.A6 (D+), J6.B6 (D+), U5.5 (UD+)
unnamed: J6.A7 (D-), J6.B7 (D-), U5.6 (UD-)
unnamed: C10.1, U5.4 (V3)
unnamed: C11.2, J6.A9B4 (VBUS), J6.B9A4 (VBUS), U5.16 (VCC)
RTS: Q1.2 (E), R40.1, U5.14 (~RTS)

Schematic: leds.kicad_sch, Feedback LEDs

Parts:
D2: INDL; LED_D3.0mm
D3: DRIVELIGHT; LED_D3.0mm
D4: FRONTLIGHT; LED_D3.0mm
D5: INDR; LED_D3.0mm
R24, R25, R26, R27: 2.2kΩ; R_0603; Overload Voltage (Max) 75V; Tolerance ±1%; Part 0603WAF2201T5E; LCSC C4190
R28, R29, R30, R31: R?; R_0603_1608Metric; not fitted
RV9, RV10, RV11, RV12: R_Potentiometer; Potentiometer_Bourns_TC33X_Vertical

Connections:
/Connectors/LED_DriveLight: R25.2; also elsewhere on the board
/Connectors/LED_FrontLight: R26.2; also elsewhere on the board
/Connectors/LED_IndL: R24.2; also elsewhere on the board
/Connectors/LED_IndR: R27.2; also elsewhere on the board
GND: D2.1 (K), D3.1 (K), D4.1 (K), D5.1 (K); also elsewhere on the board
unnamed: D2.2 (A), R28.1, RV9.1
unnamed: D3.2 (A), R29.1, RV10.1
unnamed: D4.2 (A), R30.1, RV11.1
unnamed: D5.2 (A), R31.1, RV12.1
unnamed: R24.1, R28.2, RV9.2
unnamed: R25.1, R29.2, RV10.2
unnamed: R26.1, R30.2, RV11.2
unnamed: R27.1, R31.2, RV12.2



Board: 4 copper layers, 210.0 x 82.0 mm, 118 parts (8 on the bottom side), 87 nets.

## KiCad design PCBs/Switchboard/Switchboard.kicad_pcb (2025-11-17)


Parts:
G1: LOGO; SER_Logo
H1, H2, H3: MountingHole; MountingHole_3.2mm_M3_No_Copper
RV1: R_Potentiometer; P0915N-EC15BR10K_BIT
SW1: MC On/Off; SW_100SP1T1B1M2QEH
SW2: MC Dir; SW_100SP1T1B1M2QEH
SW3: FrontLight; SW_100SP1T1B1M2QEH
SW4: DriveLight; SW_100SP1T1B1M2QEH
SW5: RearView; SW_100SP1T1B1M2QEH
SW6: SpareCB; SW_100SP1T1B1M2QEH
SW7: DC On/Off; SW_100SP1T1B1M2QEH
SW8: AC On/Off; SW_100SP1T1B1M2QEH
SW9: SpareDC; SW_100SP1T1B1M2QEH

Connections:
+3.3V: RV1.3, SW1.1 (A), SW2.1 (A), SW3.1 (A), SW4.1 (A), SW5.1 (A), SW6.1 (A), SW9.1 (A); also elsewhere on the board
/Connectors/AC_Enable: SW8.2 (B); also elsewhere on the board
/Connectors/DC_Enable: SW7.2 (B); also elsewhere on the board
/Connectors/DriveLight: SW4.2 (B); also elsewhere on the board
/Connectors/FrontLight: SW3.2 (B); also elsewhere on the board
/Connectors/MC_Dir: SW2.2 (B); also elsewhere on the board
/Connectors/MC_OnOff: SW1.2 (B); also elsewhere on the board
/Connectors/Potentiometer: RV1.2; also elsewhere on the board
/Connectors/RearView: SW5.2 (B); also elsewhere on the board
/Connectors/SpareSwitch_CB: SW6.2 (B); also elsewhere on the board
/Connectors/SpareSwitch_DC: SW9.2 (B); also elsewhere on the board
GND: RV1.1, SW1.3 (C), SW2.3 (C), SW3.3 (C), SW4.3 (C), SW5.3 (C), SW6.3 (C), SW7.3 (C), SW8.3 (C), SW9.3 (C); also elsewhere on the board

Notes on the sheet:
Off 0V, On 3.3V
Off 0V, On pulled to 12V on ChassisBoard
0V - 3.3V


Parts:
J1: DriveController; CUI_CRJ027-1-TH; PARTREV 1.0
J2: ChassisBoard; CUI_CRJ027-1-TH; PARTREV 1.0
R1, R2, R3: R; R_0603_1608Metric; not fitted

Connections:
+3.3V: J1.3, J2.3; also elsewhere on the board
/Connectors/AC_Enable: J2.7; also elsewhere on the board
/Connectors/BreakLight: J1.7, J2.1
/Connectors/DC_Enable: J2.8; also elsewhere on the board
/Connectors/DriveLight: J2.4; also elsewhere on the board
/Connectors/FrontLight: J2.5; also elsewhere on the board
/Connectors/MC_Dir: J1.2; also elsewhere on the board
/Connectors/MC_OnOff: J1.1; also elsewhere on the board
/Connectors/Potentiometer: J1.8; also elsewhere on the board
/Connectors/RearView: J2.2; also elsewhere on the board
/Connectors/SpareSwitch_CB: J2.6; also elsewhere on the board
/Connectors/SpareSwitch_DC: J1.4; also elsewhere on the board
GND: R1.1, R2.1, R3.1; also elsewhere on the board
unnamed: J1.5, J1.6, R3.2
unnamed: J1.S2 (SHIELD__1), R2.2
unnamed: J2.S2 (SHIELD__1), R1.2

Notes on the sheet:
No Ground Loop

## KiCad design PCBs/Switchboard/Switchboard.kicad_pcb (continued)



Board: 4 copper layers, 83.0 x 54.0 mm, 19 parts (2 on the bottom side), 16 nets.

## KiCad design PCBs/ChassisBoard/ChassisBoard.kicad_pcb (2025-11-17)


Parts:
C25: C_Polarized; CP_Radial_D8.0mm_P5.00mm
H1, H2, H3, H4: MountingHole; MountingHole_3.2mm_M3_No_Copper
J1: Spare Input; PhoenixContact_MCV_1,5_2-G-3.5_1x02_P3.50mm_Vertical
J2: Deck1; PhoenixContact_MCV_1,5_7-G-3.5_1x07_P3.50mm_Vertical
J3: AC/DC Power; PhoenixContact_MCV_1,5_4-G-3.5_1x04_P3.50mm_Vertical
J4: Horn; PhoenixContact_MCV_1,5_2-G-3.5_1x02_P3.50mm_Vertical
J5: Spare; PhoenixContact_MCV_1,5_4-G-3.5_1x04_P3.50mm_Vertical
J6: Deck2; PhoenixContact_MCV_1,5_7-G-3.5_1x07_P3.50mm_Vertical
J9: Contactor; PhoenixContact_MCV_1,5_2-G-3.5_1x02_P3.50mm_Vertical
J10: Power Input; PhoenixContact_MCV_1,5_4-G-3.5_1x04_P3.50mm_Vertical

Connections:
+12V: C25.1, J10.1, J10.2; also elsewhere on the board
/Blinker Logic/ContactorAct: J6.3, J9.1; also elsewhere on the board
/Power/In11: J1.1; also elsewhere on the board
/Power/Out1: J4.2; also elsewhere on the board
/Power/Out2: J2.5; also elsewhere on the board
/Power/Out3: J2.4; also elsewhere on the board
/Power/Out4: J2.3; also elsewhere on the board
/Power/Out5: J2.2; also elsewhere on the board
/Power/Out6: J2.1; also elsewhere on the board
/Power/Out7: J5.2, J6.7; also elsewhere on the board
/Power/Out8: J3.2; also elsewhere on the board
/Power/Out9: J3.4; also elsewhere on the board
/Power/Out10: J6.6; also elsewhere on the board
/Power/Out11: J5.4, J6.5; also elsewhere on the board
/Power/Out12: J6.4; also elsewhere on the board
GND: C25.2, J1.2, J2.6, J2.7, J3.1, J3.3, J4.1, J5.1, J5.3, J6.1, J10.3, J10.4; also elsewhere on the board
unnamed: J6.2, J9.2

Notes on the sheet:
Off 0V, On 3.3V
Off 0V, On pulled to 12V
Off 0V, On 12V
Off 0V, On 3.3V@1Hz
Negative ~0V


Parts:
J7: AuxController; CUI_CRJ027-1-TH; PARTREV 1.0

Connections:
/Blinker Logic/IndL: J7.3; also elsewhere on the board
/Blinker Logic/IndL_1Hz: J7.4; also elsewhere on the board
/Blinker Logic/IndR: J7.2; also elsewhere on the board
/Blinker Logic/IndR_1Hz: J7.1; also elsewhere on the board
/Power/In1: J7.5; also elsewhere on the board
/Power/In6: J7.8; also elsewhere on the board
/Power/In10: J7.7; also elsewhere on the board
GND: J7.6, J7.S2 (SHIELD__1); also elsewhere on the board


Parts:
C3, C4, C6, C7, C8, C9, C11, C12, C13, C15, C16, C17, C26, C27, C28, C29, C30, C34: 100nF; C_0603; Voltage Rated 50V; Tolerance ±10%; Part CC0603KRX7R9BB104; LCSC C14663
R6, R7, R8, R9, R10, R11, R12, R13, R14, R31: 10kΩ; R_0603; Overload Voltage (Max) 75V; Tolerance ±1%; Part 0603WAF1002T5E; LCSC C25804
R15, R16: 2.2kΩ; R_0603; Overload Voltage (Max) 75V; Tolerance ±1%; Part 0603WAF2201T5E; LCSC C4190
U3, U5, U6: BTS724G; Infineon_SOIC-20W_7.6x12.8mm_P1.27mm

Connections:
+12V: C3.1, C26.1, C27.1, C28.1, C29.1, C30.1, U3.1 (VBB), U3.10 (VBB), U3.11 (VBB), U3.12 (VBB), U3.15 (VBB), U3.16 (VBB), U3.19 (VBB), U3.20 (VBB), U5.1 (VBB), U5.10 (VBB), U5.11 (VBB), U5.12 (VBB), U5.15 (VBB), U5.16 (VBB), U5.19 (VBB), U5.20 (VBB), U6.1 (VBB), U6.10 (VBB), U6.11 (VBB), U6.12 (VBB), U6.15 (VBB), U6.16 (VBB), U6.19 (VBB), U6.20 (VBB); also elsewhere on the board
/Blinker Logic/GreenLight_1Hz: R16.1; also elsewhere on the board
/Blinker Logic/IndL_1Hz: R7.1; also elsewhere on the board
/Blinker Logic/IndR_1Hz: R6.1; also elsewhere on the board
/Power/In1: R31.1; also elsewhere on the board
/Power/In4: R8.1; also elsewhere on the board
/Power/In5: R9.1; also elsewhere on the board
/Power/In6: R10.1; also elsewhere on the board
/Power/In7: R11.1; also elsewhere on the board
/Power/In8: R12.1; also elsewhere on the board
/Power/In9: R13.1; also elsewhere on the board
/Power/In10: R14.1; also elsewhere on the board
/Power/In11: R15.1; also elsewhere on the board
/Power/Out1: U3.18 (OUT1); also elsewhere on the board
/Power/Out2: U3.17 (OUT2); also elsewhere on the board
/Power/Out3: U3.14 (OUT3); also elsewhere on the board
/Power/Out4: U3.13 (OUT4); also elsewhere on the board
/Power/Out5: U5.18 (OUT1); also elsewhere on the board
/Power/Out6: U5.17 (OUT2); also elsewhere on the board
/Power/Out7: U5.14 (OUT3); also elsewhere on the board
/Power/Out8: U5.13 (OUT4); also elsewhere on the board
/Power/Out9: U6.18 (OUT1); also elsewhere on the board
/Power/Out10: U6.17 (OUT2); also elsewhere on the board
/Power/Out11: U6.14 (OUT3); also elsewhere on the board
/Power/Out12: U6.13 (OUT4); also elsewhere on the board
GND: C3.2, C4.2, C6.2, C7.2, C8.2, C9.2, C11.2, C12.2, C13.2, C15.2, C16.2, C17.2, C26.2, C27.2, C28.2, C29.2, C30.2, C34.2, U3.2 (GND1/2), U3.6 (GND3/4), U5.2 (GND1/2), U5.6 (GND3/4), U6.2 (GND1/2), U6.6 (GND3/4); also elsewhere on the board
unnamed: C34.1, R31.2, U3.3 (IN1)
unnamed: C6.1, R6.2, U3.5 (IN2)
unnamed: C7.1, R7.2, U3.7 (IN3)
unnamed: C8.1, R8.2, U3.9 (IN4)
unnamed: C4.1, R9.2, U5.3 (IN1)
unnamed: C9.1, R10.2, U5.5 (IN2)
unnamed: C11.1, R11.2, U5.7 (IN3)
unnamed: C12.1, R12.2, U5.9 (IN4)
unnamed: C13.1, R13.2, U6.3 (IN1)
unnamed: C15.1, R14.2, U6.5 (IN2)
unnamed: C16.1, R15.2, U6.7 (IN3)
unnamed: C17.1, R16.2, U6.9 (IN4)


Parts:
C1: 1uF; C_0603; Voltage Rated 50V; Tolerance ±10%; Part CL10A105KB8NNNC; LCSC C15849
C2: 10nF; C_0603; Voltage Rated 50V; Tolerance ±10%; Part 0603B103K500NT; LCSC C57112
C10, C18, C19, C20, C21, C22, C23, C24: 100nF; C_0603; Voltage Rated 50V; Tolerance ±10%; Part CC0603KRX7R9BB104; LCSC C14663
R2: 680kΩ; R_0603; Overload Voltage (Max) 75V; Tolerance ±1%; Part 0603WAF6803T5E; LCSC C25822
R3: 68kΩ; R_0603; Overload Voltage (Max) 75V; Tolerance ±1%; Part 0603WAF6802T5E; LCSC C23231
R4, R17: 8.2kΩ; R_0603; Overload Voltage (Max) 75V; Tolerance ±1%; Part 0603WAF8201T5E; LCSC C25981
R5, R18: 3.3kΩ; R_0603; Overload Voltage (Max) 75V; Tolerance ±1%; Part 0603WAF3301T5E; LCSC C22978
U1: NE555D; SOIC-8_3.9x4.9mm_P1.27mm
U2, U4: SN74LVC2G08DCTR; VSSOP-8_2.3x2mm_P0.5mm_modified
U7: SN74LVC2G04DBVR; SOT-23-6

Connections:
1Hz: R4.2, R5.1, U2.1 (1A), U4.1 (1A), U4.5 (2A)
+3.3V: C18.1, C19.1, C20.1, C21.1, C22.1, C23.1, U2.8 (VCC), U4.8 (VCC), U7.5 (VCC); also elsewhere on the board
+12V: C10.1, C24.1, R3.2, U1.4 (R), U1.8 (VCC); also elsewhere on the board
/Blinker Logic/ContactorAct: R17.1; also elsewhere on the board
/Blinker Logic/GreenLight_1Hz: U2.7 (1Y); also elsewhere on the board
/Blinker Logic/IndL: U4.6 (2B); also elsewhere on the board
/Blinker Logic/IndL_1Hz: U4.3 (2Y); also elsewhere on the board
/Blinker Logic/IndR: U4.2 (1B); also elsewhere on the board
/Blinker Logic/IndR_1Hz: U4.7 (1Y); also elsewhere on the board
GND: C1.2, C2.2, C10.2, C18.2, C19.2, C20.2, C21.2, C22.2, C23.2, C24.2, R5.2, R18.2, U1.1 (GND), U2.4 (GND), U4.4 (GND), U7.2 (GND); also elsewhere on the board
unnamed: C2.1, U1.5 (CV)
unnamed: R2.2, R3.1, U1.7 (DIS)
unnamed: R4.1, U1.3 (Q)
unnamed: C1.1, R2.1, U1.2 (TR), U1.6 (THR)
unnamed: U2.2 (1B), U7.6 (1Y)
unnamed: R17.2, R18.1, U7.1 (1A)

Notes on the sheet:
1Hz Signal Generator
Greenlight@1Hz when contactor disengaged
AND-Logic


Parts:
J8: SwitchBoard; CUI_CRJ027-1-TH; PARTREV 1.0
R1, R20: 10kΩ; R_0603; Overload Voltage (Max) 75V; Tolerance ±1%; Part 0603WAF1002T5E; LCSC C25804

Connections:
+3.3V: J8.3; also elsewhere on the board
+12V: R1.1, R20.1; also elsewhere on the board
/Power/In4: J8.1; also elsewhere on the board
/Power/In5: J8.2; also elsewhere on the board
/Power/In6: J8.4; also elsewhere on the board
/Power/In7: J8.6; also elsewhere on the board
/Power/In8: J8.8, R20.2; also elsewhere on the board
/Power/In9: J8.7, R1.2; also elsewhere on the board
/Power/In10: J8.5; also elsewhere on the board
GND: J8.S2 (SHIELD__1); also elsewhere on the board


Board: 4 copper layers, 90.0 x 66.0 mm, 70 parts (0 on the bottom side), 50 nets.

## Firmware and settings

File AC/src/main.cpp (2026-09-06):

/*
 *  SER - Solar Car Control System - Main Routine for setting up tasks,
 * initialize devices, ..
 *
 * clang style:
 *    ../extras/format.sh
 */
#ifndef ARDUINO
#define ARDUINO 10805
#endif

// project variables
#include <sdkconfig.h>

// definitions
#include "../lib/definitions.h"
#include <global_definitions.h>
// standard libraries
#include <Streaming.h>
#include <fmt/core.h>
#include <fmt/printf.h>
#include <iostream>
#include <stdio.h>
#include <stdlib.h>
#include <string>
// Arduino
#include <Arduino.h>
#include <SoftwareSerial.h>
// FreeRTOS
#include <freertos/FreeRTOS.h>
#include <freertos/FreeRTOSConfig.h>
#include <freertos/semphr.h>
#include <freertos/task.h>
// local includes
#include <AbstractTask.h>
// local components
#include <CANBus.h>
#include <CarControl.h>
#include <CarState.h>
#include <CarStateRadio.h>
#include <CmdHandler.h>
#include <Console.h>
#include <DAC.h>
#include <Display.h>
#include <DriverDisplay.h>
#include <EngineerDisplay.h>
#include <GPIO.h>
#include <I2CBus.h>
#include <IOExt.h>
#include <OneWire.h>
#include <OneWireBus.h>
#include <RTC_SER.h>
#include <SDCard.h>
#include <SPIBus.h>
#include <Serial.h>
#include <System.h>

#include <esp_task_wdt.h>

// #include <Wire.h>
#include <array>
// #include <vector>

// add C linkage definition
extern "C" {
void app_main(void);
}

using namespace std;

int base_offset_suspend = 10;
bool dacInited = false;
bool SystemInited = false;
bool SystemJustInited = true;
uint64_t life_sign = 0;

CANBus canBus;
CarControl carControl;
CarState carState;
CarStateRadio carStateRadio;
CmdHandler cmdHandler;
Console console;
DAC dac;
DriverDisplay driverDisplay;
EngineerDisplay engineerDisplay;
GPInputOutput gpio;
I2CBus i2cBus;
IOExt ioExt;
SDCard sdCard;
SPIBus spiBus;
Uart uart;
GlobalTime globalTime = GlobalTime(&i2cBus);

static void canBusTask(void *pvParams) { canBus.task(pvParams); }
static void carControlTask(void *pvParams) { carControl.task(pvParams); }
static void cmdHandlerTask(void *pvParams) { cmdHandler.task(pvParams); }
static void engineerDisplayTask(void *pvParams) { engineerDisplay.task(pvParams); }
static void driverDisplayTask(void *pvParams) { driverDisplay.task(pvParams); }
static void ioExtTask(void *pvParams) { ioExt.task(pvParams); }
auto compiletime = RtcDateTime(__DATE__, __TIME__);

// Adafruit_ILI9341 ili9341 = Adafruit_ILI9341(SPI_CS_TFT, SPI_DC, SPI_MOSI, SPI_CLK, SPI_RST, SPI_MISO);
Adafruit_ILI9341 ili9341 = Adafruit_ILI9341(&(spiBus.spi), SPI_DC, SPI_CS_TFT, SPI_RST);
Display display = Display(&ili9341);

void app_main(void) {
  string msg;
  carStateRadio.verboseModeRadioSend = false;

  // init console IO and radio console
  // msg = uart.init();
  msg = uart.init_t(1, 20, 1000, base_offset_suspend + 100);
  console << NL << msg << NL;
  delay(1000);
  console << NL << "------------------------------------------------------------" << NL;
  console << "esp32dev + free RTOS" << NL;
  console << "Solar Energy Car Racers SER4 Controller: v" << VERSION << ", build time: " << __DATE__ << " " << __TIME__ << NL;
  console << "ARDUINO:              " << ARDUINO << NL;
  console << "Compile Mode:         " << "AuxiliaryController (AC)" << NL;
  console << "Main running on core: " << xPortGetCoreID() << NL;
  console << "------------------------------------------------------------" << NL;
  chip_info();
  console << "------------------------------------------------------------" << NL;
  console << "-- gpio pin settings ---------------------------------------" << NL;
  msg = gpio.init();
  delay(200);
  console << msg << NL;
  // init buses
  console << "-- init bus systems ----------------------------------------" << NL;
  msg = spiBus.init();
  console << msg << NL;
  msg = i2cBus.init();
  console << msg << NL;
  i2cBus.verboseModeI2C = false;
  delay(200);

  std::array<std::string, 7> wd = {"Sun", "Mon", "Tue", "Wed", "Thu", "Fri", "Sat"}; // todo: rm
  console << fmt::format("main.o compiletime: {}:{}:{}  {}-{}-{} ({})\n", compiletime.Hour(), compiletime.Minute(), compiletime.Second(),
                         compiletime.Day(), compiletime.Month(), compiletime.Year(), wd[compiletime.DayOfWeek()]);
  int RTC_err = globalTime.init(DS1307SquareWaveOut_Low, 1);
  console << "RTC init errorcode: " << RTC_err << "\n";
  bool rtc_valid = globalTime.rtc_datetime_valid();
  uint8_t rtc_last_error = globalTime.rtc_last_error();
  if (rtc_valid) {
    console << "RTC status: datetime valid (backup domain OK).\n";
  } else {
    console << "RTC status: datetime invalid (possible backup battery loss or uninitialized clock), LastError=" << (int)rtc_last_error
            << "\n";
  }
  console << "RTC time: " << globalTime.strTime("%H:%M:%S %Y-%m-%d (%a)") << "\n";
  carState.init_values();
  // sleep(5);
  // console << "time 5s: " << globalTime.strTime("%H:%M:%S %Y-%m-%d (%a)") << "\n";
  // sleep(60);
  // console << "time 5s: " << globalTime.strTime("%H:%M:%S %Y-%m-%d (%a)") << "\n";

  //------------------------------------------------------------
  // Global Display
  msg = display.init();
  console << msg << NL;
  display.clear_screen(0xffff);
  display.print("Start AC Init Procedure:\n\n");

  //------------------------------------------------------------
  // CAN Bus
  msg = canBus.init_t(0, 24, 10000, base_offset_suspend + 0);
  console << msg << NL;
  canBus.verboseModeCanIn = false;
  canBus.verboseModeCanAddr = false;
  canBus.verboseModeCanInNative = false;
  canBus.verboseModeCanOut = false;
  canBus.verboseModeCanOutNative = false;
  canBus.verboseModeCanBusLoad = false;
  console << "[  ] " << canBus.getName() << " create task ..." << NL;
  xTaskCreatePinnedToCore(canBusTask,             /* task function. */
                          canBus.getInfo(),       /* name of task. */
                          canBus.getStackSize(),  /* stack size of task */
                          NULL,                   /* parameter of the task */
                          canBus.getPriority(),   /* priority of the task */
                          canBus.getTaskHandle(), /* task handle to keep track of created task */
                          canBus.getCoreId());    /* pin task to core id */
  msg = canBus.report_task_init();
  console << msg << NL;
  display.print(msg + "\n");
  // vTaskDelay(10);

  //------------------------------------------------------------
  // CMD Handler
  msg = cmdHandler.init_t(1, 1, 10000, base_offset_suspend + 300);
  console << msg << NL;
  console << "[  ] " << cmdHandler.getName() << " create task ..." << NL;
  xTaskCreatePinnedToCore(cmdHandlerTask,             /* task function. */
                          cmdHandler.getInfo(),       /* name of task. */
                          cmdHandler.getStackSize(),  /* stack size of task */
                          NULL,                       /* parameter of the task */
                          cmdHandler.getPriority(),   /* priority of the task */
                          cmdHandler.getTaskHandle(), /* task handle to keep track of created task */
                          cmdHandler.getCoreId());    /* pin task to core id */
  msg = cmdHandler.report_task_init();
  console << msg << NL;
  display.print(msg + "\n");
  // vTaskDelay(10);

  //------------------------------------------------------------
  // Engineer Display
  engineerDisplay.verboseModeEngineer = false;
  msg = engineerDisplay.init_t(1, 1, 10000, base_offset_suspend + 20);
  console << msg << NL;
  console << "[  ] " << engineerDisplay.getName() << " create task ..." << NL;
  xTaskCreatePinnedToCore(engineerDisplayTask,             /* task function. */
                          engineerDisplay.getInfo(),       /* name of task. */
                          engineerDisplay.getStackSize(),  /* stack size of task */
                          NULL,                            /* parameter of the task */
                          engineerDisplay.getPriority(),   /* priority of the task */
                          engineerDisplay.getTaskHandle(), /* task handle to keep track of created task */
                          engineerDisplay.getCoreId());    /* pin task to core id */
  msg = engineerDisplay.report_task_init();
  console << msg << NL;
  display.print(msg + "\n");
  // vTaskDelay(10);

  //------------------------------------------------------------
  // Driver Display
  driverDisplay.verboseModeDriver = false;
  msg = driverDisplay.init_t(1, 1, 10000, base_offset_suspend + 20);
  console << msg << NL;
  console << "[  ] " << driverDisplay.getName() << " create task ..." << NL;
  xTaskCreatePinnedToCore(driverDisplayTask,             /* task function. */
                          driverDisplay.getInfo(),       /* name of task. */
                          driverDisplay.getStackSize(),  /* stack size of task */
                          NULL,                          /* parameter of the task */
                          driverDisplay.getPriority(),   /* priority of the task */
                          driverDisplay.getTaskHandle(), /* task handle to keep track of created task */
                          driverDisplay.getCoreId());    /* pin task to core id */
  msg = driverDisplay.report_task_init();
  console << msg << NL;
  display.print(msg + "\n");
  // vTaskDelay(10);

  //------------------------------------------------------------
  // Car Control AC
  msg = carControl.init_t(1, 10, 10000, base_offset_suspend + 10);
  console << msg << NL;
  carControl.verboseModeCarControl = false;
  carControl.verboseModeCarControlDebug = false;
  console << "[  ] " << carControl.getName() << " create task ..." << NL;
  xTaskCreatePinnedToCore(carControlTask,             /* task function. */
                          carControl.getInfo(),       /* name of task. */
                          carControl.getStackSize(),  /* stack size of task */
                          NULL,                       /* parameter of the task */
                          carControl.getPriority(),   /* priority of the task */
                          carControl.getTaskHandle(), /* task handle to keep track of created task */
                          carControl.getCoreId());    /* pin task to core id */
  msg = carControl.report_task_init();
  console << msg << NL;
  display.print(msg + NL);
  // vTaskDelay(10);

  //------------------------------------------------------------
  // SC card
  msg = sdCard.init();
  console << msg << NL;
  display.print(msg + NL);
  //--- SD card available
  if (sdCard.isMounted()) {
    carState.initalize_config();
    console << carState.print("State after reading " + string(FILENAME_SER6CONFIG)) << NL;
    sdCard.check_log_file();
    //------from now config ini values can be used
  } else {
    console << "WARN: Skip config read from SD, card not mounted." << NL;
  }
  
  // DAC (PWM)
  msg = dac.init();
  console << msg << NL;
  dac.verboseModeDAC = false;
  // vTaskDelay(10);
 
  SystemInited = true;
  
  dac.set_pot(carState.Backlight);  
  
  //------------------------------------------------------------
  // IOExt AC
  msg = ioExt.init_t(1, 10, 4000, base_offset_suspend + 20);
  console << msg << NL;
  ioExt.verboseModeDIn = false;
  ioExt.verboseModeDInHandler = false;
  ioExt.verboseModeDOut = false;
  console << "[  ] " << ioExt.getName() << " create task ..." << NL;
  xTaskCreatePinnedToCore(ioExtTask,             /* task function. */
                          ioExt.getInfo(),       /* name of task. */
                          ioExt.getStackSize(),  /* stack size of task */
                          NULL,                  /* parameter of the task */
                          ioExt.getPriority(),   /* priority of the task */
                          ioExt.getTaskHandle(), /* task handle to keep track of created task */
                          ioExt.getCoreId());    /* pin task to core id */
  msg = ioExt.report_task_init();
  console << msg << NL;
  display.print(msg + "\n");
  // vTaskDelay(10);

  dac.set_pot(carState.Backlight);  
  
  stringstream ss;
  ss << NL;
  ss << "----------------------------------------------------" << NL;
  ss << "Initialization ready as AuxiliaryController" << NL;
  ss << fmt::format("- i2cBus.verboseModeI2C              = {}", i2cBus.verboseModeI2C) << NL;
  // ss << fmt::format("- canBus.verboseModeCanIn            = {}", canBus.verboseModeCanIn) << NL;
  // ss << fmt::format("-        verboseModeCanInAddr        = {}", canBus.verboseModeCanAddr) << NL;
  // ss << fmt::format("-        verboseModeCanInNative      = {}", canBus.verboseModeCanInNative) << NL;
  // ss << fmt::format("-        verboseModeCanOut           = {}", canBus.verboseModeCanOut) << NL;
  // ss << fmt::format("-        verboseModeCanOutNative     = {}", canBus.verboseModeCanOutNative) << NL;
  // ss << fmt::format("-        verboseModeCanBusLoad       = {}", canBus.verboseModeCanBusLoad) << NL;
  // ss << fmt::format("- carControl.verboseModeCC           = {}", carControl.verboseModeCarControl) << NL;
  // ss << fmt::format("-            verboseModeCCDebug      = {}", carControl.verboseModeCarControlDebug) << NL;
  // ss << fmt::format("- engineerDisplay.verboseModeED      = {}", engineerDisplay.verboseModeEngineer) << NL;
  // ss << fmt::format("- driverDisplay.verboseModeDD        = {}", driverDisplay.verboseModeDriver) << NL;
  // ss << fmt::format("- carStateRadio.verboseModeRadioSend = {}", carStateRadio.verboseModeRadioSend) << NL;
  // ss << fmt::format("- sdCard.verboseModeSdCard           = {}", sdCard.verboseModeSdCard) << NL;
  ss << "----------------------------------------------------" << NL;
  // vTaskDelay(10);
  console << ss.str();
  // display.print(ss.str());
  //--let the bootscreen visible for a moment ------------------
  display.print("\nWaiting for start of life system: ");
  int waitAtConsoleView = 3;
  while (waitAtConsoleView-- > 0) {
    display.print(to_string(waitAtConsoleView));
    delay(1000);
    display.print("-");
  }
  console << NL;
  display.print("start\n");
  display.set_DisplayStatus(DISPLAY_STATUS::DRIVER_SETUP);

  esp_task_wdt_init(3600 * 48, false);
  // esp_task_wdt_init(5, false);
}

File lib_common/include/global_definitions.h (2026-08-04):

/*
 * Global definitions (pinout, device settings, ..)
 */
#ifndef GLOBAL_DEFINITIONS_H
#define GLOBAL_DEFINITIONS_H

//#define VERSION "$GIT_BRANCH_$GIT_COMMIT_HASH"
#define VERSION "6.0.0"

#define NL "\n"

#define CAN_SPEED 125E3 // CAN Speed 125 kb/s
// #define CAN_SPEED 500E3 // CAN Speed 500 kb/s
#define CAN_RX_BUFFER_SIZE 4000
#define CAN_TASK_WAIT 50
// CRITICAL_CAN_STALE_TIMEOUT_MS must be greater then the expected interval between 
// packets of critical CAN IDs, otherwise stale warnings will be triggered during 
// normal operation. Minimal CAN packet frequncy is determined by LIFESIGN_FREQUENCY_MS,
// which is e.g. 500ms, so CRITICAL_CAN_STALE_TIMEOUT_MS should be >500ms to avoid false positives.
#define CRITICAL_CAN_STALE_TIMEOUT_MS 700
#define LIFESIGN_FREQUENCY_MS 500

// #define MC_BASE_ADDR 0x500
#define MPPT1_BASE_ADDR 0x600
#define MPPT2_BASE_ADDR 0x610
#define MPPT3_BASE_ADDR 0x620
#define MPPT4_BASE_ADDR 0x630
#define AC_BASE_ADDR 0x650
#define DC_BASE_ADDR 0x660
#define BMS_BASE_ADDR 0x700

/* CAN Frame max ages
 *  ------------------
 *  in ms
 *  0 = update every time
 *  -1 = ignore frames
 *  BMS
 */
#define MAXAGE_BMU_HEARTBEAT 0
#define MAXAGE_CMU_TEMP 0
#define MAXAGE_CMU_VOLTAGES 0
#define MAXAGE_PACK_SOC 0
#define MAXAGE_BALANCE_SOC 5000
#define MAXAGE_CHARGER_CONTROL 0
#define MAXAGE_PRECHARGE_STATUS 0
#define MAXAGE_MIN_MAX_U_CELL 1000
#define MAXAGE_MIN_MAX_T_CELL 0
#define MAXAGE_PACK_VOLTAGE 500
#define MAXAGE_PACK_STATUS 0
#define MAXAGE_PACK_FAN_STATUS 0
#define MAXAGE_EXT_PACK_STATUS 0

/*
 *  MPPTs
 */
#define MAXAGE_MPPT_INPUT 0
#define MAXAGE_MPPT_OUTPUT 0
#define MAXAGE_MPPT_TEMP 5000
#define MAXAGE_MPPT_AUX_POWER 0
#define MAXAGE_MPPT_LIMITS 0
#define MAXAGE_MPPT_STATUS 0
#define MAXAGE_MPPT_POWER_CONN 5000

#define MAXAGE_MC_S 0
#define MAXAGE_MC_S2 1000
#define MAXAGE_MC_S3 1000
#define MAXAGE_MC_S4 0
#define MAXAGE_MC_S5 0


const int MAX_ACCELERATION_DISPLAY_VALUE = 97; // absolute of minimal or maximal value for acceleration scaling

/*
 * Define wich version of printed board layouts are used
 * (possibility to use older test boards too)
 */
#define STEERINGWHEEL_BOARD_V1 false
#define STEERINGWHEEL_BOARD_V2 true

#endif // GLOBAL_DEFINITIONS_H

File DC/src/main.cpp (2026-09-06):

/*
 *  SER - Solar Car Control System - Main Routine for setting up tasks,
 * initialize devices, ..
 *
 * clang style:
 *    ../extras/format.sh
 */
#ifndef ARDUINO
#define ARDUINO 10805
#endif

// project variables
#include <sdkconfig.h>

// definitions
#include "../lib/definitions.h"
#include <global_definitions.h>
// standard libraries
#include <Streaming.h>
#include <fmt/core.h>
#include <fmt/printf.h>
#include <iostream>
#include <stdio.h>
#include <stdlib.h>
#include <string>
// Arduino
#include <Arduino.h>
#include <SoftwareSerial.h>
// FreeRTOS
#include <freertos/FreeRTOS.h>
#include <freertos/FreeRTOSConfig.h>
#include <freertos/semphr.h>
#include <freertos/task.h>
// local includes
#include <AbstractTask.h>
// local components
#include <ADC_SER.h>
#include <CANBus.h>
#include <CarControl.h>
#include <CmdHandler.h>
#include <Console.h>
#include <ConstSpeed.h>
#include <DAC.h>
#if RTC_ON
#include <ESP32Time.h>
#endif
#include <GPIO.h>
#include <I2CBus.h>
#include <IOExt.h>
#include <OneWire.h>
// #include <SPIBus.h>
#include <Serial.h>
#include <System.h>

#include <ESP32_PWM.h>
#include <esp_task_wdt.h>

// add C linkage definition
extern "C" {
void app_main(void);
}

using namespace std;

int base_offset_suspend = 10;
bool SystemInited = false;
bool SystemJustInited = true;
bool adcInited = false;
bool dacInited = false;
uint64_t life_sign = 0;

ADC adc;
CANBus canBus;
CarControl carControl;
CarState carState;
CmdHandler cmdHandler;
Console console;
ConstSpeed constSpeed;
DAC dac;
GPInputOutput gpio; // I2C Interrupts, GPInputOutput pin settings
I2CBus i2cBus;
IOExt ioExt;
// SPIBus spiBus;
Uart uart; // SERIAL

static void adcTask(void *pvParams) { adc.task(pvParams); }
static void canBusTask(void *pvParams) { canBus.task(pvParams); }
static void carControlTask(void *pvParams) { carControl.task(pvParams); }
static void cmdHandlerTask(void *pvParams) { cmdHandler.task(pvParams); }
static void constSpeedTask(void *pvParams) { constSpeed.task(pvParams); }
static void ioExtTask(void *pvParams) { ioExt.task(pvParams); }

// //--LEDC------------------------------------------------
// #include "driver/ledc.h"
// #include "esp_err.h"
// #include "esp_pm.h"
// #include "sdkconfig.h"

// #define LEDC_TIMER LEDC_TIMER_0
// #define LEDC_MODE LEDC_LOW_SPEED_MODE
// #define LEDC_OUTPUT_IO (2) // Define the output GPIO
// #define LEDC_CHANNEL LEDC_CHANNEL_0
// #define LEDC_DUTY_RES LEDC_TIMER_13_BIT // Set duty resolution to 13 bits
// #define LEDC_DUTY (4096)                // Set duty to 50%. (2 ** 13) * 50% = 4096
// #if CONFIG_PM_ENABLE
// #define LEDC_CLK_SRC LEDC_USE_RC_FAST_CLK // choose a clock source that can maintain during light sleep
// #define LEDC_FREQUENCY (400)              // Frequency in Hertz. Set frequency at 400 Hz
// #else
// #define LEDC_CLK_SRC LEDC_AUTO_CLK
// #define LEDC_FREQUENCY (4000) // Frequency in Hertz. Set frequency at 4 kHz
// #endif
// static void example_ledc_init();
// //------------------------------------------------LEDC--
void app_main(void) {
  string msg;
  // init console IO and radio console
  msg = uart.init();
  console << NL << msg << NL;
  delay(1000);
  console << NL << "------------------------------------------------------------" << NL;
  console << "esp32dev + free RTOS" << NL;
  console << "Solar Energy Car Racers SER4 Controller: v" << VERSION << ", build time: " << __DATE__ << " " << __TIME__ << NL;
  console << "ARDUINO:              " << ARDUINO << NL;
  console << "Compile Mode:         " << "DriveController (DC)" << NL;
  console << "Main running on core: " << xPortGetCoreID() << NL;
  console << "------------------------------------------------------------" << NL;
  // init arduino library
  // initArduino();
  console << "------------------------------------------------------------" << NL;
  chip_info();
  console << "------------------------------------------------------------" << NL;
  console << "-- gpio pin settings ---------------------------------------" << NL;
  msg = gpio.init();
  delay(200);
  console << msg << NL;
  // init buses
  console << "-- init bus systems ----------------------------------------" << NL;
  // msg = spiBus.init();
  // console << msg << NL;
  // msg = oneWireBus.init();
  // console << msg << NL;
  msg = i2cBus.init();
  console << msg << NL;
  i2cBus.verboseModeI2C = false;
  delay(200);

  // Engineer Display
  // NOT available on DC
  // CAN Bus
  msg = canBus.init_t(0, 24, 10000, base_offset_suspend + 0);
  console << msg << NL;
  canBus.verboseModeCanIn = false;
  canBus.verboseModeCanAddr = false;
  canBus.verboseModeCanInNative = false;
  canBus.verboseModeCanOut = false;
  canBus.verboseModeCanOutNative = false;
  console << "[  ] Create " << canBus.getName() << " task ...";
  xTaskCreatePinnedToCore(canBusTask,             /* task function. */
                          canBus.getInfo(),       /* name of task. */
                          canBus.getStackSize(),  /* stack size of task */
                          NULL,                   /* parameter of the task */
                          canBus.getPriority(),   /* priority of the task */
                          canBus.getTaskHandle(), /* task handle to keep track of created task */
                          canBus.getCoreId());    /* pin task to core id */
  console << " done." << NL;
  msg = canBus.report_task_init();
  console << msg << NL;
  // vTaskDelay(10);
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

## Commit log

2025-11-17 initial init: Controllers, PCBs, docs, datasheets
    [AuxController.kicad_pcb, AuxController.kicad_sch, ChassisBoard.kicad_pcb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]
2026-04-27 MPPT configuration files
    For SN136, SN139, SN140 with 130.2V
2026-05-03 working PWM, to fis: acc decc missmatch
2026-05-26 change break pedal logic, add ili9341 PCB picture, clean up
2026-05-27 PWM 1kHz, cleanup duplicate CanBusHandler
2026-06-07 CAN: migrate to TWAI and harden critical AC/DC reliability
    - switch CANBus transport from arduino-CAN to ESP-IDF TWAI
    - add critical staleness watchdog for 0x650/0x660/0x661
    - add critical TX lane and sequence-gap detection
    - add overwrite/failure observability counters and retries
    - remove arduino-CAN deps and update analysis docs
    [CANBus.cpp, CANBusHandlerAC.cpp, global_definitions.h]
2026-06-08 cd card wo crashes but not mountingnew can library
    [sd_diskio.cpp]
2026-06-11 add fixed library files
    [SER4DATA-0.CSV, SER4DATA-2026-06-11_22-30.CSV, SER4TELE.CSV]
2026-06-11 add possibility to print/tail files from sd-card to console
2026-07-05 fix spelling, show mount state in bootscreen, switch radio cmd off
    [CANBus.cpp, main.cpp]
2026-07-05 feat: driverinfo at bottom of screen
2026-07-11 new DriverDisplay with time
2026-08-02 fix: sd card mountabel again
    [main.cpp]
2026-08-03 introduce GlideMode (0...7) and drivername, improve startup messsage
2026-08-04 feat: add MPPT4, add Bat temp in driver display
2026-08-06 switch on all CAN packets for parse, modify EngineeringDisplay
2026-08-07 add comments for radio
    [SER4DATA_2026_08_06.CSV]
2026-08-07 feat: switch to drive backwards disables constant mode
2026-08-09 fix rtc and log file write
    [RTC_SER.cpp, main.cpp]
2026-08-31 fix: brake light (pedal and deceleration)
2026-09-01 fix: brake pedal does not overwirte graeter decceleration
2026-09-02 improve: speed calibration
2026-09-25 battery fan control by temp
